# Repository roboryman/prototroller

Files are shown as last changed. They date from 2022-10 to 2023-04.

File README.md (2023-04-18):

<p align="center">
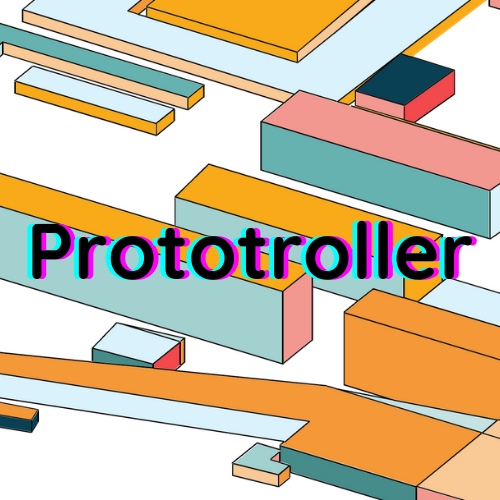
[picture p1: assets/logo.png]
  
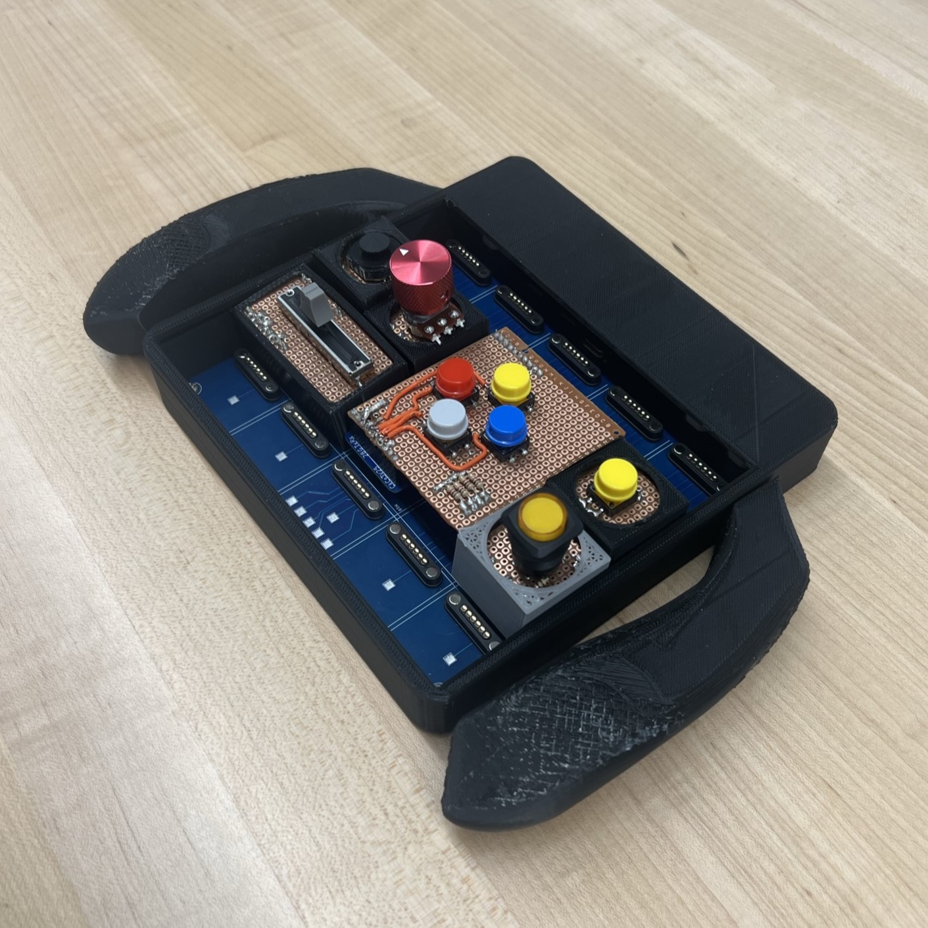
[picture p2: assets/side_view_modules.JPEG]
  
</p>

## About
The Prototroller is a ***modular*** controller that is full-stack, feature-rich, responsive, and robust. The controller could be used for any HID-compliant purpose, but we focus on developing hot-swappable modules that can form customizable gamepads.

A potential use case is general hardware level remapping for quality of life. Another is rapidly prototyping different controller layouts for games or simulations in development.

Our team consists of 5 members:
- Yu-yang Hsieh
- Britton McLeavy
- Caleb O'Malley
- Merrick Ryman
- Evan Zhang

This project is developed in conjunction with the UF CpE Capstone program (Fall 2022 - Spring 2023). This project is self-funded. As such, donations are appreciated in this educational pursuit (hardware is not cheap nowadays).

<p align="center">
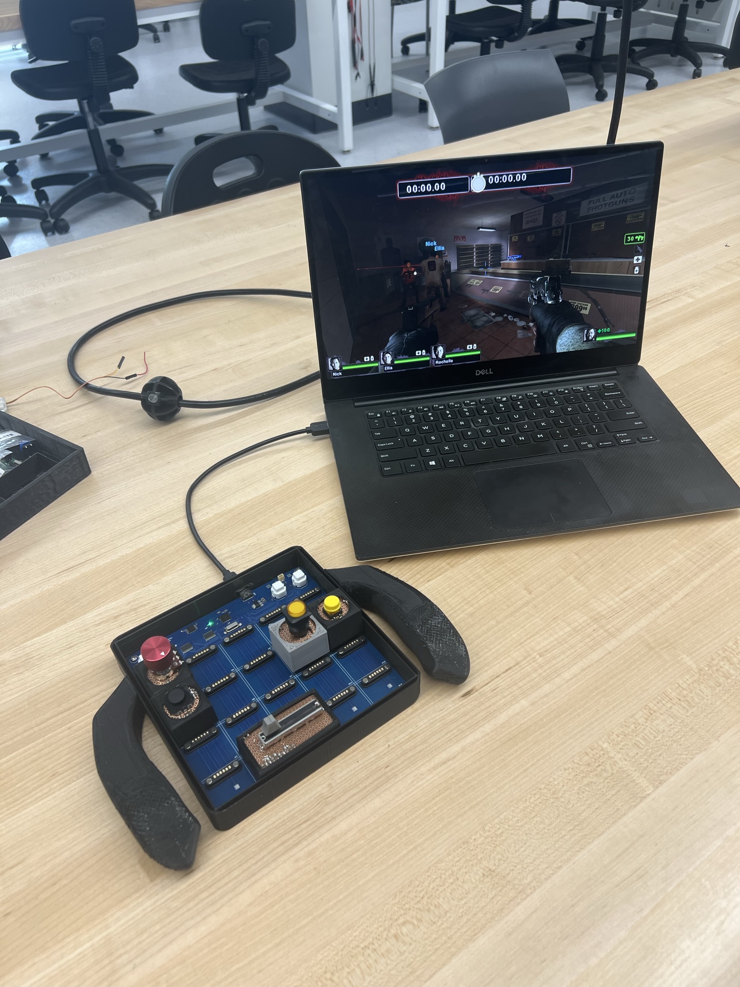
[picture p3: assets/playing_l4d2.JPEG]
  
</p>

## Architecture and Aesthetics
At the highest abstraction the Prototroller consists of the following:
- Master Board 
- Module Boards
- Component Interfaces
- Enclosures
- Firmware

### Master Board

<p>

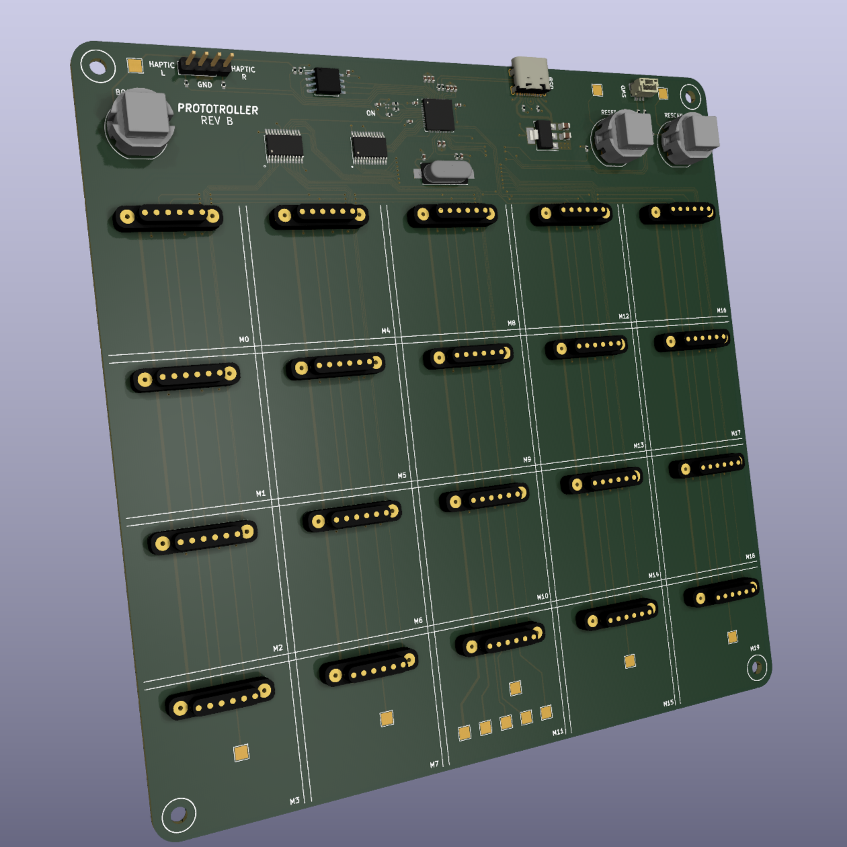
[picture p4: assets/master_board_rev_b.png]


The master board handles the data store of connected modules, transfers and receives data with modules over SPI, transfers and receives HID data over USB with the host, rescans modules, has buttons for various functions, etc. Most of the master board also serves as the the 4x5 grid of module slots the user can snap modules to using magnetic pogo-pin connectors.

<br clear="left"/>
</p>

The master board has buttons for rescanning, resetting, and flashing. There are header pins for interfacing with haptic feedback motors. A 3-pin JST-SH header (1.00mm) is available for serial wire debug. There is a USB-C receptacle (2.0) for power and data connection with the host.

The connection interface between the master board and module boards uses 6-pin magnetic pogo-pin connectors. These carry VCC, GND, and SPI signals, while maintaining a solid physical connection. The master board feeds modules with 3.3V.

### Module Boards

<p>

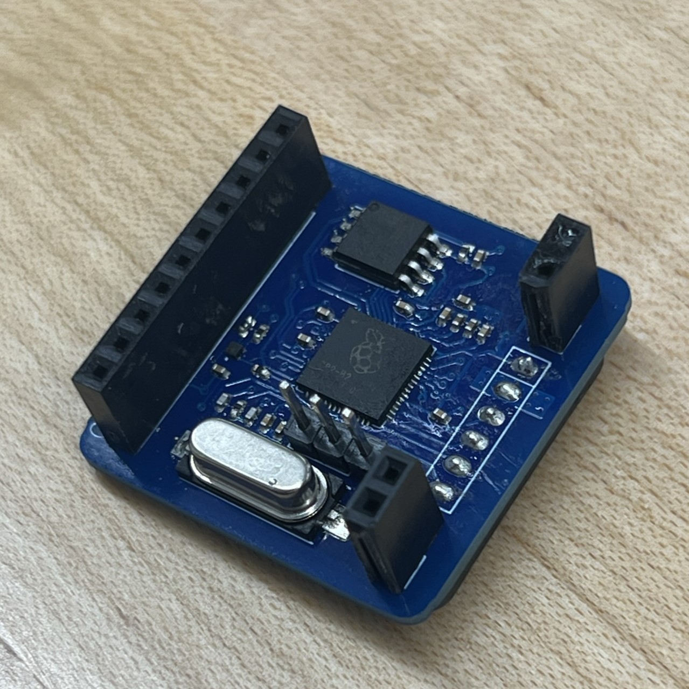
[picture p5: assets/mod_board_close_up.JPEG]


Module boards are generic and constrained at 30x30mm with no direct user interface (except for the connector and SWD headers). On the sides are headers providing 14 signals to a component interface board that would sit above. This way there are no unique module boards for each component, and we simply offload the task to the component interface board by hand.
<br clear="right"/>
</p>

### Component Interface Boards

<p>

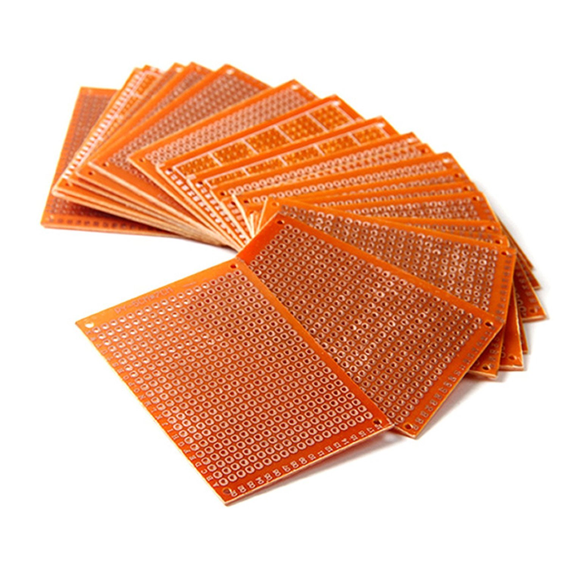
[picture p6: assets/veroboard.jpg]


The component interface boards are veroboards sitting above the module board headers. We may freely route signals from the module board to a component, the direct user interface.
<br clear="left"/>
</p>

### Enclosures

This would not be a very comfortable controller to use without enclosures.

The master board is enclosed by a chassis and grips. The master board is screwed to the chassis.

The module enclosures contain the module board and component interface boards, but do not cover the component.

<p align="center">
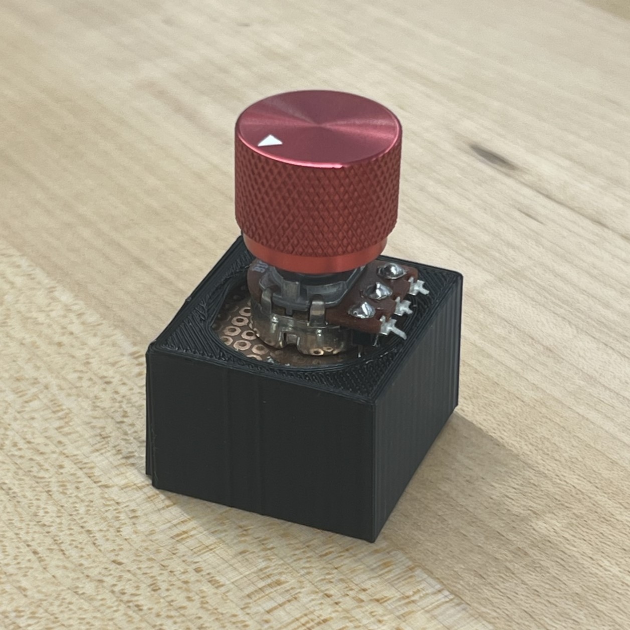
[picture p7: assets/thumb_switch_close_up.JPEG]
  
</p>

### Firmware

Each type of module has its own assosciated firmware that can be flashed via the SWD header pins with picoprobe firmware. The master board can be flashed via the normal way of "dragging" the binaries. See below for more details on flashing. The Prototroller has been extensively tested on Windows systems, but will likely work on Mac, Linux, and generally any OS that supports HID gamepads.

<p align="center">
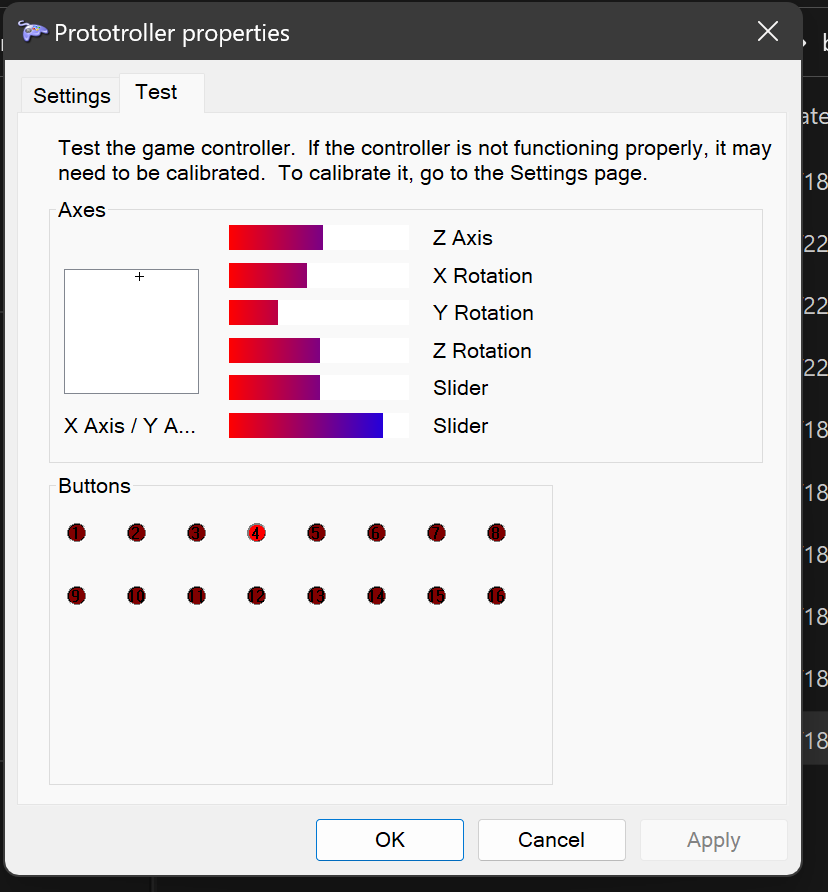
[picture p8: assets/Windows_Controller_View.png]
  
</p>

## Usage
There are a few ways you may use the Prototroller.
### _Our Hardware, Our Software_
Recommended. This combines our hardware listed above with the firmware to do the job.
The end result is a full-stack modular controller.

Our recommended PCB supplier is JLCPCB, and we are working on formalizing our recommendations for ordering.

### _Your Hardware, Our Software_
If you want to develop your own hardware to use with our software, that is excellent! In fact, we are curious to see your designs.

You may use our designs as a starting point. For example, you may want to make the modules slightly larger.

## Building and Flashing Master Boards
You may use the provided VSCode launch debug configuration and flash task. This requires a Picoprobe, OpenOCD, and Cortex Debug. Instructions are available in ```/ide```.
An easier way is to use the USB receptacle to mount and flash RP2040 binaries (.uf2), accessible by holding down BOOTSEL and performing a reset. **If you are using VSCode, you can simply edit settings.json for your SDK path, build the target, and proceed to step 5**. Otherwise, the process to generate the binary is as so:
1. Ensure you have the Pico SDK cloned somewhere, such as ```~/pico-sdk```.
2. Make and cd into a 'build' subdirectory, and export the Pico SDK path:
    ```
    $ cd prototroller
    $ mkdir build
    $ cd build
    $ export PICO_SDK_PATH=...
    ```
3. Generate the build targets:
    ```
    $ cmake -DPICO_BOARD=prototroller ..
    ```
4. Build all targets by running `make`. To build only host, master, or module targets, cd into the respective directory (generated by the cmake command above) and execute `make`. In this case, you can just `cd` into master and execute `make`.
5. This will generate the appropriate `.uf2` binaries, which can be flashed by dragging onto the mount.

## Building and Flashing Module Boards
The module boards do not have a USB receptacle. You must use SWD in conjunction with a debug probe. We recommend the official Raspberry Pi Debug Probe ($12), or a Pico flashed with the Picoprobe firmware.

Instructions are available in ```/ide```. This is how you might do it after setting up Picoprobe, OpenOCD, etc:
1. Follow the steps listed in "Building and Flashing Master Boards" to generate the binary for the module boards.
2. Connect SWDIO and SWCLK from debug probe to the SWD headers above the flash on the module board (labeled on rear silkscreen).
3. Connect a *common ground* between the Picoprobe and the module board.
4. Snap the module board to a powered master board (alternatively, supply 3V3 through the female header).
5. If you are using WSL, pass-through the Picoprobe in Powershell using ```usbipd```.
6. Use the '```Prototroller Flash```' task in VSCode, or execute the following command, where `joystick-module.elf` is the name of the ELF executable generated previously:
    ```
    sudo openocd -f interface/cmsis-dap.cfg -f target/rp2040.cfg -c "adapter speed 5000" -c "program build/module/joystick-module.elf verify reset exit"
    ```
If all went well, the module board should be flashed. You can safely remove the SWD wires and set the debug probe aside.

Documentation for the official Raspberry Pi Debug Probe:
https://www.raspberrypi.com/documentation/microcontrollers/debug-probe.html

Alternatively, here is an excellent tutorial to setting up and using Picoprobe if you have a Pico available: https://github.com/robotdad/piconotes

## Roadmap
- [x] Proof of Concept Build
- [x] Basic Master/Module Firmware
- [x] Basic Host HID Drivers
- [x] Basic Component Support
- [x] Prototype Build
- [x] Interconnect Design
- [x] Module Board Design(s)
- [x] Master Board Design
- [x] Chassis/Module Enclosure Designs
- [x] Advanced Firmware
- [x] Advanced HID Drivers
- [x] Advanced Component Support
- [x] Finalized Firmware
- [x] Prototroller Artifact
- [ ] Stretch: Wireless Support
- [ ] Stretch: Power Optimization
- [ ] Stretch: More types of modules

Ideas for future modules: Trigger, D-Pad, Accelerometer, Gyroscope, Rounded Buttons. Could also do some cool things non-gaming related, such as an IR blaster and Bluetooth TX/RX modules.
Adding new types of modules only requires the firmware and custom backpack.

## Acknowledgements
Thank you to our stakeholder Carsten Thue-Bludworth for his infinite wisdom. His assistance keeps the project grounded and evolving in the best way possible.

Thank you to Dr. Blanchard and the UF CpE Capstone program for direction and usage of lab space.

Thank you to the Raspberry Pi community for the hardware and software that made this project possible.

Thank you to Phil's Lab on YouTube for the excellent courses and tutorials on hardware design.

Thank you to user testing participants for valuable feedback. Their insights and suggestions have helped us refine our design and ensure that our final product meets the needs and expectations of its intended users.

Thank you to families, friends, and loved ones for their unwavering support and encouragement. Their belief in our abilities and commitment to our success has been a constant source of motivation and inspiration.

<p align="center">
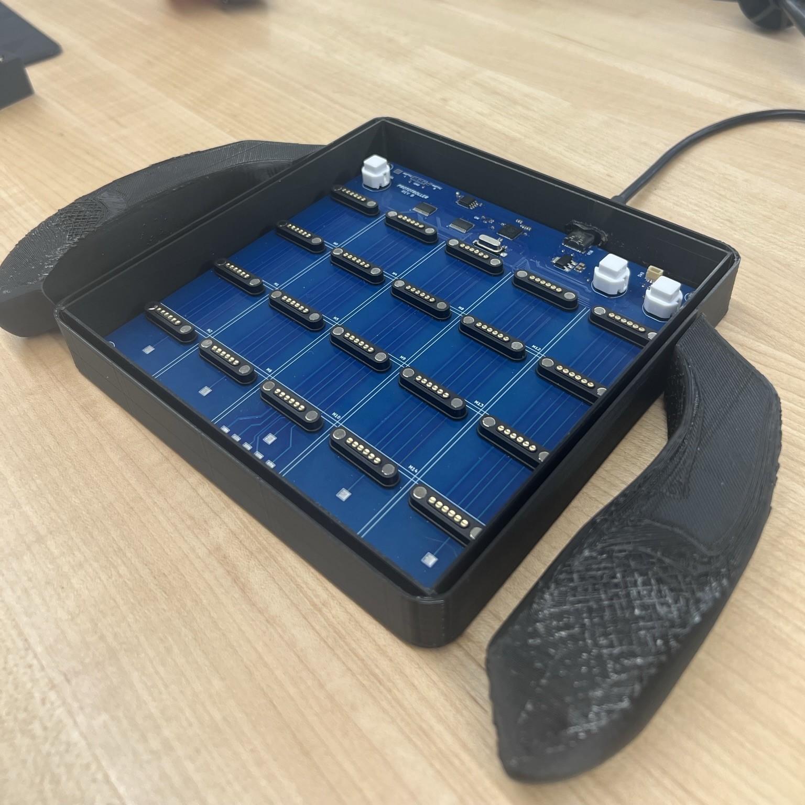
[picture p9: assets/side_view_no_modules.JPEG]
  
</p>

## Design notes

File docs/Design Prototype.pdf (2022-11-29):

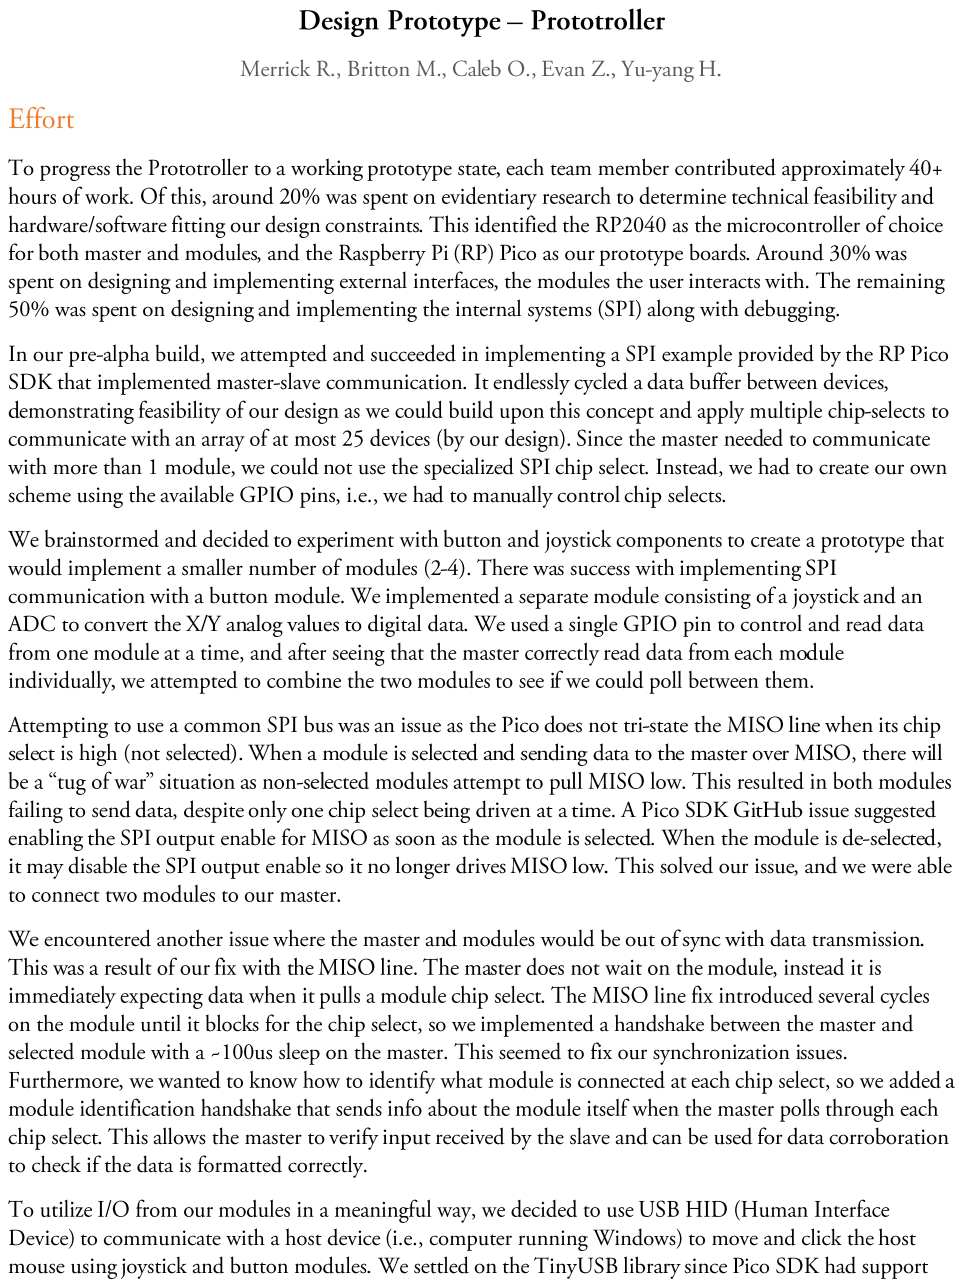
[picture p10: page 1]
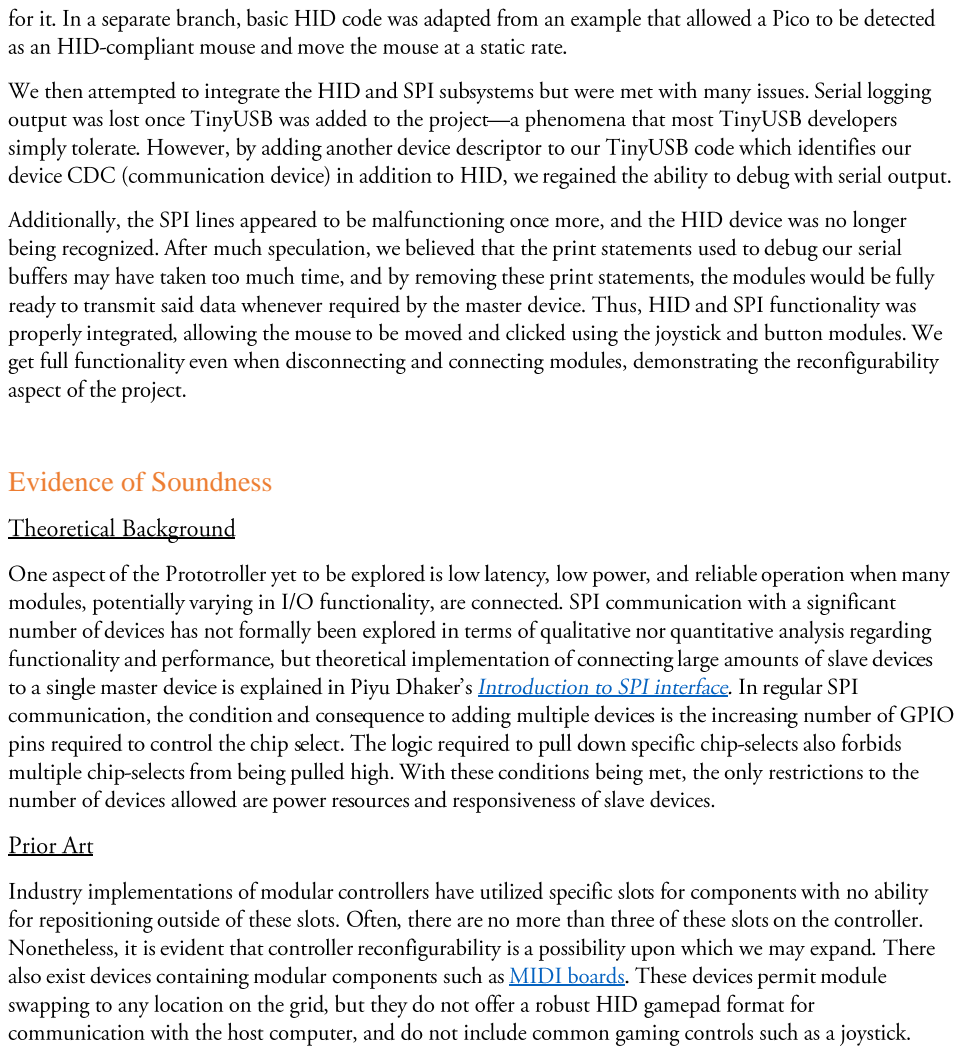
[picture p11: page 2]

## Evidence of Soundness

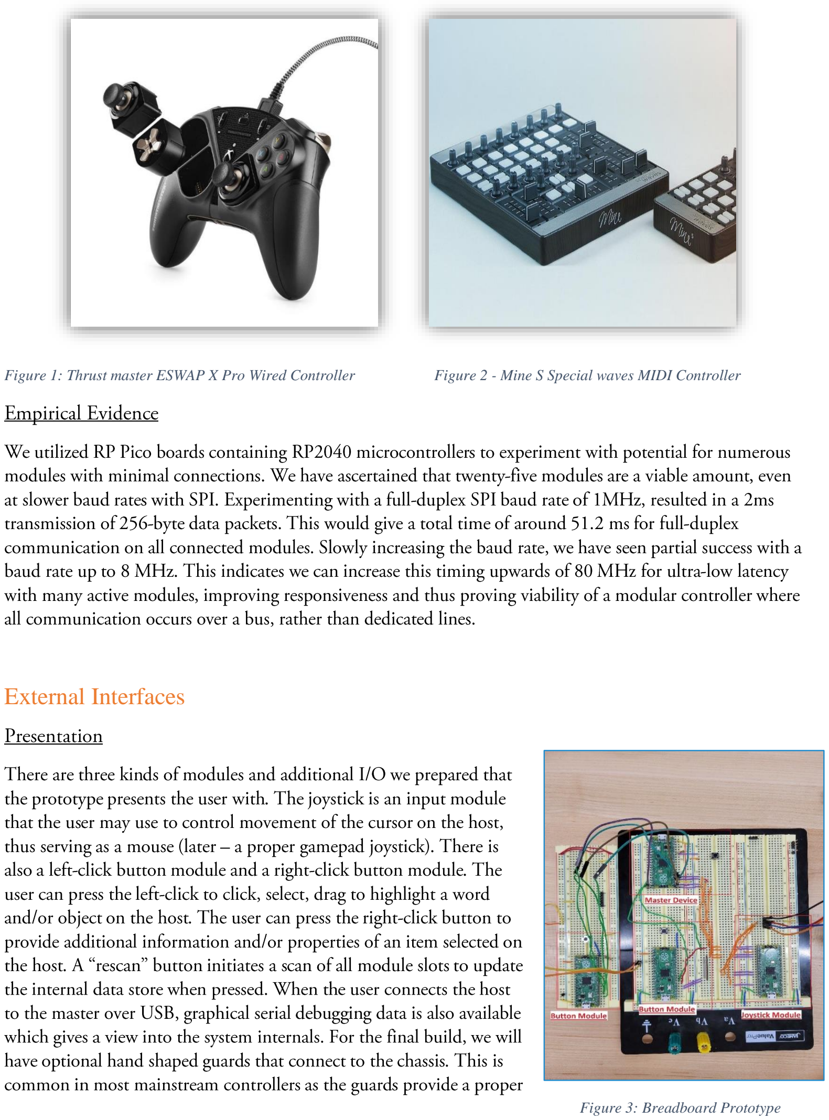
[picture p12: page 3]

Figure 1: Thrust master ESWAP X Pro Wired Controller | Figure 2 - Mine S Special waves MIDI Controller

## External Interfaces

Figure 3: Breadboard Prototype

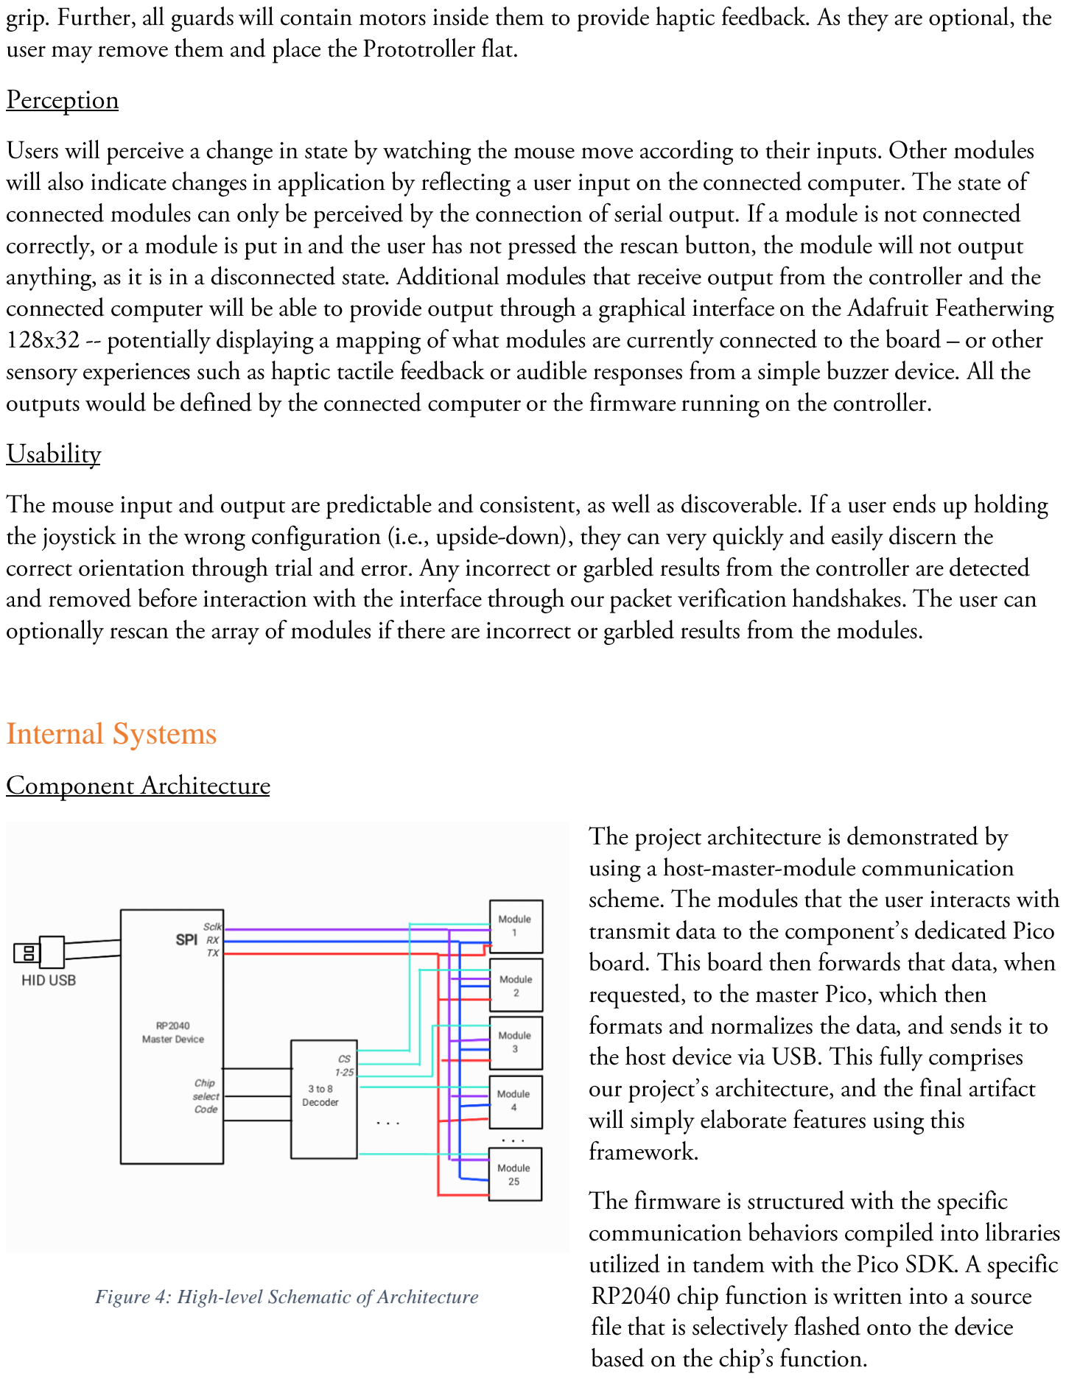
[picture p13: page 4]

## Internal Systems

Figure 4: High-level Schematic of Architecture

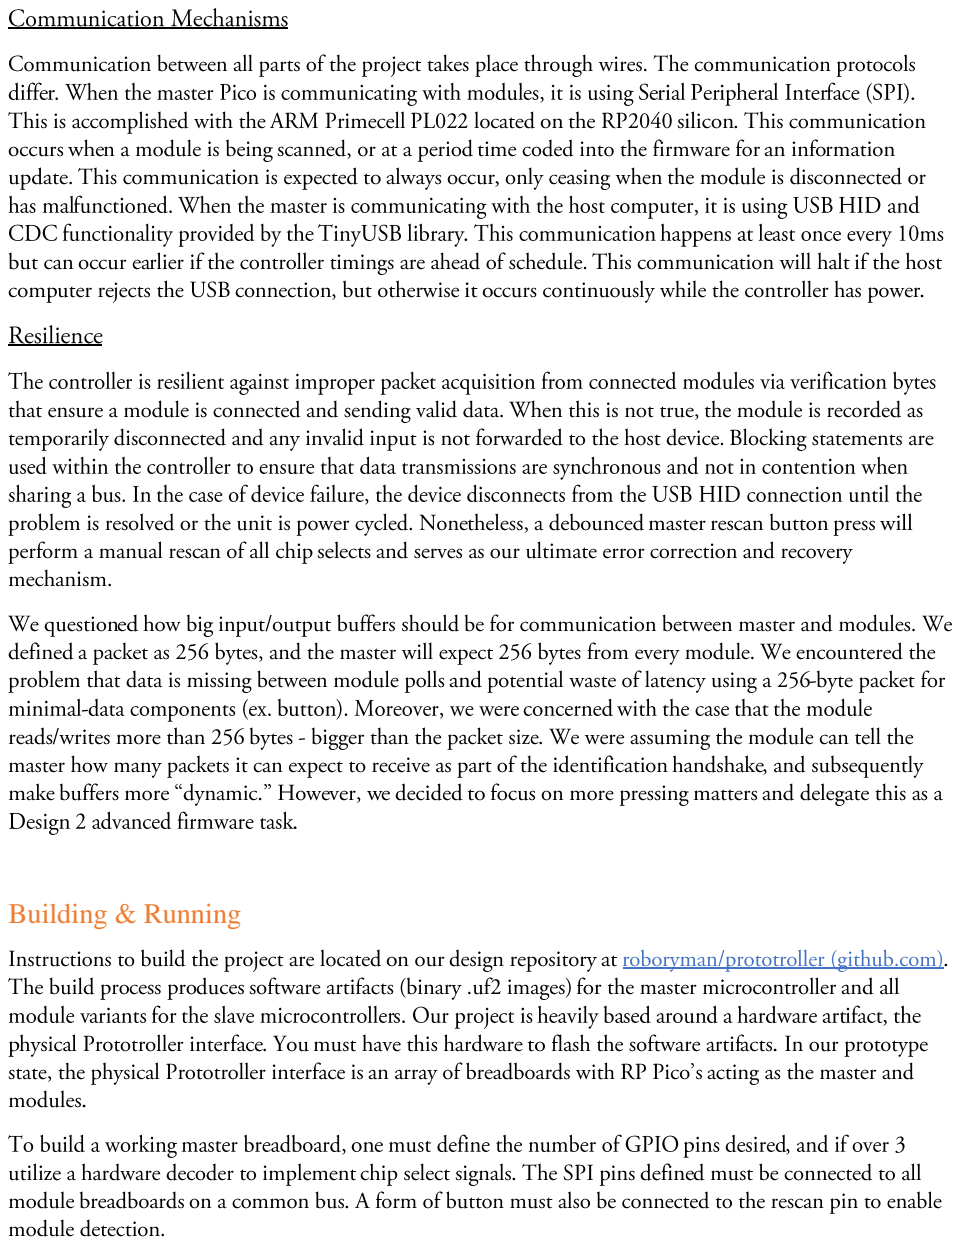
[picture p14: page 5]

## Building & Running

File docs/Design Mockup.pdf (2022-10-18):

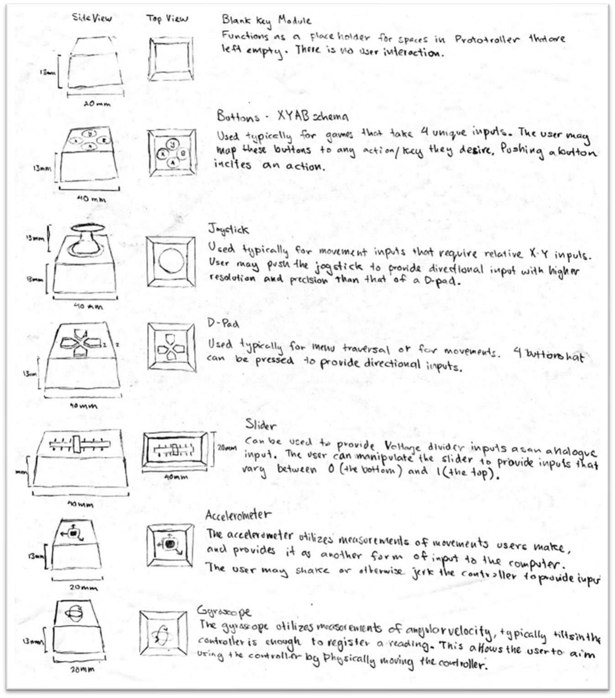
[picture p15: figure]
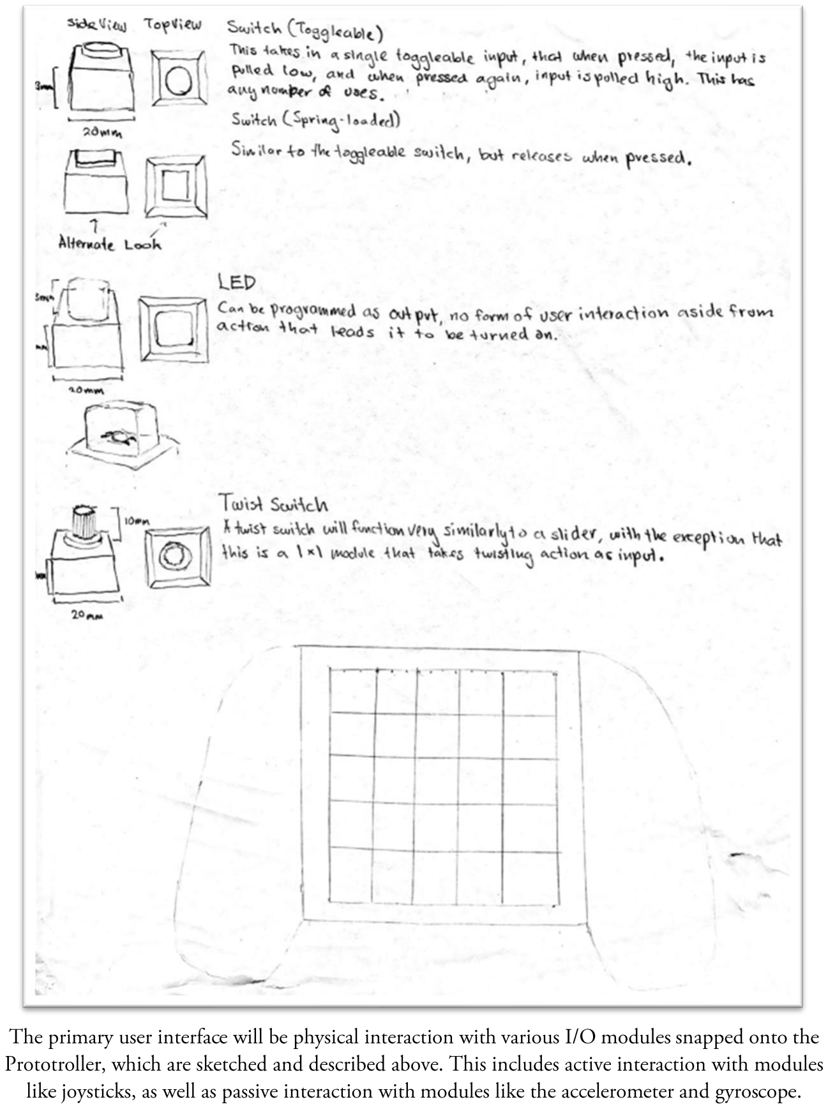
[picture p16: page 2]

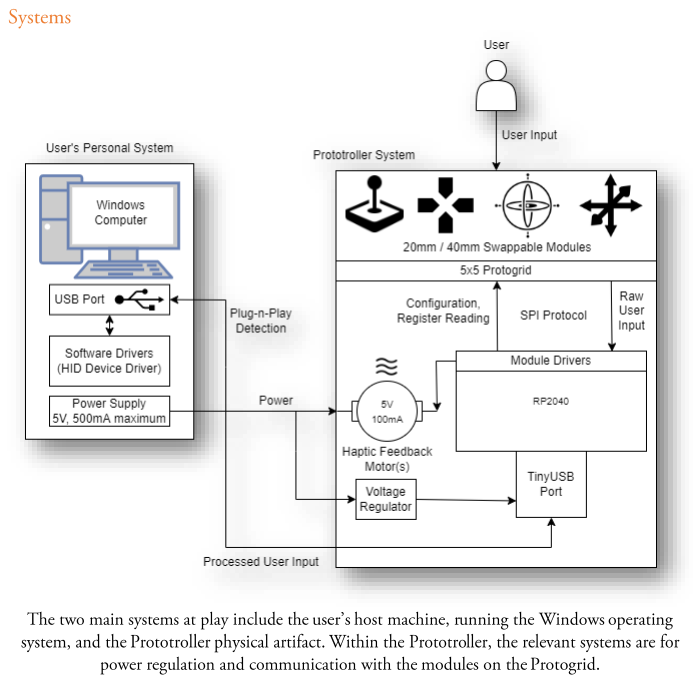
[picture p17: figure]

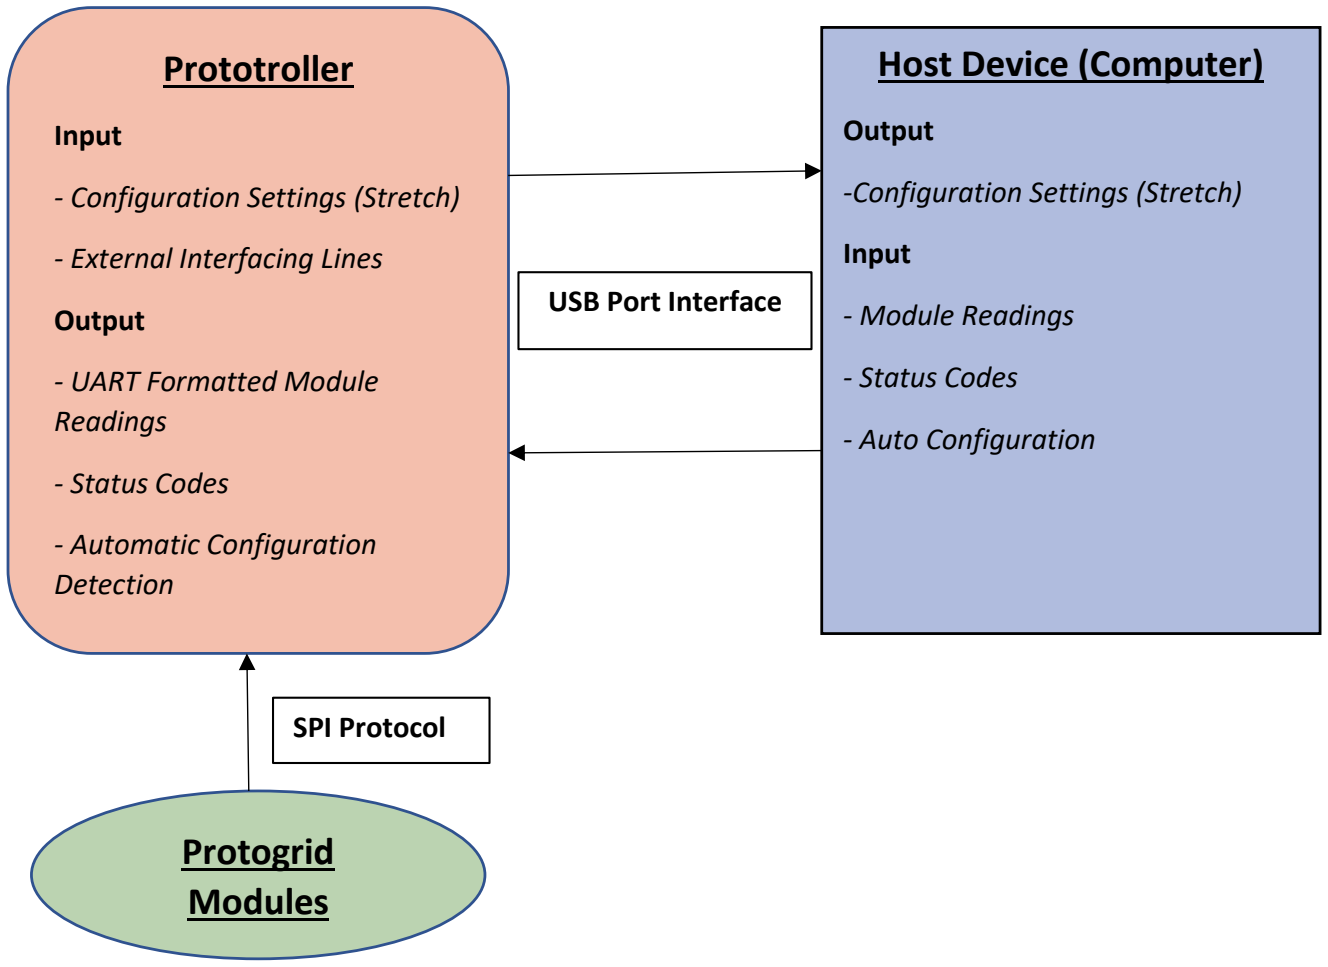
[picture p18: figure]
Host Device (Computer); Output; -Configuration Settings (Stretch); Input; - Module Readings; - Status Codes; - Auto Configuration; Prototroller; - Configuration Settings (Stretch); - External Interfacing Lines; - UART Formatted Module Readings; - Automatic Configuration Detection; Protogrid Modules; USB Port Interface; SPI Protocol
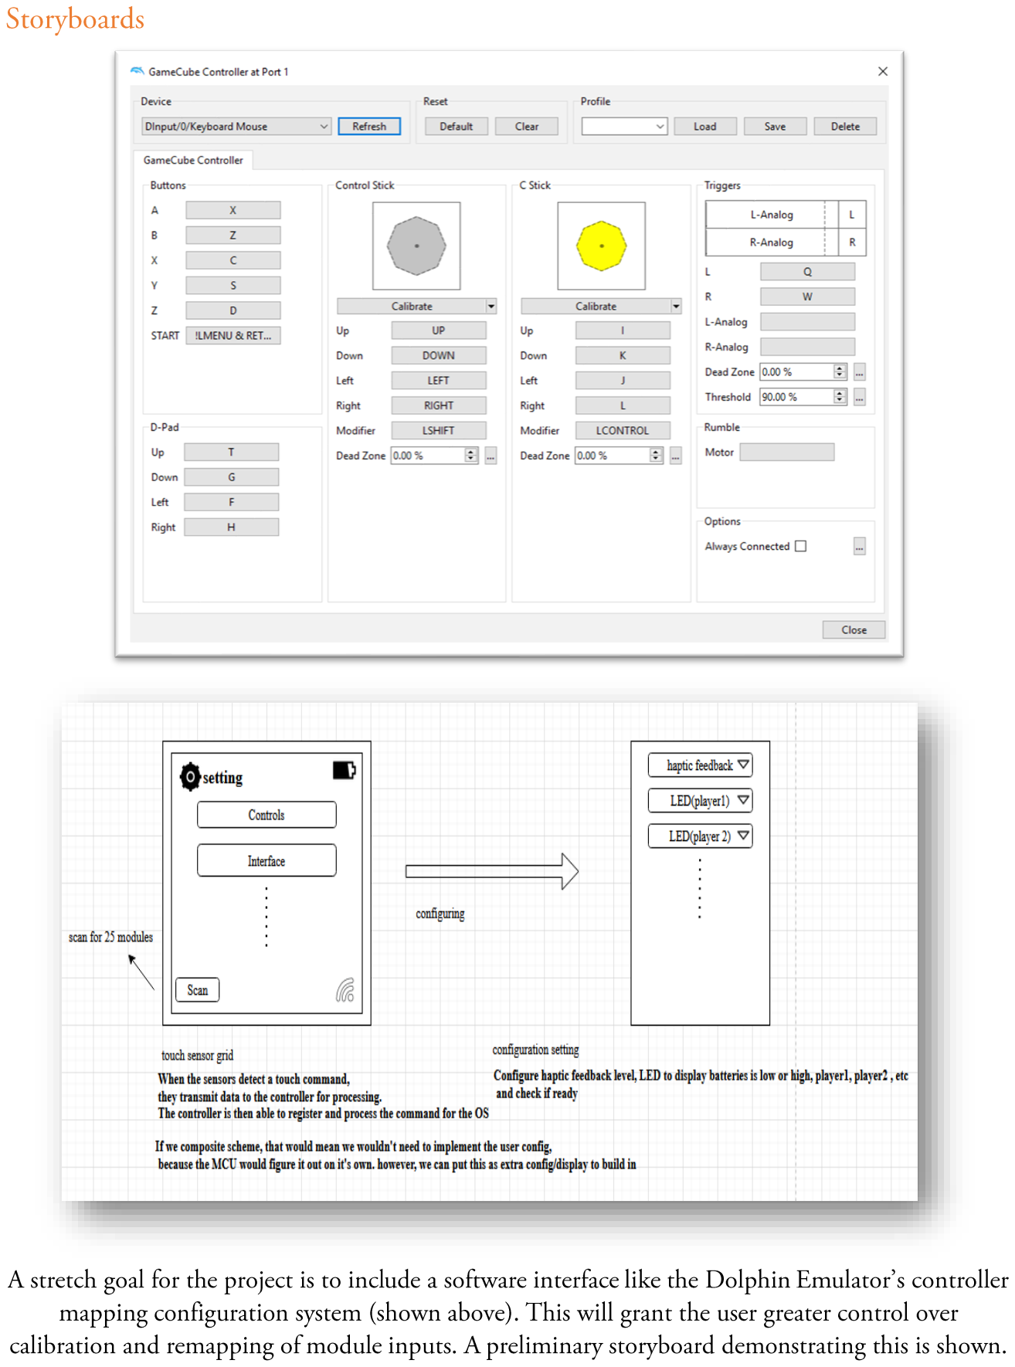
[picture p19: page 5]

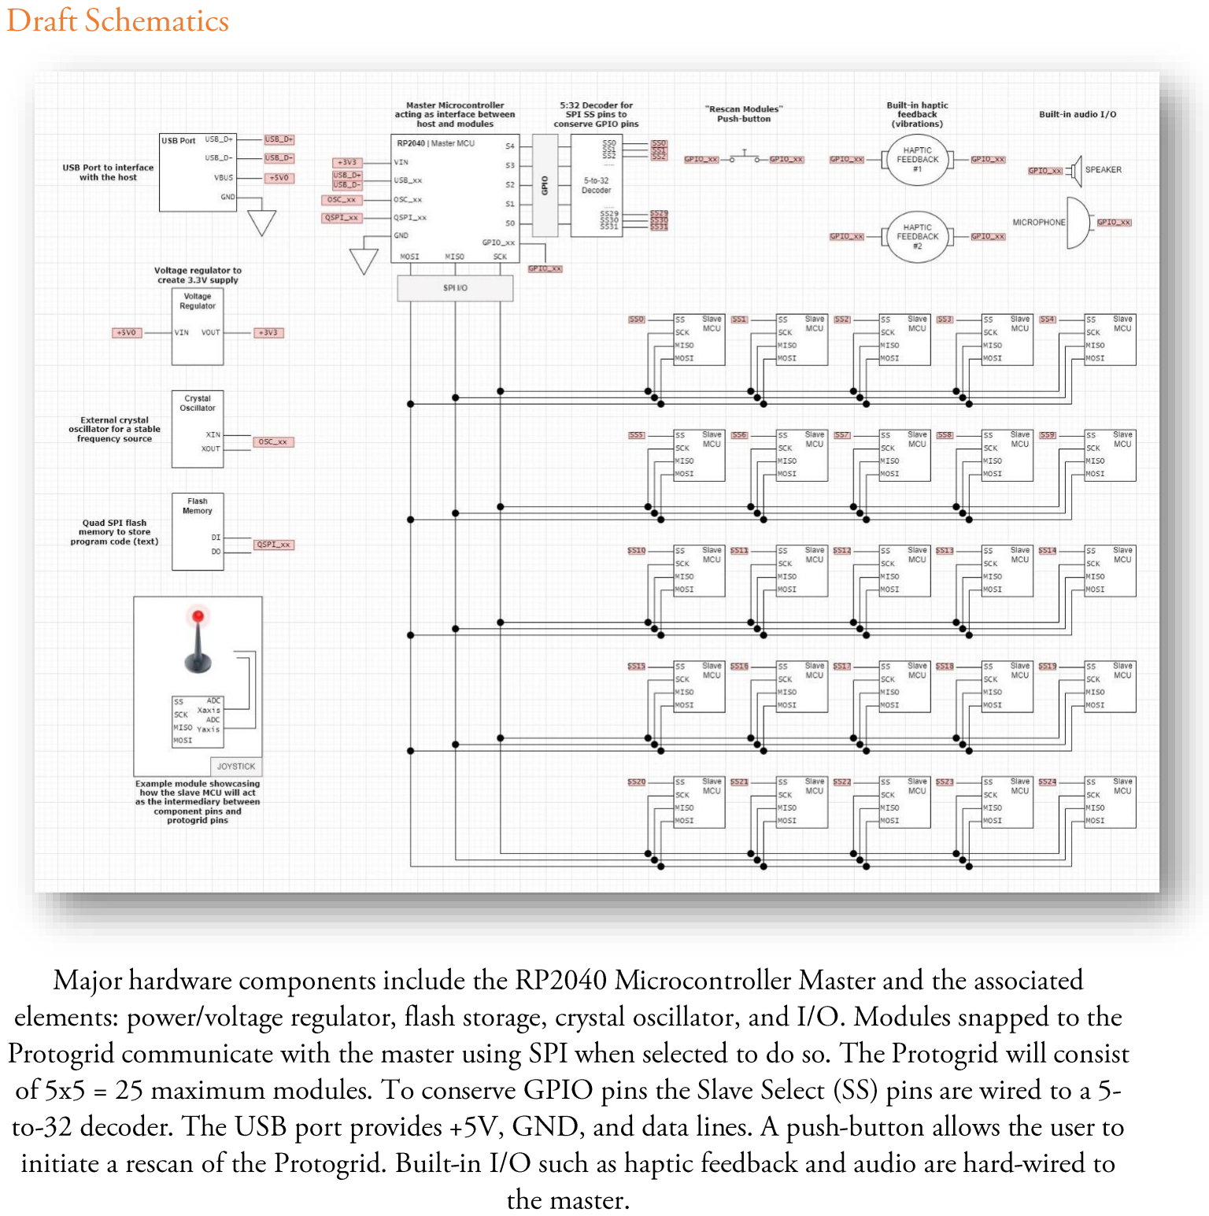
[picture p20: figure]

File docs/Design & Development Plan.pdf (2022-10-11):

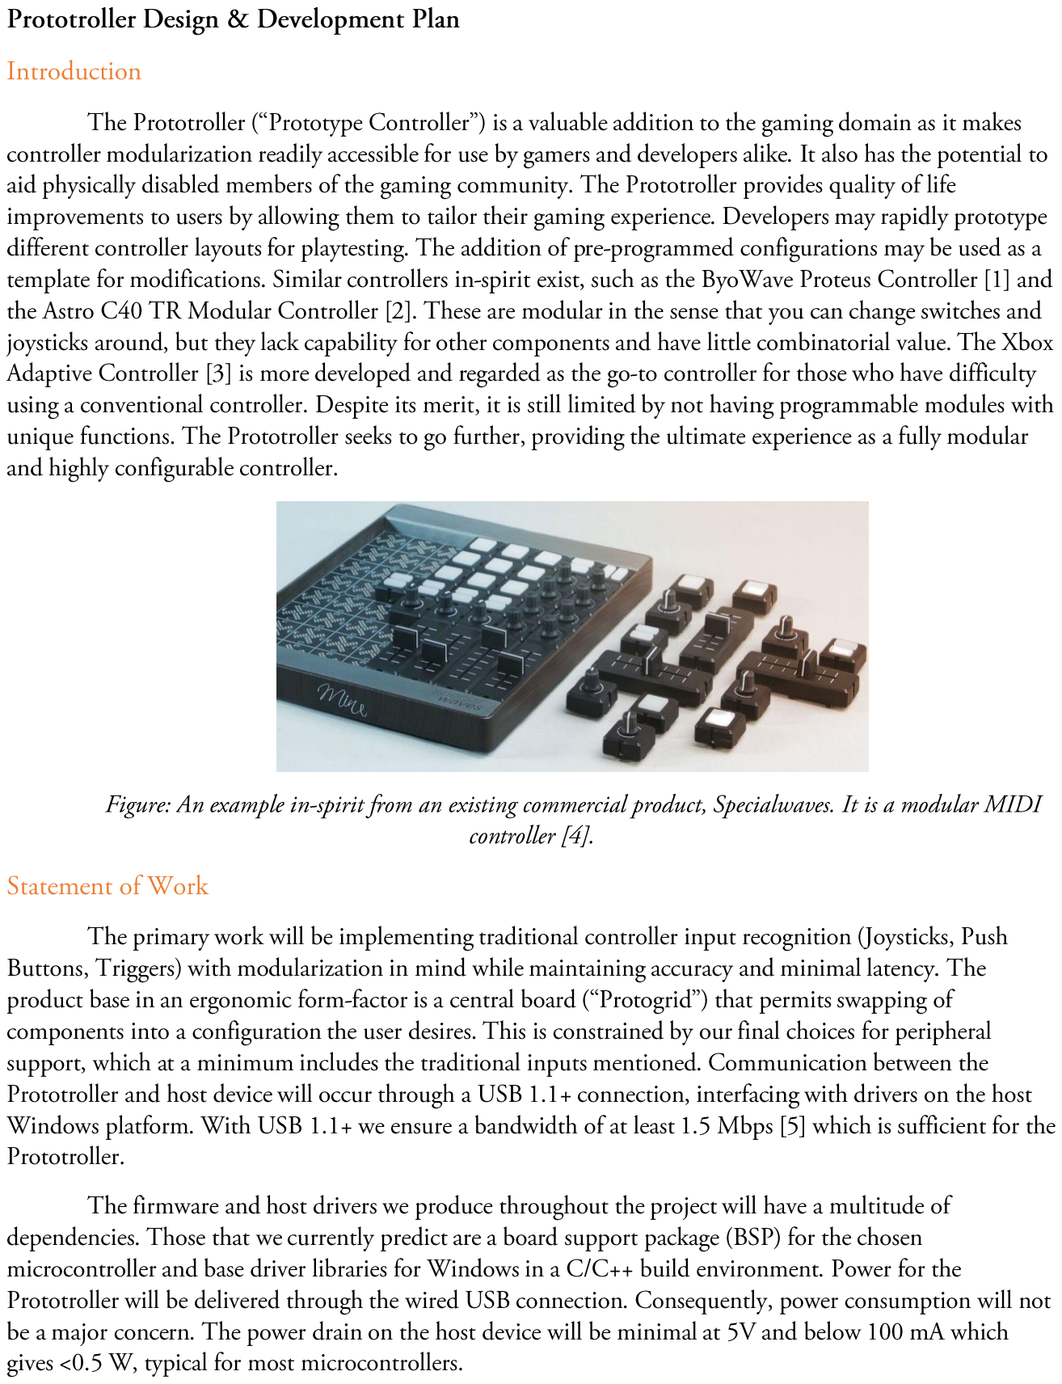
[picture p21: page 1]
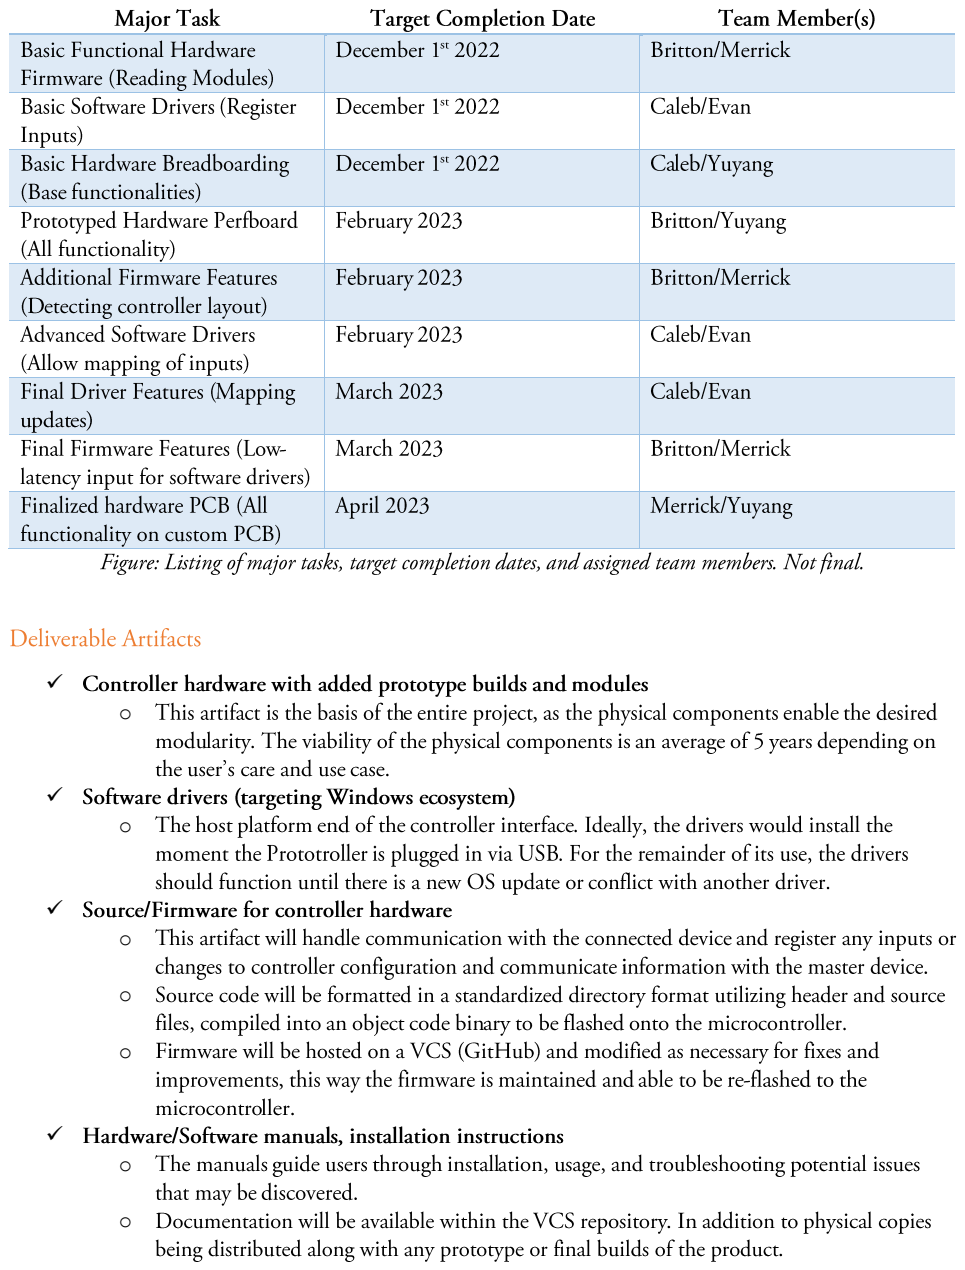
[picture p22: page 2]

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
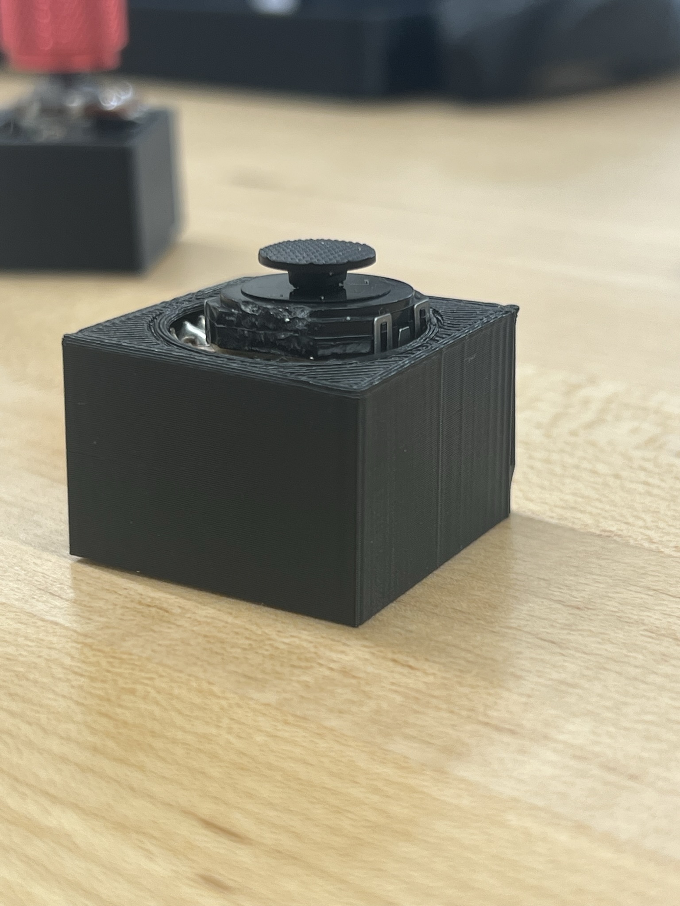
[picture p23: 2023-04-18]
assets/joystick_close_up.JPEG

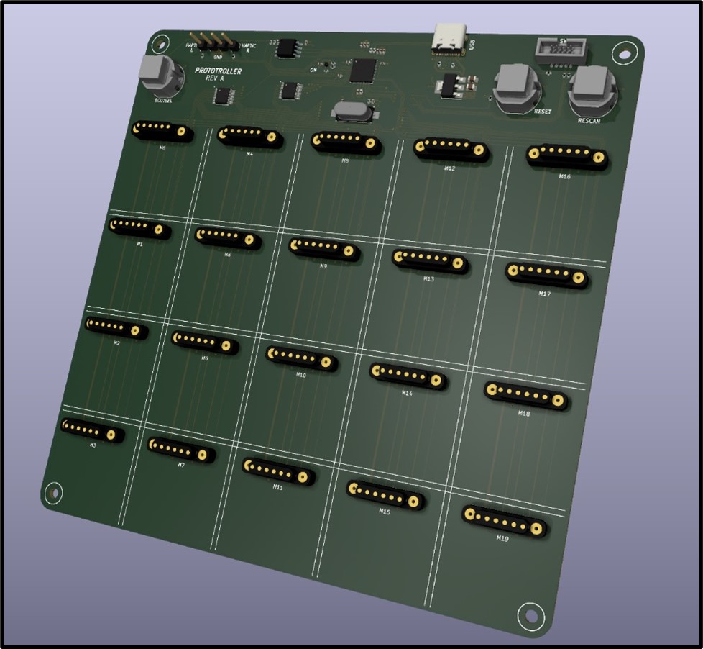
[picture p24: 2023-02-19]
assets/master_board_rev_a.jpg

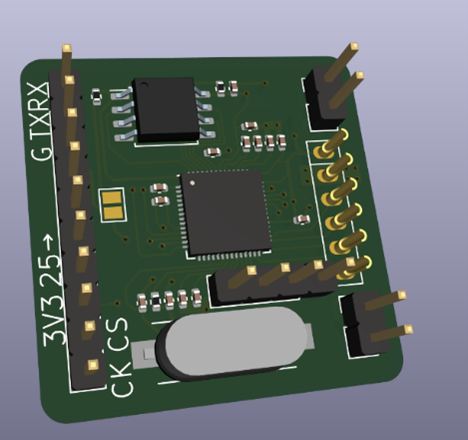
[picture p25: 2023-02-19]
assets/module_board_rev_a.png

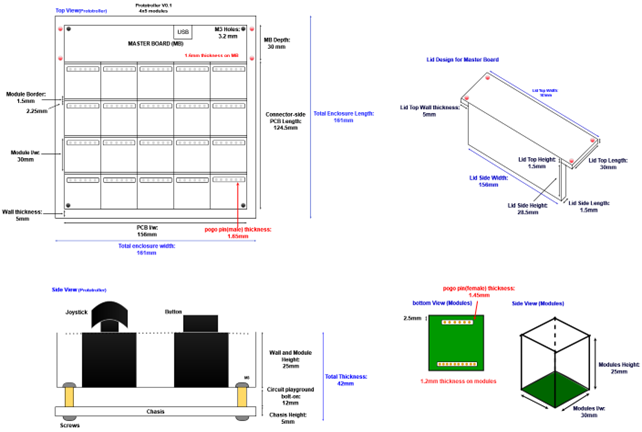
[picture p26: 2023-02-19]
assets/overall.png

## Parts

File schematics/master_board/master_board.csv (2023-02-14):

Source: | \\wsl.localhost\Ubuntu\home\merrick\prototroller\Schematics\master_board\master_board.kicad_sch
Date: | 2/13/2023 7:46:52 PM
Tool: | Eeschema (6.0.10)
Generator: | C:\Program Files\KiCad\6.0\bin\scripting\plugins/bom_csv_grouped_by_value_with_fp.py
Component Count: | 74
Ref | Qnty | Value | Cmp name | Footprint | Description | Vendor
C1, C2, | 2 | 10u | C | Capacitor_SMD:C_0805_2012Metric | Unpolarized capacitor
C3, C4, C5, C8, C9, C10, C11, C14, C15, C16, C17, | 11 | 100n | C | Capacitor_SMD:C_0402_1005Metric | Unpolarized capacitor
C6, C7, | 2 | 1u | C | Capacitor_SMD:C_0402_1005Metric | Unpolarized capacitor
C12, C13, | 2 | 27p | C | Capacitor_SMD:C_0402_1005Metric | Unpolarized capacitor
D1, | 1 | LED_RGB | LED_RGB | prototroller_footprints:LED_Cree-UHD111A | RGB LED, 6 pin package with exposed pad
H1, H2, H3, H4, | 4 | MountingHole | MountingHole | MountingHole:MountingHole_3.2mm_M3 | Mounting Hole without connection
J1, | 1 | 2x5x1.27mm | Conn_02x05_Odd_Even | Connector_PinHeader_1.27mm:PinHeader_2x05_P1.27mm_Vertical_SMD | Generic connector, double row, 02x05, odd/even pin numbering scheme (row 1 odd numbers, row 2 even numbers), script generated (kicad-library-utils/schlib/autogen/connector/)
J2, | 1 | USB_C_Receptacle_USB2.0 | USB_C_Receptacle_USB2.0 | Connector_USB:USB_C_Receptacle_GCT_USB4105-xx-A_16P_TopMnt_Horizontal | USB 2.0-only Type-C Receptacle connector
J3, J4, J5, J6, | 4 | Conn_01x01_Female | Conn_01x01_Female | Connector_PinHeader_2.54mm:PinHeader_1x01_P2.54mm_Vertical | Generic connector, single row, 01x01, script generated (kicad-library-utils/schlib/autogen/connector/)
M0, M1, M2, M3, M4, M5, M6, M7, M8, M9, M10, M11, M12, M13, M14, M15, M16, M17, M18, M19, | 20 | Conn_01x06_Male | Conn_01x06_Male | prototroller_footprints:Mag_Pogo_6P_P2.2mm_Female | Generic connector, single row, 01x06, script generated (kicad-library-utils/schlib/autogen/connector/)
R1, R2, R3, R14, R16, R17, | 6 | 1k | R | Resistor_SMD:R_0402_1005Metric | Resistor
R4, R5, R6, | 3 | 49R9 | R | Resistor_SMD:R_0402_1005Metric | Resistor
R7, R8, | 2 | 5k1 | R | Resistor_SMD:R_0402_1005Metric | Resistor
R9, R12, R13, R15, | 4 | 10k | R | Resistor_SMD:R_0402_1005Metric | Resistor
R10, R11, | 2 | 27R4 | R | Resistor_SMD:R_0402_1005Metric | Resistor
SW1, SW2, SW3, | 3 | SW_Push | SW_Push | prototroller_footprints:Switch_D6C40F1LFS | Push button switch, generic, two pins
U1, | 1 | NCP1117-3.3_SOT223 | NCP1117-3.3_SOT223 | Package_TO_SOT_SMD:SOT-223-3_TabPin2 | 1A Low drop-out regulator, Fixed Output 3.3V, SOT-223
U2, | 1 | RP2040 | RP2040 | Package_DFN_QFN:QFN-56-1EP_7x7mm_P0.4mm_EP3.2x3.2mm | A microcontroller by Raspberry Pi
U3, | 1 | W25Q16JVSSIQ | W25Q16JVSSIQ | Package_SO:SOIC-8_5.23x5.23mm_P1.27mm
U4, U5, | 2 | 74HCT154PW,118 | 74HCT154PW,118 | Package_SO:TSSOP-24_4.4x5mm_P0.4mm
Y1, | 1 | ABLS-12.000MHZ-B4-T | Crystal | prototroller_footprints:XTAL_ABLS-12.000MHZ-B4-T | Two pin crystal

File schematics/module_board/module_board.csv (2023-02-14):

Source: | \\wsl.localhost\Ubuntu\home\merrick\prototroller\Schematics\module_board\module_board.kicad_sch
Date: | 2/13/2023 7:50:45 PM
Tool: | Eeschema (6.0.10)
Generator: | C:\Program Files\KiCad\6.0\bin\scripting\plugins/bom_csv_grouped_by_value_with_fp.py
Component Count: | 26
Ref | Qnty | Value | Cmp name | Footprint | Description | Vendor
C1, C2, C5, C6, C7, C10, C11, C12, C13, C14, | 10 | 100n | C | Capacitor_SMD:C_0402_1005Metric | Unpolarized capacitor
C3, C4, | 2 | 1u | C | Capacitor_SMD:C_0402_1005Metric | Unpolarized capacitor
C8, C9, | 2 | 27p | C | Capacitor_SMD:C_0402_1005Metric | Unpolarized capacitor
J1, | 1 | Conn_01x04_Male | Conn_01x04_Male | Connector_PinHeader_2.54mm:PinHeader_1x04_P2.54mm_Vertical | Generic connector, single row, 01x04, script generated (kicad-library-utils/schlib/autogen/connector/)
J2, | 1 | Conn_01x10_Male | Conn_01x10_Male | Connector_PinHeader_2.54mm:PinHeader_1x10_P2.54mm_Vertical | Generic connector, single row, 01x10, script generated (kicad-library-utils/schlib/autogen/connector/)
J5, | 1 | Conn_01x06_Male | Conn_01x06_Male | prototroller_footprints:Mag_Pogo_6P_P2.2mm_Male | Generic connector, single row, 01x06, script generated (kicad-library-utils/schlib/autogen/connector/)
J9, J10, | 2 | Conn_01x02_Male | Conn_01x02_Male | Connector_PinHeader_2.54mm:PinHeader_1x02_P2.54mm_Vertical | Generic connector, single row, 01x02, script generated (kicad-library-utils/schlib/autogen/connector/)
JP1, | 1 | Jumper_2_Open | Jumper_2_Open | Jumper:SolderJumper-2_P1.3mm_Open_Pad1.0x1.5mm | Jumper, 2-pole, open
R1, R2, | 2 | 10k | R | Resistor_SMD:R_0402_1005Metric | Resistor
R3, | 1 | 1k | R | Resistor_SMD:R_0402_1005Metric | Resistor
U1, | 1 | RP2040 | RP2040 | Package_DFN_QFN:QFN-56-1EP_7x7mm_P0.4mm_EP3.2x3.2mm | A microcontroller by Raspberry Pi
U2, | 1 | W25Q16JVSSIQ | W25Q16JVSSIQ | Package_SO:SOIC-8_5.23x5.23mm_P1.27mm
Y1, | 1 | ABLS-12.000MHZ-B4-T | Crystal | prototroller_footprints:XTAL_ABLS-12.000MHZ-B4-T | Two pin crystal

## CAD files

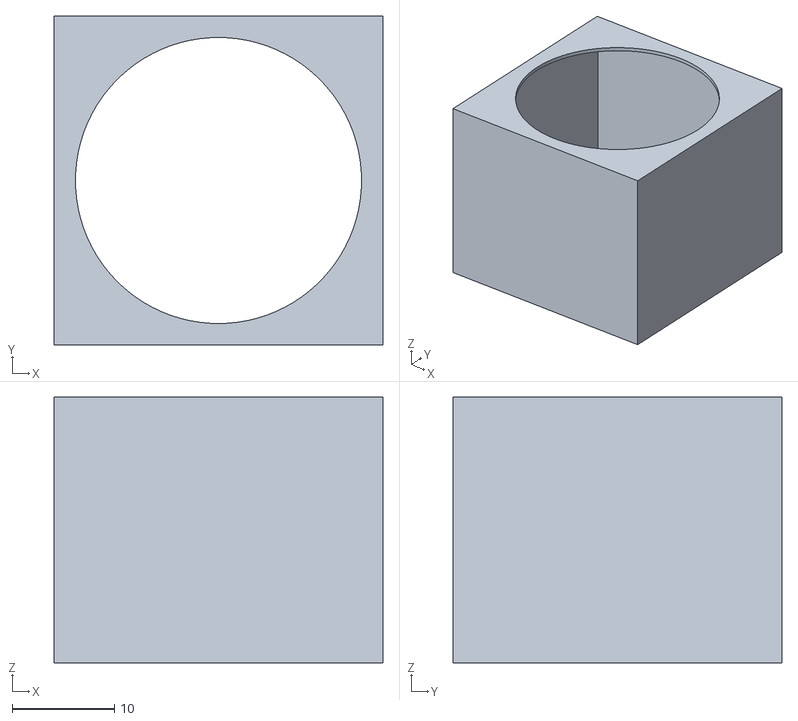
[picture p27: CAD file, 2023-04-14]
models/1x1_module_open_v1.stl
32.2 x 32.2 x 26.0

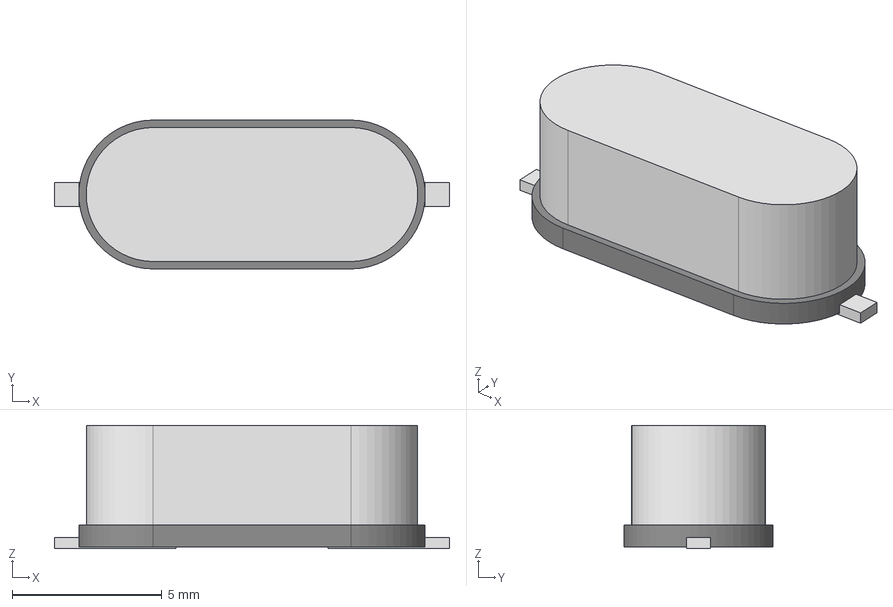
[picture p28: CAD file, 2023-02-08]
schematics/models/XTAL_ABLS_ABR.step
13.2 x 4.98 x 4.12 mm

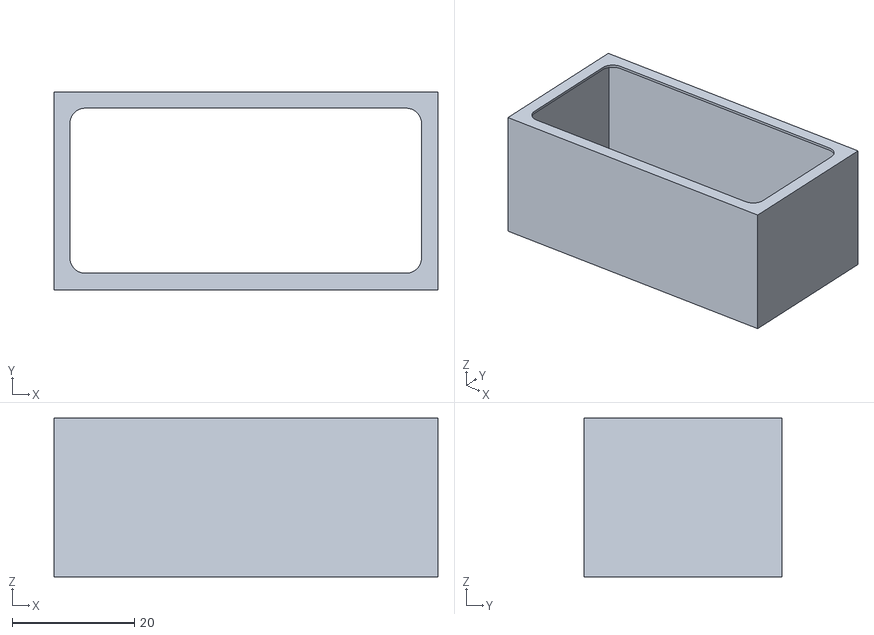
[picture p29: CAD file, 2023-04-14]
models/2x1_module_open_v1.stl
62.8 x 32.3 x 26.0

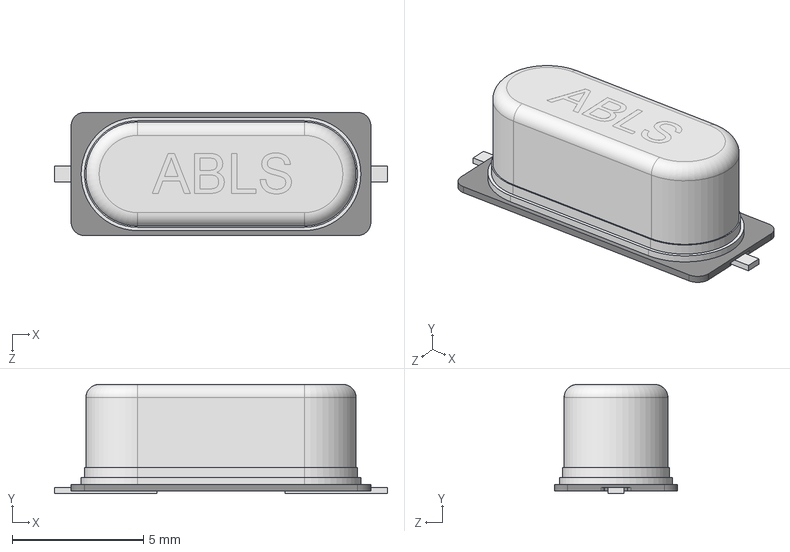
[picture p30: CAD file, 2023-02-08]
schematics/models/ABLS-12.000MHZ-B4-T.step
12.7 x 4.17 x 4.70 mm

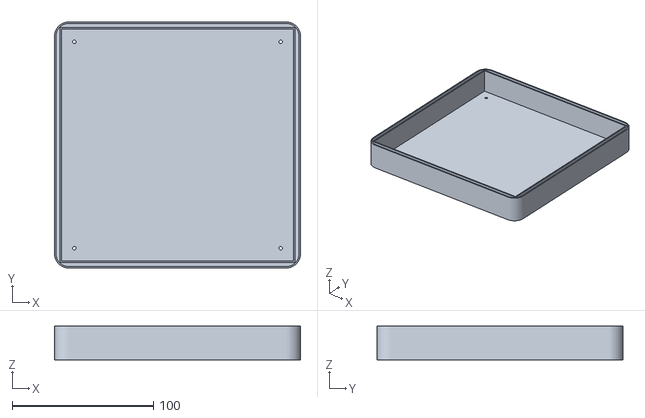
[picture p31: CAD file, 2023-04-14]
models/Chassis_Bottom_v2.stl
174.0 x 174.0 x 24.0

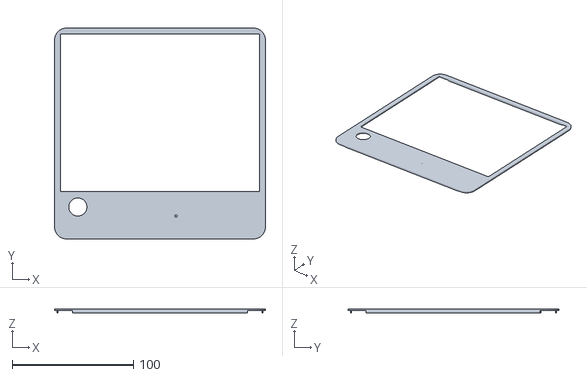
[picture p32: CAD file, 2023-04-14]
models/Chassis_Top_v2.stl
174.0 x 174.0 x 3.50

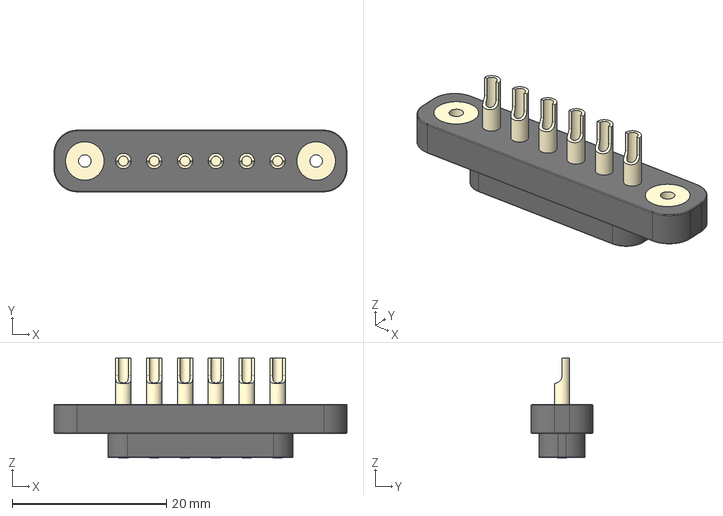
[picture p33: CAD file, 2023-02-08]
schematics/models/868-10-006-00-011101.step
38.0 x 8.00 x 12.9 mm

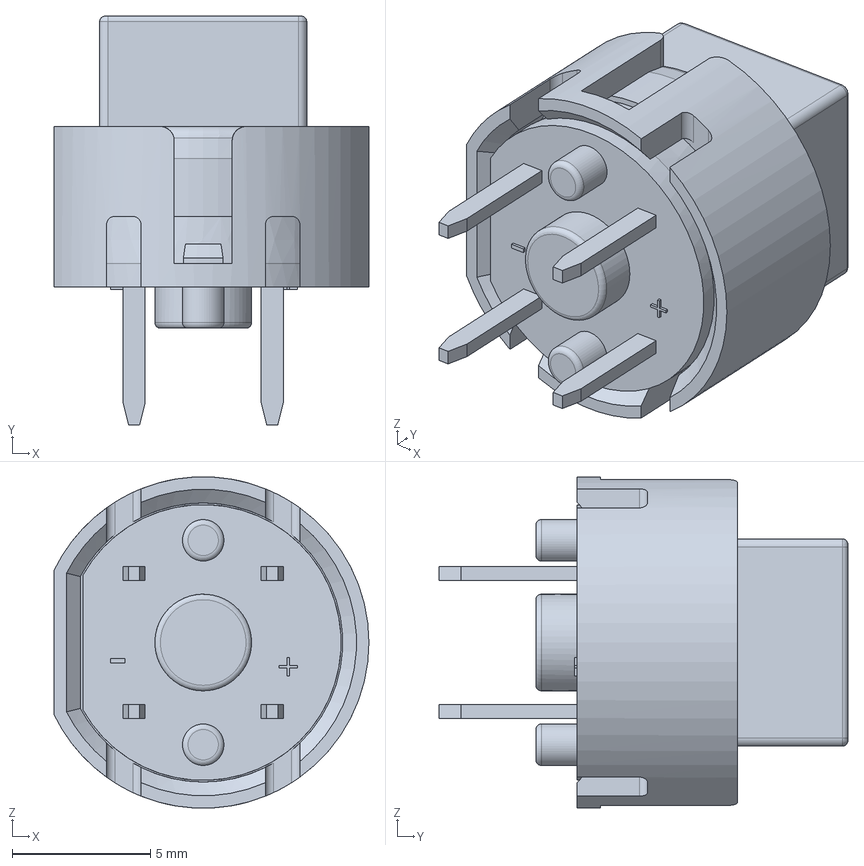
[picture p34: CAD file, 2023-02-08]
schematics/models/D6C40F1LFS.stp
11.4 x 14.8 x 12.0 mm

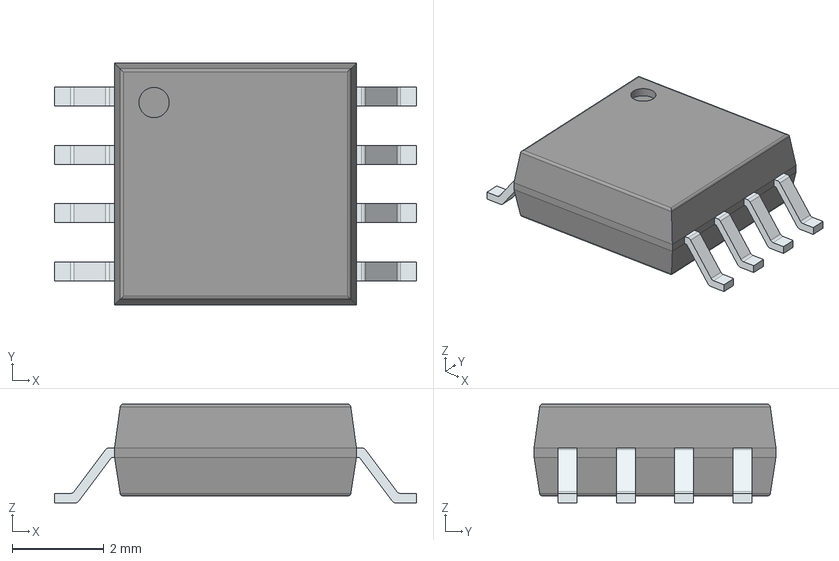
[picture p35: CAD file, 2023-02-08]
schematics/models/W25Q16JVSSIQ.stp
7.90 x 5.28 x 2.16 mm
PinsArrayLR

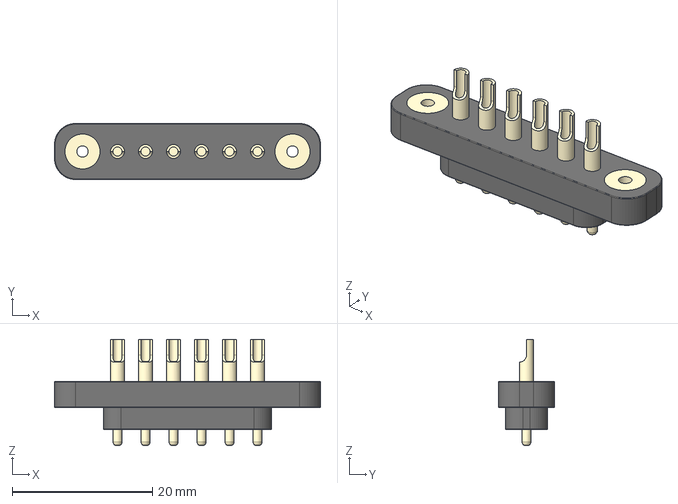
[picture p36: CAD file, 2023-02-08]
schematics/models/868-22-006-00-011101.step
38.0 x 8.00 x 15.2 mm

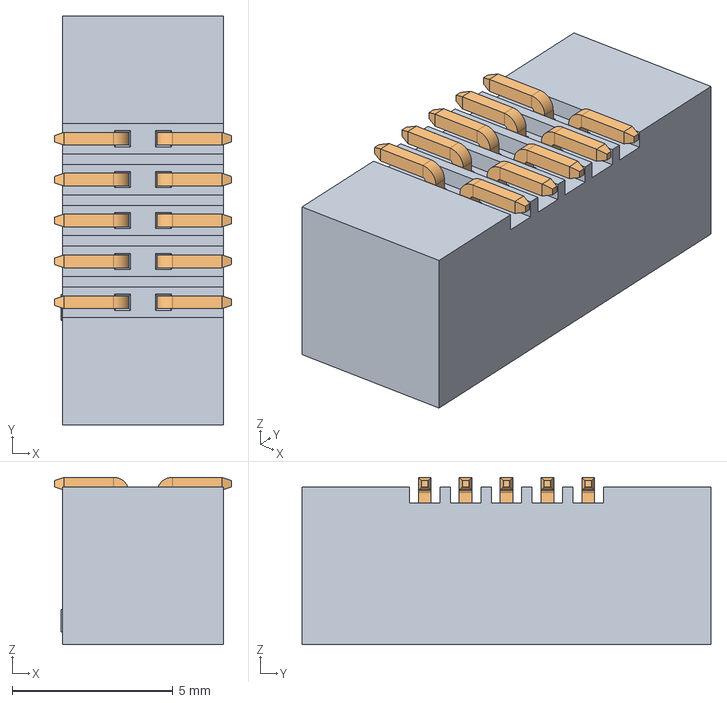
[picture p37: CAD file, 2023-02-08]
schematics/models/3220-10-0300-00 3D.stp
5.50 x 12.7 x 5.20 mm
802-2195SM-XXG x 10

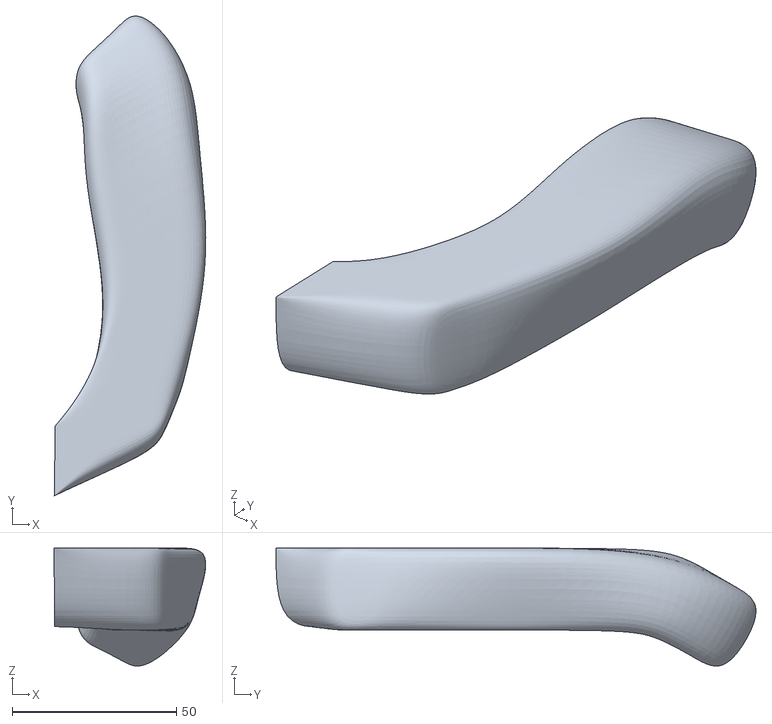
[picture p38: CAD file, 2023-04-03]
models/Chassis_Handle_L_v0.stl
46.2 x 146.3 x 35.9

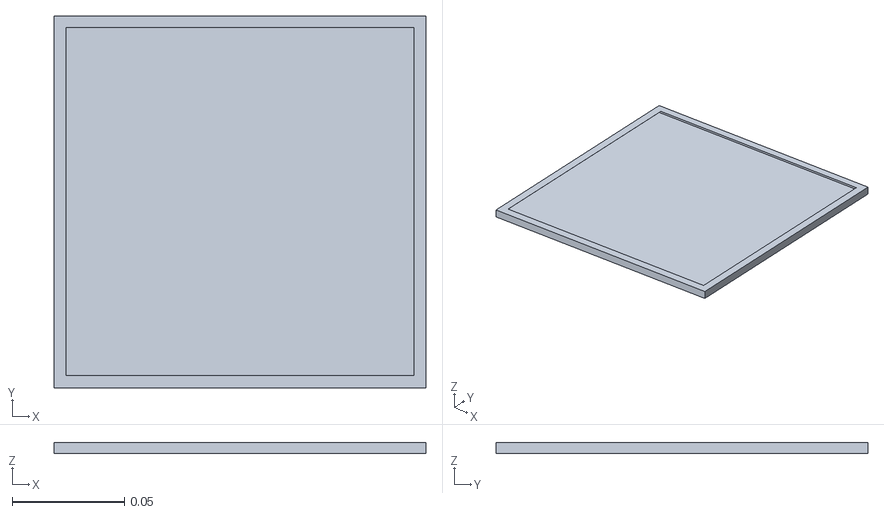
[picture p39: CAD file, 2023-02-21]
models/chassis.stl
0.166 x 0.166 x 0.005

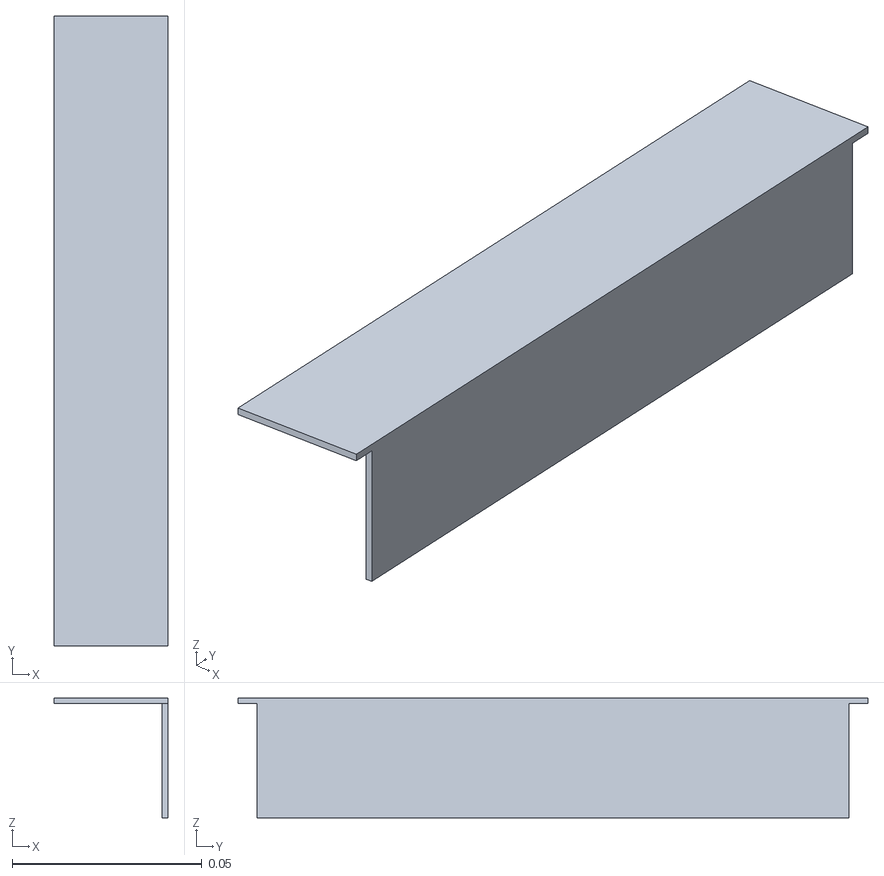
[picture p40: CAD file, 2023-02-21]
models/chassis_lid.stl
0.03 x 0.166 x 0.0316

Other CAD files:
models/Chassis_Handle_R_v0.stl
models/enclosure.stl
models/Chassis_Top_v1.stl
models/1x1_module_open_v0.stl
models/2x1_module_open_v0.stl
models/Chassis_Bottom_v0.stl
models/Chassis_Bottom_v1.stl
models/Chassis_Top_v0.stl
models/Master Enclosure v13.f3d

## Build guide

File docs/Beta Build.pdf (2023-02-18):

### Beta Build – Prototroller

Britton M., Caleb O., Evan Z., Merrick R., Yu-yang H.

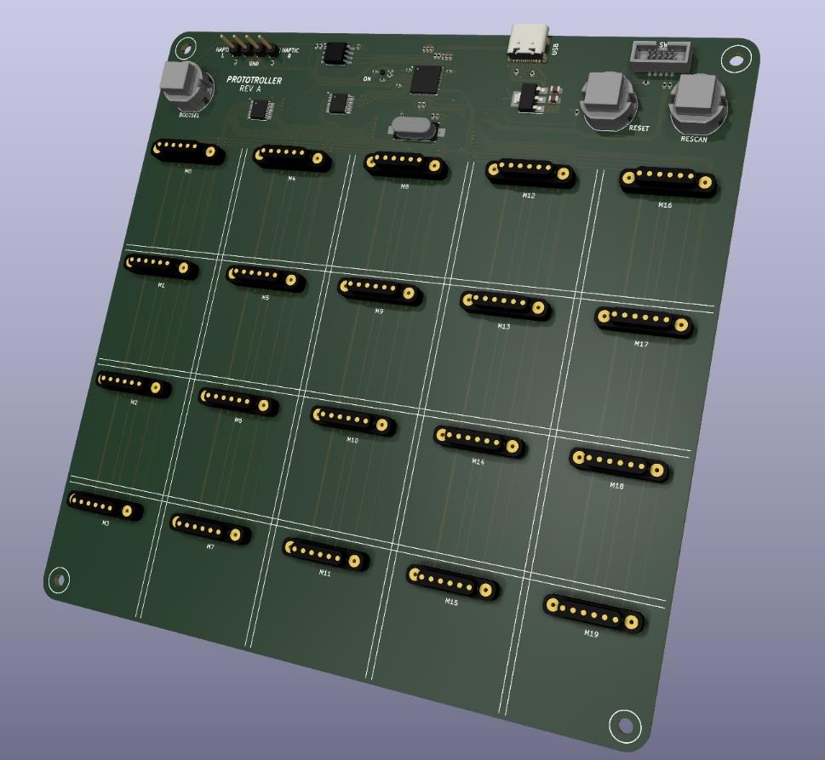
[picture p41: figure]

Figure 1: Completed PCB Prototroller Master Board.

### Usability

Interface

Users interact with modules, placeable anywhere on a 4x5 “Protogrid” through magnetic pogo-pin connections. Data is forwarded from modules to the master board, which drives gamepad HID reports to the host through USB (Universal Serial Bus) 2.0 connection. We have created 3D printable enclosure models for all aspects so the user may grip the Prototroller with ease. Serial logging is available and may be inspected with a program
like PuTTY. We have put much effort into schematic
design, PCB design, and overall aesthetic design. The
modules we currently support is joystick, push-button, tactile switch, slider, XYAB button array, accelerometer/gyroscope, with plans for more. On the master board side, we have several user interfaces: RGB LEDs for power and status indication; large buttons for programming, reset, and module rescanning; USB-C port; haptic feedback headers; and finally, SWD headers for debugging.

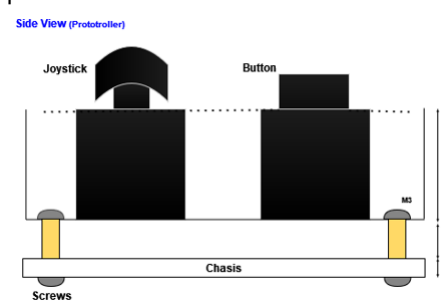
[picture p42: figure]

Figure 2: Module interfaces showcasing joystick and push-button.

Navigation

User mechanics are functional, and controls are in a good place to be tested in the Beta Testing phase. All controls, including master board interfaces and module components themselves, were designed to be predictable and easy to use. Features are discoverable through testing and especially through placement of swappable modules. Navigation comes naturally to both those who have never used a gamepad before and experienced gamers.

Perception

The Prototroller is highly intuitive. Simply plug in the desired module in the desired slot, and interact with it, indicating changes in application by reflecting a user input on the connected host. If a module is not connected correctly, or a module is inserted and no rescan occurred, the module will be in “disconnected” state (interaction proves futile). The state of connected modules can be observed by serial output, but if a module is unresponsive the user may initiate a rescan or reset. Some sensory experiences are haptic tactile feedback or audible responses from buzzers integrated into the chassis. All outputs would be defined by the connected computer or the firmware running on the controller.

Responsiveness

We use high frequency 12MHz crystals on both master and module boards. This clock speed enables sufficient controller responsiveness, from the time a user interacts with a module to the time an effect is seen on the host. However, we will continue to optimize the system for minimal latency by utilizing PLLs. Due to the unique notion of modularity, optimizing latency for all modules proves to be difficult. Our goal is to match modern controller responsiveness of around 4ms.

### Build Quality

Robustness

Modules will conjoin with the chassis using magnetic pogo-pin connectors, making the event of modules falling out unlikely. The pogo pins - in addition to a 3D printed support, will be used to firmly secure the module to the board whilst simultaneously making it just as difficult to remove under different circumstances without the use of hands.

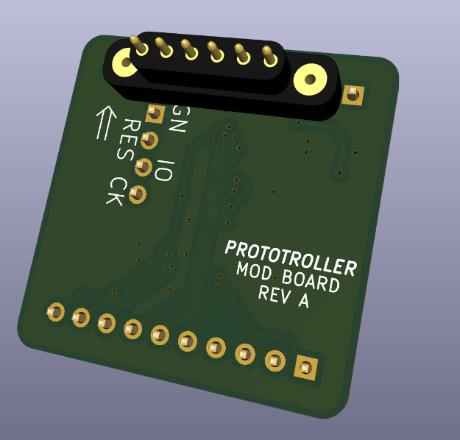
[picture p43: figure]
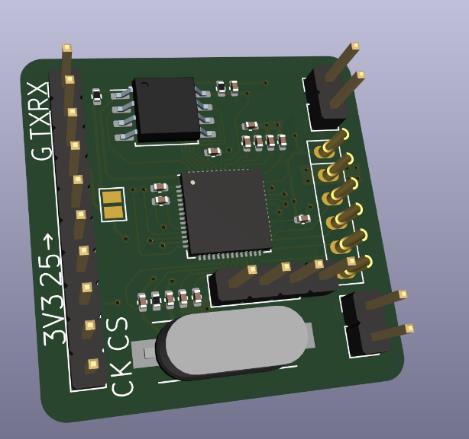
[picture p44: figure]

Figure 3: Module PCB Render – Note the magnetic POGO pins for connection to Master board.

The casings (on both chassis and modules) will be engineered to protect against drops from heights from 5 feet and below. The quality of inputs to the master, and hence, the host, is entirely dependent on the quality of connections in the PCB and peripherals used.

In terms of firmware and drivers, the target SPI speed is sufficient to routinely poll all modules with minimal issue. The transactions will send packets of data between the module and master and employ error-checking to determine that the data is formatted correctly. All firmware is designed to be fault-tolerant, that is, able to recover from expected or unexpected faults. Additionally, the user is given the option to reset the master board with a dedicated button. Our experience with the prototype build was that bugs are rare, but more work must be done once the hardware is in.

Our board designs use decoupling capacitors for local energy storage in case of power draw spikes, as well as generic RLC filters to create a barrier against undesirable frequencies in signals. This ensures that the Prototroller is sturdy enough to handle incidental discharge of electricity or potential outages.

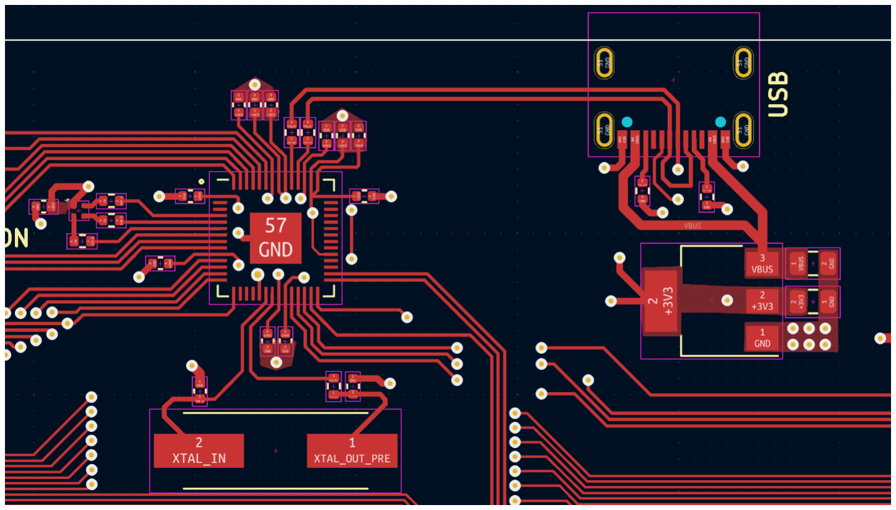
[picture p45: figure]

Figure 4: PCB Design for the Prototroller Master Board contains protection circuitry and decoupling capacitors both located at USB power rails and primary power pins of the RP2040 IC.

Consistency

The Prototroller is a real-time predictable system that should not have any issues with inconsistent inputs. Our SPI data transmissions and HID reports will contain predictable information with a set buffer size. The system will be connected through USB and shall not draw more than 500mA through the port. A rescan button will be visible and pushing it will trigger a module rescan on all slots. Doing so will have all modules synced up with the master board. A reset button will restart the currently flashed program for the respective module. All modules will have a respective output in respect to their input due to their simple functionality and should consistently yield the same results — barring hardware failures that cannot be controlled.

Aesthetic Rigor

The design allows for inputs to be handled simultaneously (i.e., with both hands) to give the same feeling of using a controller. The chassis will be assembled in an ergonomic manner to feel akin to using modern controllers. Modules mount securely to their own physically secure enclosures. For future builds we plan to incorporate grips to complete the gamepad aesthetic. Overall, there is sufficient integration of all assets to be functional, easy to use, and stable.

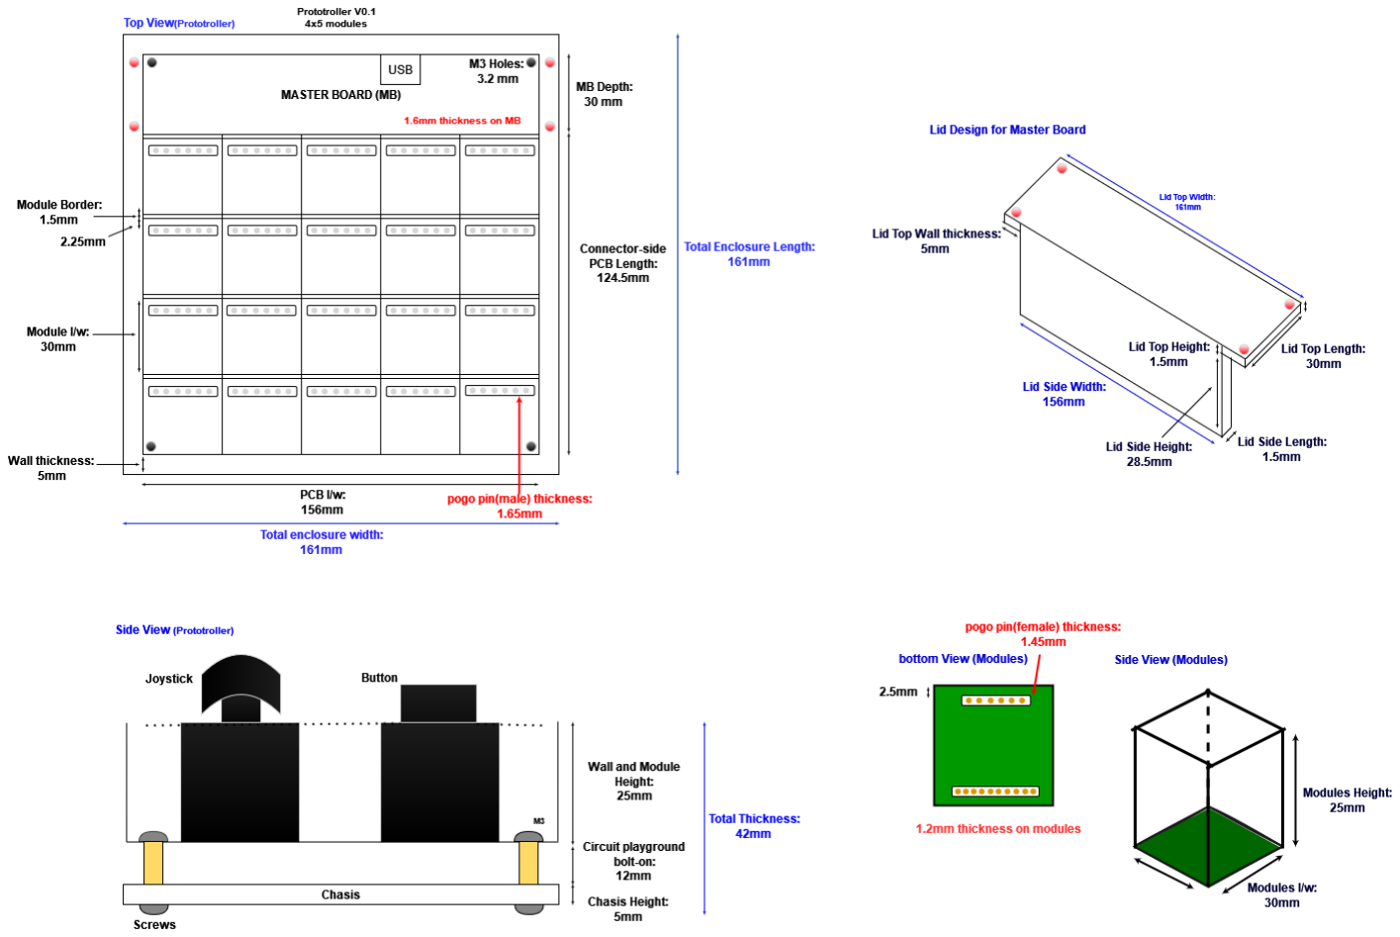
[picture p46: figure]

Figure 5: Mockup of the overall physical design aesthetics. The master board will be contained within an enclosure (“chassis”) intended to replicate the traditional form factor of a game controller, with the module segments all consistent in measurement to allow a dynamic layout. Grips, not pictured, can be attached to each side of the enclosure for ergonomic support and aesthetics.

### Vertical Features

External Interface

A major use case is the reconfigurability of modules on the Prototroller chassis. To disconnect, the user may grab a module and pull it away (severing the physical and electrical connections). To connect, the user may insert a module into a slot and press the “rescan” button to update the persistent state. The other major use case is the I/O interaction, from which the user interacts with the mounted component while the module is connected to the chassis. In addition, we order four 12mm (about 0.47 in) circuit playground bolt-on to connect with two screws on top of PCB board and bottom of chassis.

Persistent State

The Prototroller is a real-time device that operates with little persistent state. As we integrate more swappable modules into the project, the host device will keep track of which modules have been inserted in an internal data store. The data store is persistent until the user presses a rescan button, which triggers a routine to check if the physical module configuration has been changed. This routine could also trigger during faults, such as an unresponsive module, to update the data store accordingly. The data store of connected modules is routinely iterated to transmit and receive fresh data to/from the modules over SPI.

Internal Systems

When a module is initially connected, neither the host device nor master device will be aware of the change until the rescan button is pressed. This allows a user to fully set up their controller layout before the host attempts to use it. Additionally, it eliminates the need to continually run the detection routine during normal operation. Once the master detects new modules and retrieves their associated IDs, it will store these objects in an internal data store. The master may then iterate over the connected modules and read/write data at a constant rate. The master will sequentially poll each module using two 4-16 decoders to pull each chip-select low, read/write serial data, and pull the chip-select high. Only one chip-select will be pulled low at a time. Regardless of whether input is registered, data will be transferred between MISO and MOSI lines between the master and slave.

### Hardware Design

Schematic Creation

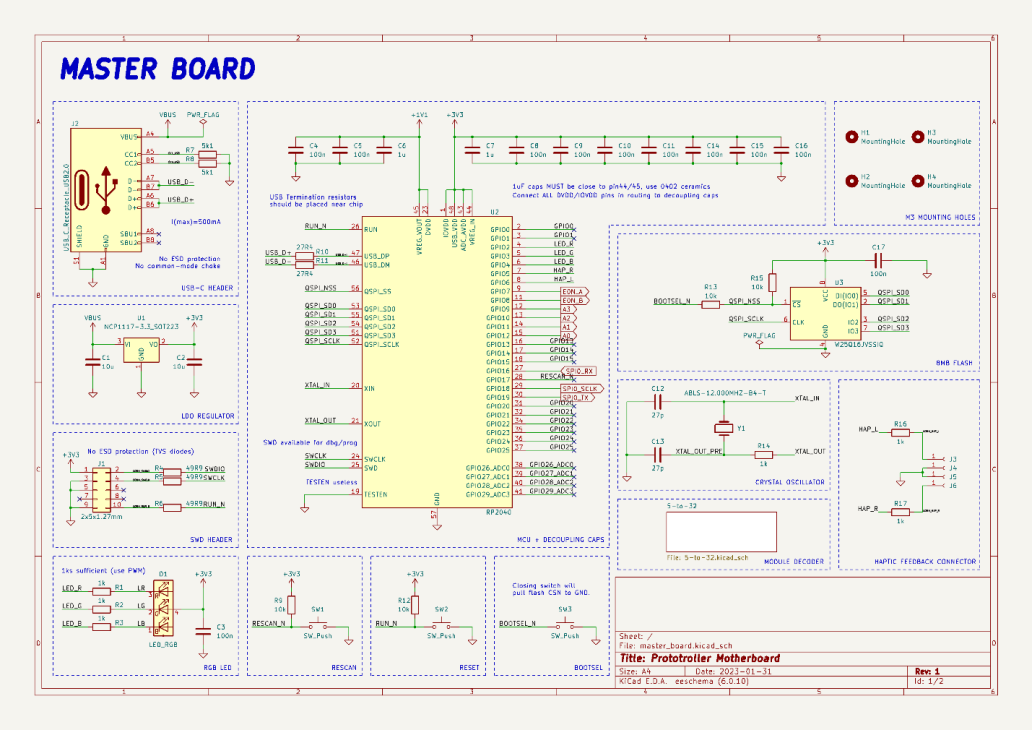
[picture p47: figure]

Figure 6: Master board completed schematic.

When creating the first drafts of our board schematics, we utilized the publicly available schematics of the RP2040 Pico and Tiny2040 microcontrollers. In tandem we also referenced the Hardware Design Manual of the RP2040 chip, cross-referencing design decisions and ensuring we adhered to the base requirements, as well as adapted any improvements utilized in boards produced most like ours. Our stakeholder, Carsten, provided lots of great feedback along this design process that helped us push the beta build to the finish line!

Primary components of both board schematics are the crystal oscillator, SWD header, flash chip, and the RP2040. After reviewing and confirming the proper configurations for these components, we appended additional components to each board schematic. For the master board, it was pertinent to include an LDO regulator, USB-C header, as well as decoders, haptics, and various button inputs.

The module board required a different subset of components, most being header pins for use with the Veroboard components that would be mounted on a backpack atop the primary board. As our module boards are generic across all components, we could not include any specific component pieces in the design, and thus opted for a concise number of available pins for interaction with components of our choosing. These boards also required interfacing pins from the base board so they could receive SPI communication and power and ground terminal points.

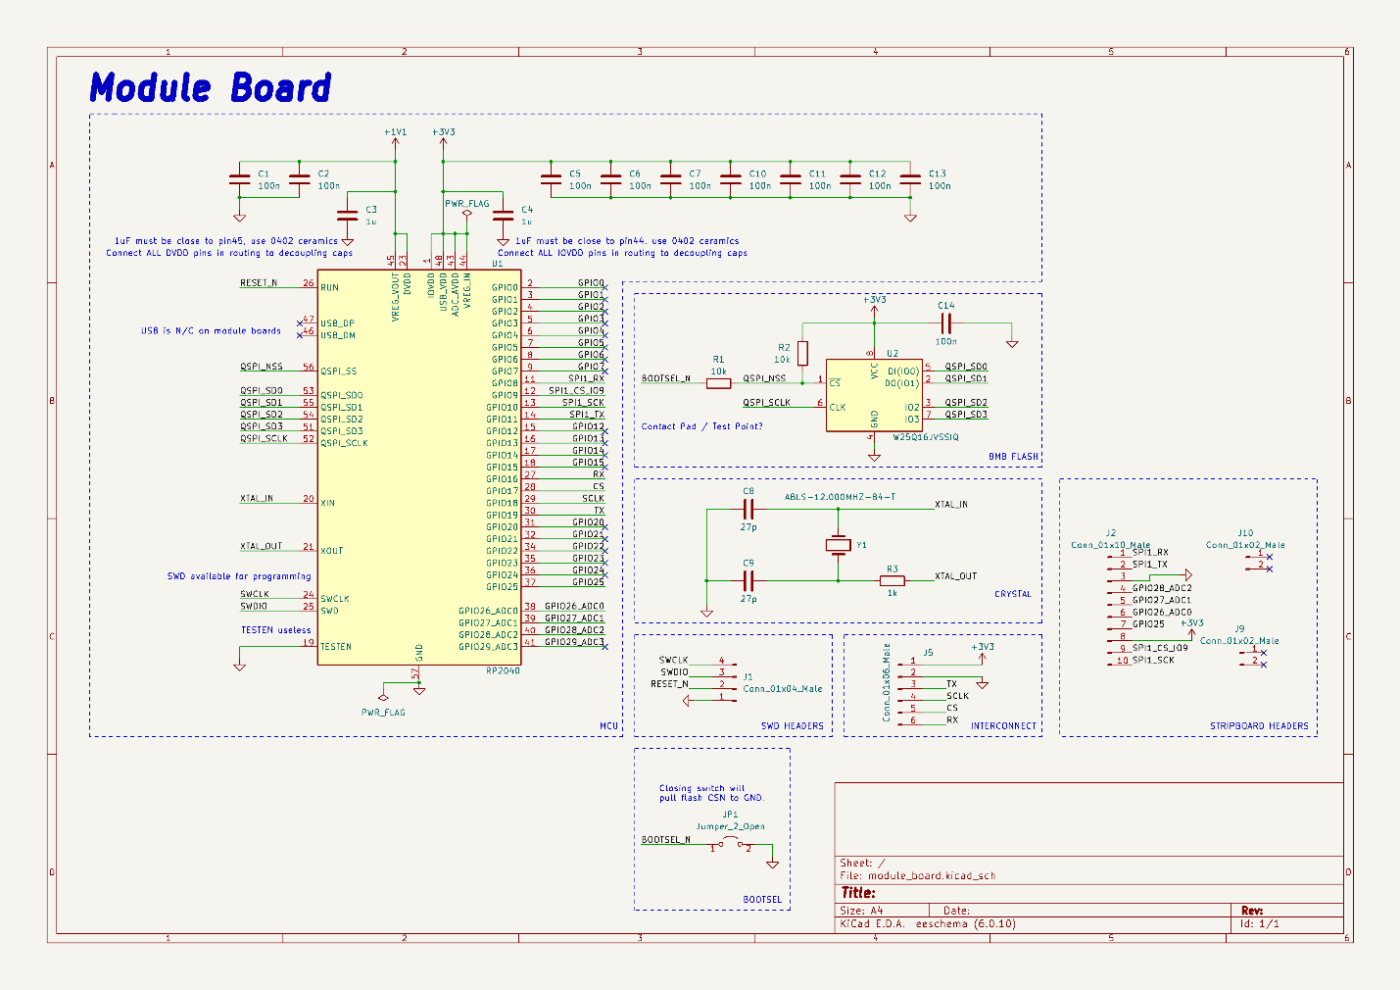
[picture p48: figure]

Figure 7: Completed Prototroller Module Board Schematic

Part Selection & Limitations

To assign the proper footprints to each component in our schematics for use in PCB design, we had to select specific parts and form factors that were affordable, readily available, and constrained to the tighter proportions of our module boards. We created a Bill of Materials (BOM) containing our chosen components for order and confirmed that the clearances of each footprint were within specification for our PCB production facility. We encountered an interesting issue at this stage where the form factors of SMD components are labelled 01005 and 0402, which are interchangeable unit label measurements between metric and imperial, which have vastly differing PCB footprints. After correcting our errors in this, we placed our components onto our PCB board within specification.

PCB Placement & Routing

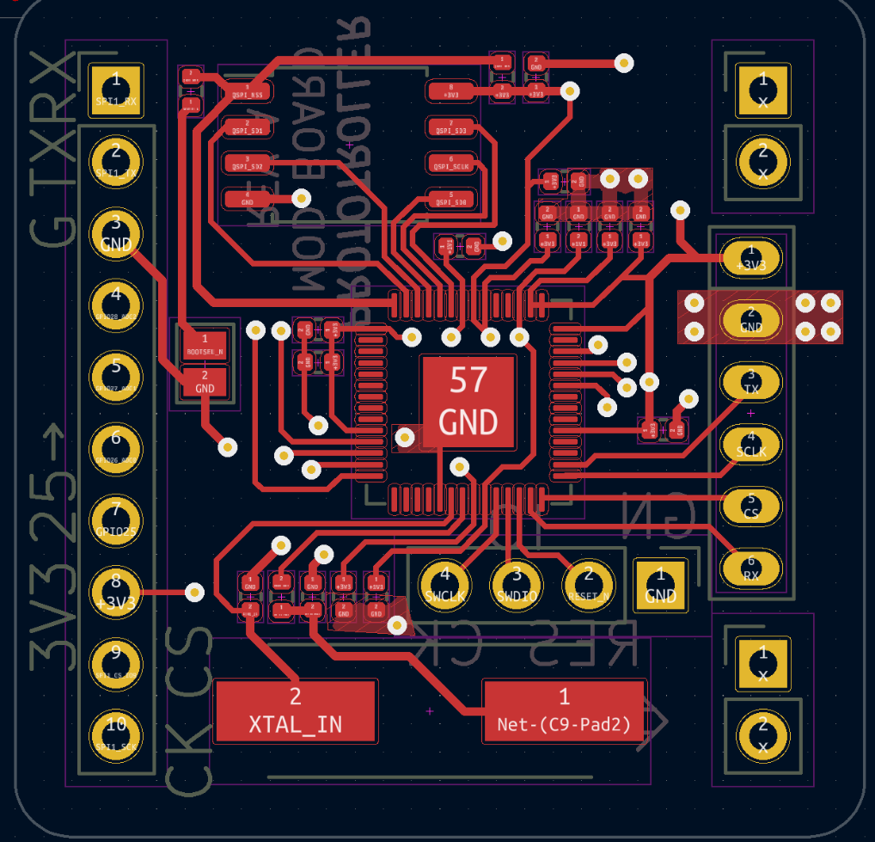
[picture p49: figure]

Figure 8: PCB Design, fitted with routing and component footprints, 30x30mm. Hard to do!

We used a 2 layer PCB design for both boards, keeping the bottom layer as primarily a ground plane, limiting the amount of traces trenched through the pour as much as possible. We ensured that placements of high-speed timing devices were as close to their destination as possible, as was the also the case for decoupling capacitors. We fit our connecting pins alongside the top and bottom edge of our board, with the SWD header intended to be unpopulated through holes, used once for programming the RP2040. The module side of the pogo-pin connector is to be soldered onto the underside of the board, and the disconnected through-holes are intended for structural support with the Veroboard.

Our master board has more trenches in the bottom layer due to multiple crossovers, but the inter-board pinouts were matched and designed to minimize these as much as possible. The board has more area for routing, thus, when possible, traces were given additional space between one another, and routed across the top layer in straight lines where possible. Placements from the module board were mostly duplicated, with mild changes due to the increased space available. Rule checks were run on each board with the manufacturing specification parameters provided by our PCB manufacturer. The resulting designs successfully passed with no warnings or errors and were quickly approved for manufacturing.

Final Design Considerations

There were multiple considerations involved in the ‘final’ beta build, one of which was the inclusion of mounting holes. These holes would have been included to mount the component to the module board. Upon further consideration, these mounting holes would have taken too much space that would have otherwise been taken by other essential components of the module board. These mounting holes would also have not made as much sense with our idea with a Veroboard, a grid of holes with parallel copper strips running from one edge to the other.

As a result, we decided to use 2.54mm pitch male header pins and place them around the board in such a way that one row is tied to one signal. These pins will also allow us to cut an exact square of Veroboard and precisely fit on top of our module board.

All routing, components, and vias were placed with intent and with the idea of aesthetic in mind.

A issue that may arise from this design in practice, is that the pogo pins may overlap with the bottoms of the soldered male header pins and the GND on the RESET and CLK, which is not a big deal since we will not be using it. Cutting these header pins from the bottom of the module board so that they are flushed will potentially resolve this issue.

The project GitHub repository (https://github.com/roboryman/prototroller) contains all sources and schematics. Instructions are there and will be updated over the project.

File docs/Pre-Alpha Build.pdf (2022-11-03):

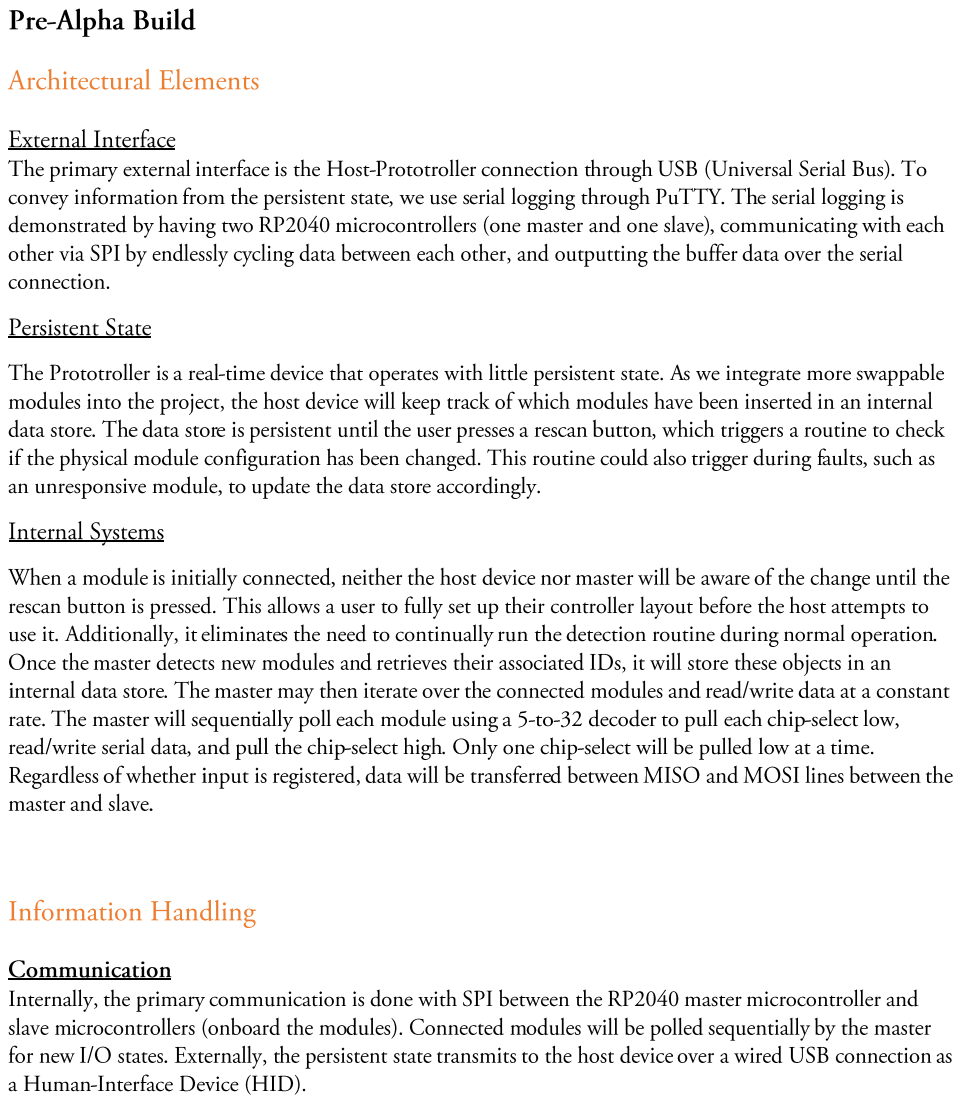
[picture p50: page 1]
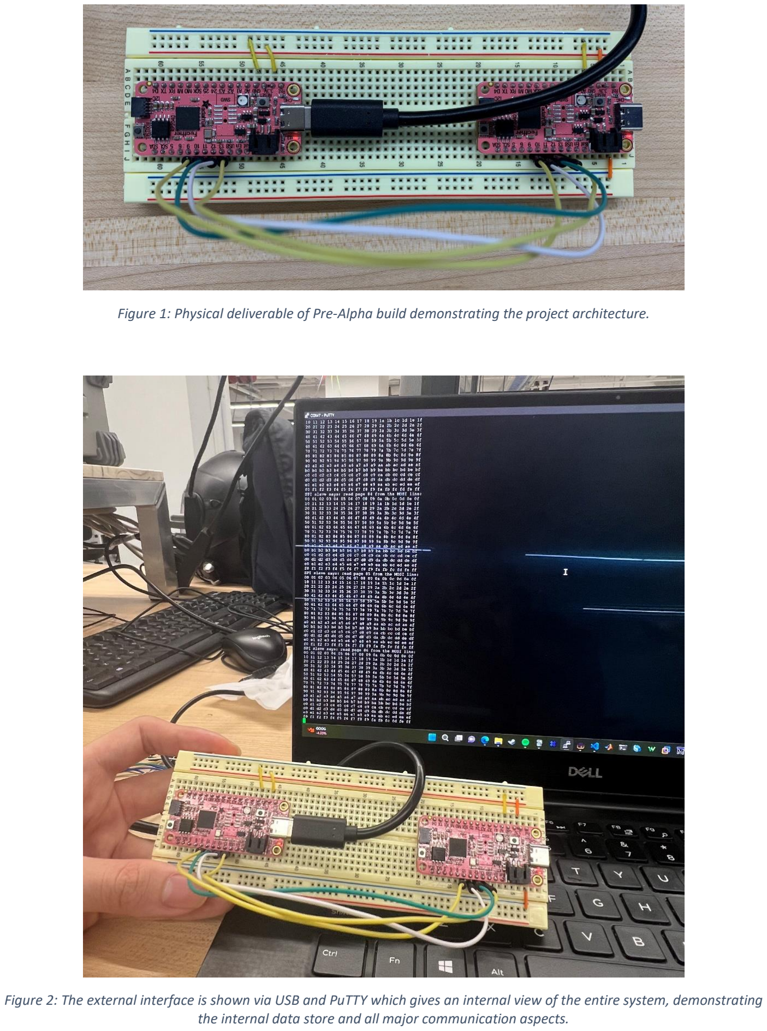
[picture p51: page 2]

Figure 1: Physical deliverable of Pre-Alpha build demonstrating the project architecture.

Figure 2: The external interface is shown via USB and PuTTY which gives an internal view of the entire system, demonstrating the internal data store and all major communication aspects.

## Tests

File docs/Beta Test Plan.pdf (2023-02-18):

## Alpha Test Results

We have not been able to perform some parts of the alpha testing because we do not have all the hardware yet (very soon!). However, where functionality can be efficiently tested on our prototype board, we have done so. The rest we have refined in test procedures as part of the Beta Test Plan.

Results: Verification of Average Power Draw by Software Measurement (Pico Prototype)

Test Procedures | Expected Results (0 Modules) | Results | Expected Results (n Modules) | Results
1. Choose USB port to plug Prototroller into on Windows host | N/A | N/A | N/A | N/A
2. Measure power consumption for this port using USBDeview | Consuming 0mA | Consuming 0mA | Consuming 0mA | Consuming 0mA
3. Plug Prototroller into host | N/A | N/A | Windows does not report “Power Limit Exceeded” | Windows did not report “Power Limit Exceeded”
4. Measure power consumption for port using USBDeview | Consuming <=50 mA | Consuming 100mA | Consuming ≤ 500mA (following n ∗ 20mA line) | 1-3 Modules: Consuming 100mA

Interpretation: it would seem measuring power draw via software is not completely accurate. For example, with no modules connected, it was reporting 100mA when, in fact, Pico’s do not draw that much.

Results: Verification of Module Rescanning (Pico Prototype)

Test Procedures | Expected Results | Results
1. Ensure Prototroller is plugged into host with no connected modules | N/A | N/A
2. Establish a serial connection to the master board with a console such as PuTTY | Output is displayed on serial console | Output is displayed on serial console
3. Press and release the rescan button | Module rescan initiated and all modules identified as disconnected on serial console | Rescanning for active modules message. Modules 0 through 24 are DISCONNECTED

4. Plug-in a module with an invalid ID to a random slot k | No change on serial console | No change
5. Press and release the rescan button | Module rescan initiated, no change on serial console (module k shown as disconnected). | No change
6. Plug-in a module with a valid ID to another random slot m | No change on serial console | No change
7. Press and release the rescan button | Module rescan initiated, only module m shown as connected with corresponding ID | Module shown as connected
8. Observe serial console | Data from module in slot m is output | Data from module is output
9. Disconnect the module in slot m | No output on serial console | Disconnect triggered log messages indicating the new state. “Module 0 appears to have disconnected or is invalid: DISCONNECTED”
10. Press and release the rescan button | Module rescan initiated; all modules shown as disconnected | Rescanning for active modules message. Modules 0 through 24 are DISCONNECTED
11. Disconnect the module in slot k | No change on serial console | No change on serial console
12. Repeat 6-9 until every slot has been evaluated | See 6-9 expected results | ...

Interpretation: Our design changed from using 25 modules to 20, so the firmware should be updated to reflect this. Testing for the win!

Results: Firmware Behavioral Testing (Debug Firmware)

Master Device
Test Procedures | Expected Result | Results
Device Boots and outputs serial (console) data | Visible COM Port when using debug firmware version | Utilizing USBDeview, master device appears as “Master”, and is listed under a COM Port.
Device completes initial scan | Console output of connected modules | Console outputs a list of all 25 disconnected modules (no modules connected). Note, console output does not appear until the rescan button is pressed, but the scan is initiated as soon as the master device is connected to power.
Device Rescan Button begins scan | Console output of rescanned modules | Rescanning for active modules message. Modules 0 through 24 are DISCONNECTED.

Device receives correct data packets | Console output displays proper data/state of module device | Console receives correct rescan output, displaying button module as connected. The data packets are correct, pressing button outputs a ‘1’, releasing it outputs a ‘0’.
Device maintains module connection | Console does not display disconnect messages | Console maintains a steady output and displays no disconnect messages if the module is connected and powered.

Module Device
Test Procedures | Expected Result | Results
Device Boots and outputs serial (console) data | Visible COM Port when using debug firmware version | COM port was not visible due to it being disabled in fear that print statements would affect our SPI baud rate. After enabling it, the COM port was visible, and we could read serial outputs.
Device reads ADC/GPIO data | Console output of raw data | Joystick module outputs raw data, button module outputs logical high and logical low.
Device calculates computation of data | Console output of computed data | Joystick module outputs raw data, button module outputs logical high and logical low. Master module takes Joystick data and calculates it into normalized data that ranges between (-5, 5).
Device sends data when requested | Console output of successful transmission | Console continually outputs data as master board cycles it via CS.
Device blocks when data not requested | Console does not display additional messages | Console does not output data when not requested, as evidenced by Master device’s output being uniform and outputting consistent data in the order of currently connected modules.
Data read is within accurate bounds | Console outputs acceptable data value (tolerance differs based on module type) | The data in master is accurate and module side is more precise and within accurate bounds.

Interpretation: Behavioral testing was a success. We had commented out serial logging module-side to not interfere with SPI (i.e., module readily available to transmit and receive data). This brings up a good point – determining if we want module-side logging at all. Perhaps a debug mode since the logging would only be visible via SWD (no USB-C connector on the module boards) and never during normal use.

## Expected Behavior

The core expected behavior has not changed since the Alpha Test Plan. We have already encapsulated the bulk of it, save for a few minor details. These details are related to the fact that we are now utilizing our own custom hardware rather than the RP2040 Pico’s utilized in the prototype and alpha builds.

Overall Coarse Expected Behavior

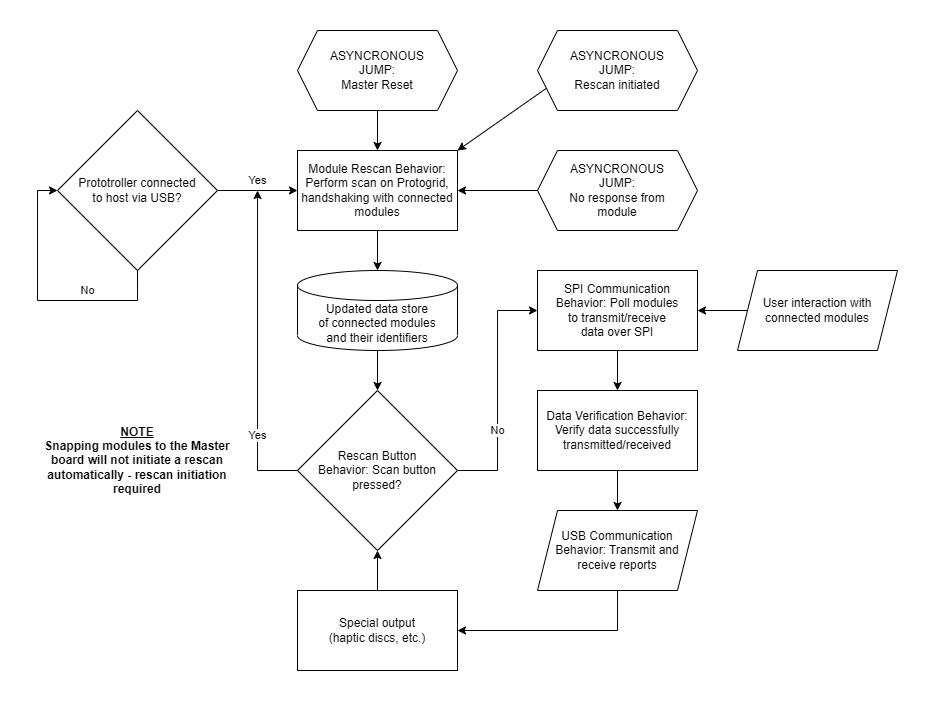
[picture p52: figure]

Master Board Flashing Expected Behaviors

Action | Result
Do Nothing (*Powered*) | N/E - Master RP2040 stays in current mode
Press the “BOOTSEL” button (*Powered*) | N/E - Master RP2040 stays in current mode
Press the “RESET” button (*Powered*) | Master RP2040 begins executing program code from the beginning of flash
Press and hold the “BOOTSEL” button, press and release the “RESET” button, drag UF2 binary firmware to mount (*Powered*) | Master RP2040 mounts to the host in bootloader mode. Master RP2040 de-mounts after firmware is flashed and begins executing program code from the beginning.
Press and hold the “BOOTSEL” button, disconnect USB (if applicable), connect USB, drag UF2 binary firmware to mount | Master RP2040 mounts to the host in bootloader mode. Master RP2040 de-mounts after firmware is flashed and begins executing program code from the beginning.
Alternative: flash master firmware with SWD debug apparatus | Master RP2040 begins executing program code from the beginning

Module Board Flashing Expected Behaviors

Action | Result
Do Nothing (*Powered*) | N/E – Module RP2040 stays in current mode
Short “BOOTSEL” pad (*Powered*) | N/E - Module RP2040 stays in current mode
Pull “RESET” pin low (*Powered*) | Module RP2040 begins executing program code from the beginning of flash
Short “BOOTSEL” pad, pull “RESET” pin low, pull “RESET” pin high | Module RP2040 does not mount, because it does not have a USB connection with the host…
Flash unique module firmware with SWD debug apparatus | Module RP2040 begins executing program code from the beginning

Master Module SPI Communication Expected Behaviors

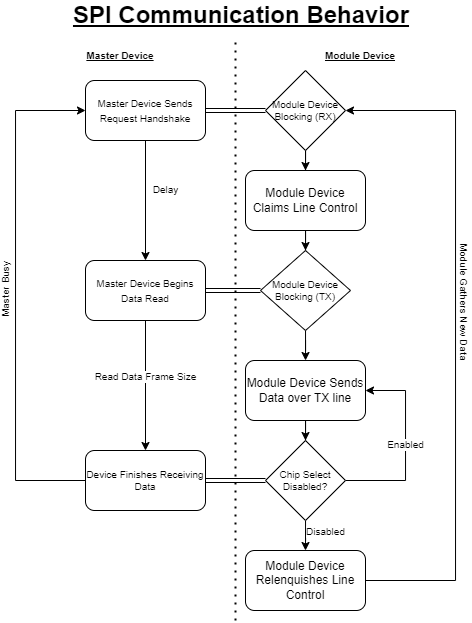
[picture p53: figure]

Host Master USB Communication / HID Report Expected Behaviors

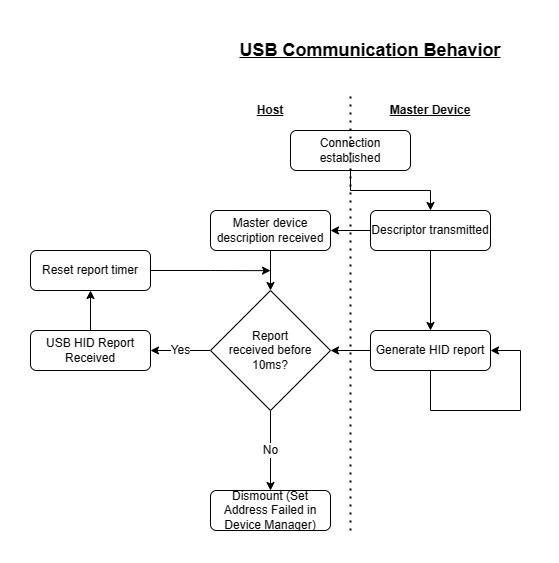
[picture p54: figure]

Module Rescanning / Data Verification Expected Behaviors

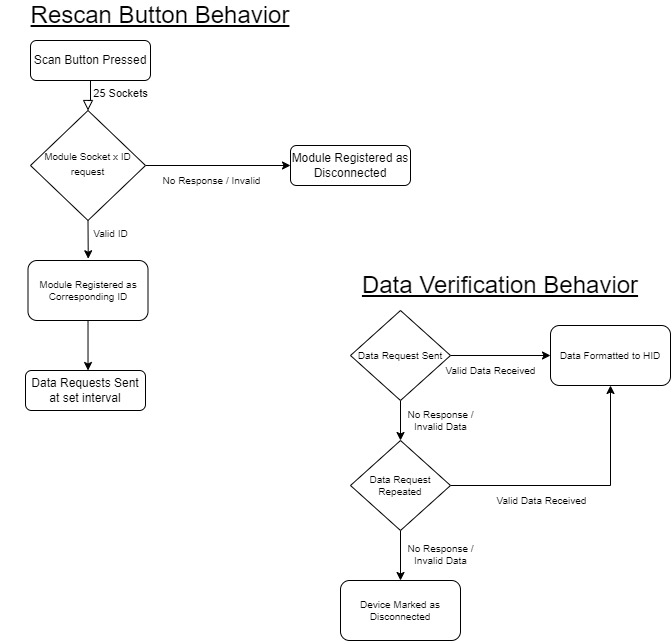
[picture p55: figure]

Additionally, most logical blocks of source-code are documented with functional purpose, parameters, edge-cases, etc.

## Beta Test Procedures

Many test procedures are borrowed from the Alpha Test Plan, since again we physically have not been able to test on our custom hardware. We would like to repeat these on the custom hardware.

Firmware Behavioral Testing (Debug Firmware)

NOTE: An initial test suite for functionality testing master firmware has been created, please see repository for more details.

Master Device
Test | Expected Result
Device Boots and outputs serial (console) data | Visible COM Port when using debug firmware version
Device completes initial scan | Console output of connected modules, HID packet descriptor matches connected modules, LED Complete indicator code displayed
Device Rescan Button begins scan | Console output of rescanned modules, LED Scanning indicator code displayed
Device receives correct data packets | Console output displays proper data/state of module device, HID Report packets contain data matching serial port
Device maintains module connection | Console does not display disconnect messages
Module Device
Test | Expected Result
Device Boots and outputs serial (console) data | Visible COM Port when using debug firmware version
Device reads ADC/GPIO data | Console output of raw data
Device calculates computation of data | Console output of computed data
Device sends data when requested | Console output of successful transmission
Device blocks when data not requested | Console does not display additional messages
Data read is within accurate bounds | Console outputs acceptable data value (tolerance differs based on module type)

Verification of Average Power Draw by USB Multimeter Tool

Test Procedures | Expected Results (0 Modules) | Expected Results (n Modules)
1. Plug in the Prototroller to the host through a USB Multimeter Tool | N/A | N/A
2. Measure power consumption with the tool | Consuming ≤ 100 mA | Consuming n* ~50mA, not exceeding 500mA

Verification of Module Rescanning

Test Procedures | Expected Results
1. Ensure Prototroller is plugged into host with no connected modules | N/A
2. Establish a serial connection to the master board with a console such as PuTTY | Output is displayed on serial console
3. Press and release the rescan button | Module rescan initiated and all modules identified as disconnected on serial console
4. Plug-in a module with an invalid ID to a random slot k | No change on serial console
5. Press and release the rescan button | Module rescan initiated, no change on serial console (module k shown as disconnected).
6. Plug-in a module with a valid ID to another random slot m | No change on serial console
7. Press and release the rescan button | Module rescan initiated, only module m shown as connected with corresponding ID
8. Observe serial console | Data from module in slot m is output
9. Disconnect the module in slot m | No output on serial console
10. Press and release the rescan button | Module rescan initiated; all modules shown as disconnected
11. Disconnect the module in slot k | No change on serial console
12. Repeat 6-9 until every slot has been evaluated | See 6-9 expected results

Verification of SPI Communication

Test Procedures | Expected Results
Probe Rx and Tx bus lines for master board with oscilloscope triggers | Handshake is sent, and data is correctly received
Probe CS bus lines for master board with oscilloscope triggers | All modules currently connected are visibly shown on the oscilloscope

Verification of HID Drivers

Test Procedures | Expected Results
Use Device Monitoring Studio to view HID reports | All data packets via reports are correct, and are consistent with module board inputs

Verification of Latency Constraints

Measuring the latency of controllers in general is difficult, but not impossible with the right hardware. In our case, the methodology is to aim a high-speed camera at our host display and a LED connected to a button module mapped to a left-click schema. Then we can compare – in editing software - the delta time between the LED lighting and a UI element on the display changing in response to the left-click. Preferably, use a monitor with 144+Hz refresh rate for a more accurate measurement.

Test Procedures | Expected Results
1. Plug in Prototroller to host with one module connected: button, with left-click schema. Connect Switch => LED => Resistor => +3V3 | N/A
2. Press and release the rescan button | N/A
3. Set up mouse on element to be left-clicked (action must modify UI in some way) | N/A
4. Start recording with 240fps, giving smallest possible increment of 4.16ms | N/A
5. Press and release the button | LED ON for as long as the button is pressed.
6. Stop recording | N/A
7. In post-processing software, find the frame the LED lights up and the frame the UI responds. | N/A
8. Convert the difference in frames to a response time: #frames * (1/240) | Response time should be ≤ 20 ms for acceptable result, or ≤ 6ms for nominal result

Verification of Hardware Signals + Circuitry

Test Procedures | Expected Results
Continuity Test between all 7 connection points of master-module connectors | Continuity between each line, no continuity across lines
No shorting across decoupling capacitors | No continuity across capacitor pads
Line value fluctuations across decoupling capacitors | No noise/wobble exceeding 3% of the average constant value of the line (ex: 3Volt ±0.1V), idle or under load
Flash storage interfacing properly executing with RP2040 | Program memory is maintained upon loss of power
Oscillator clock speed is within proper limits | Frequency of crystal oscillator signal is within 3% of 12 MHz
Chip Select signals properly activate through decoders | Each numbered chip select trace is held at logical high unless signaled in firmware. Firmware value (1,2,3, etc.) corresponds to proper CS line

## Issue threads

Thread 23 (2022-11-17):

Finish README

roboryman, 2022-11-17:
Go into detail about how to build, run, and modify (board requirements, CMake, etc.)
Discuss the project: motivations, architecture, user story, etc (take from Design & Development Plan, Design Mockup, Pre-Alpha Build).

roboryman, 2022-11-30:
Sufficient for the prototype, but definitely need to go into more detail once we have the finalized software and hardware artifacts for the full release.

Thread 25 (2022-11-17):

Component Abstraction Layer

roboryman, 2022-11-17:
Create a component abstraction layer between the component and slave that allows you to easily specify modules based on available RP2040 peripherals and the component I/O. Modules will use functionality this layer provides in their own wrappers. I.E., separate out the lower-level details of the RP2040.

Ideas:
- [ ] GPIO (Button might implement this in wrapper)
- [ ] ADC (Joystick might implement this in wrapper)
- [ ] I2C (OLED, Accelerometer might implement this in wrapper)
- [ ] SPI
- [ ] UART
- [ ] PWM
- [ ] PIO (WS2812 LEDs might implement this in wrapper)

Example: For GPIO, we might make an init function that initializes a pin for input with internal pull-up, and a read function that returns the pin status (HIGH or LOW). The button wrapper can utilize these functions on the specified pin to read in the pressed status for transmission to master.

roboryman, 2022-11-17:
We decided to abandon this approach as a team. The Pico SDK is high-level enough that we can reasonably expect users to extend the Prototroller with it in order to create custom modules.

Closed 2022-11-17.

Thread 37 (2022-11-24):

Buttons - XYAB Schema Component

roboryman, 2022-11-24:
Used typically for games that take 4 unique inputs. The user may map these buttons to any action/key they desire. Pushing a button incites an action.
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

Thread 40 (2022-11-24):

Accelerometer Component

roboryman, 2022-11-24:
The user may shake, jerk, or otherwise move the controller to provide X, Y, and Z axes acceleration inputs.
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

evanzh15, 2023-01-26:
Added a LSM6DS3 accelerometer/gyroscope into the master_board.kicad_sch, configured for SPI

Closed 2023-01-26.

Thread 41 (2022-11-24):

Gyroscope Component

roboryman, 2022-11-24:
The gyroscope utilizes measurements of angular velocity, typically tilting the controller is enough to register a reading.
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

evanzh15, 2023-01-26:
Added a LSM6DS3 accelerometer/gyroscope into the master_board.kicad_sch, configured for SPI

Closed 2023-01-26.

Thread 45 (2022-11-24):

Speed-up SPI Baud Rate

roboryman, 2022-11-24:
Figure out how we can speed-up the SPI baud rate w/o breaking things. I think a good target baud rate for ensuring fast response time is 10 Mbps (right now, we are managing 1 Mbps). This 10x speedup would net us a total poll of 5ms when all 25 modules are connected (assuming there are 256 data bytes + a few handshake bytes = 260 total bytes). It seems if we raise it past 1 Mbps on both master and module ends, things start breaking. We really need to delve into the RP2040 datasheet and see what is going on. And, in the process, try not to break TinyUSB...

roboryman, 2023-03-01:
We were able to raise the baud rate to 12 Mbps on master board and mod boards with no obvious issues, giving a 12x speedup (about 0.5ms to poll if all modules are connected... fantastic!)

Closed 2023-03-01.

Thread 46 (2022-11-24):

Design Voltage Regulator Block

roboryman, 2022-11-24:
Our integrated board design will require a voltage regulator to convert the 5V VBUS to a stable and clean 3.3V to feed the RP2040s (master and modules).

roboryman, 2023-01-18:
We can use a buck converter to get a 3.3V to feed all digital components. However, USB power rails are pretty noisy so we should dampen high frequencies on the 5V supply with a Pi filter network (2 caps + inductor). Can choose L=10nH (0.15 Ohm DC resistance) and C=1uF, giving a cut-off frequency of 1.6MHz. Then we can pass to the buck converter. See the course notes for more details

roboryman, 2023-01-18:
We could also use an LDO regulator to feed analog components like op-amps, but this is probably un-necessary. Let's determine if we have any analog circuitry, first.

roboryman, 2023-01-26:
Ultimately, we will use an LDO regulator to maintain power efficiency. We need all the juice we can get from the 500mA connection. Thanks to Britton for incorporating this on the master board schematic.

Closed 2023-01-26.

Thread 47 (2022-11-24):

Design Module Flash Memory Block

roboryman, 2022-11-24:
Our module board design(s) will require quad SPI flash memories to store program code (text), as the RP2040 does not do this internally.

roboryman, 2023-01-26:
The W25Q64JVXGIQ (8MB) is sufficient for both the module and master, and a block schematic has been created.

Closed 2023-01-26.

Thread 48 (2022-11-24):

Design Module Crystal Oscillator Block

roboryman, 2022-11-24:
Our module board design(s) **_may_** require an external crystal oscillator for a stable frequency source to the RP2040. While the RP2040 has an internal oscillator, they recommend feeding the clock from an external oscillator. So, step 1 is determining if we can use the internal crystal with the high frequencies we will likely need for SPI (>= 10 Mbps), step 2 is picking a crystal oscillator that fits those constraints, and step 3 is designing around the selected part.

roboryman, 2023-01-26:
We will use an external crystal. The Hardware Design doc uses  ABLS-12.000MHZ-B4-T in their minimal design example (12 MHz). Likely too slow, so we should look for a similar one with a higher frequency.

Closed 2023-01-26.

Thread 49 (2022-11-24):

Design Module Flashing/Debug Port Block

roboryman, 2022-11-24:
Our module board design(s) need to allow a way to flash and/or debug our RP2040. USB is pretty much out of the question since these boards need to be tiny (currently, we are targeting 20mm x 20mm for 1x1 modules). We can look into achieving this with SWD, perhaps by placing pads on the PCB and finding a way to automate flashing large amounts of modules (so we do not have to do each by hand).

Closed 2023-01-23.

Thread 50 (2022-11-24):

Design Master Crystal Oscillator Block

roboryman, 2022-11-24:
Our integrated board design may require an external crystal oscillator for a stable frequency source to the master RP2040. While the RP2040 has an internal oscillator, they recommend feeding the clock from an external oscillator. So, step 1 is determining if we can use the internal crystal with the high frequencies we will likely need for SPI (>= 10 Mbps), step 2 is picking a crystal oscillator that fits those constraints, and step 3 is designing around the selected part.

evanzh15, 2023-01-27:
Find appropriate Crystal Oscillator component with footprint.

Closed 2023-02-03.

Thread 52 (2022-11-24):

Design Master USB Port Block

roboryman, 2022-11-24:
Our integrated board design needs to allow a way to flash and/or debug our master RP2040. Additionally, we need a USB port for TinyUSB communication between mater and host. Finally, power needs to be delivered to the entire Prototroller. All of these things can be accomplished using a single USB port exposing the data, VCC, and GND lines to the integrated board.

Closed 2023-01-23.

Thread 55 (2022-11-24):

Design Master Rescan Block

roboryman, 2022-11-24:
The user will need to press a rescan button to indicate they have connected new modules, from which the master attempts an identification handshake on all possible chip selects. Design the module for this (simple GPIO and pull-up resistor, but we may have to creatively place this on the Prototroller itself).

evanzh15, 2023-01-25:
Created a section in master_board.kicad_sch that pulls up signal RESET, and connects it to a tactile switch. #

Closed 2023-01-25.

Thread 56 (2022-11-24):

Design Electrical Interconnects

roboryman, 2022-11-24:
When a module is snapped to the Prototroller, there should be a solid electrical connection for the following 6 pins between the chassis and the module: VSYS, GND, SPI TX, SPI RX, SPI SCK, SPI CSN. The VSYS, GND, SPI TX, SPI RX, and SPI SCK pins are shared among all modules. The SPI CSN pin will be wired to a specific chip select from the 5-to-32 decoder.

We might do this a few ways:

- Contact pads. This is what that MIDI product seems to do, bonus if we can somehow make it magnetic and also solve the physical connection problem. There should be plenty of space for 6 contact pads.
- Female headers on chassis, male pins on module. Pins could be bent in module transit, but we wouldn't have a bunch of pins sticking out of the Prototroller at all times. You would also need to orient correctly.
- Pins on chassis, female headers on module. This has the advantage of pins not sticking out of the modules, which could be bent in transit. The disadvantage is that we would have 25*6 =150 pins sticking out of the chassis at all times. You would also need to orient correctly.

roboryman, 2023-01-26:
See https://github.com/roboryman/prototroller/issues/57

roboryman, 2023-02-07:
We decided to go with (6-pin) magnetic pogo-pin connectors (female on master board side, male on module side).

Closed 2023-02-07.

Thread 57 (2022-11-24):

Design Physical Interconnects

roboryman, 2022-11-24:
We need a way to physically "snap" or connect the modules to the Prototroller chassis. [Here](https://www.rapiddirect.com/blog/snap-fit-design/) is a page describing the different types of snap fits. We have access to 3D printers, so we can definitely create a model for at least the module portion. For the actual protogrid chassis, we might have to get a bit creative. It would be best if we designed a single model for the entire chassis and superglue/screw directly to it (or have clips to hold the two together).

roboryman, 2023-01-26:
Britton brought up a great point. A great way to solve the physical + electrical interconnect problem is to use a combination of magnets and pads on either ends. Some things to think about:

1. Should the magnets touch, or be very close?
2. How forceful should the user be to disconnect the module?
3. Design? (Xbar magnets with pads between, hexagonal pad arrangement with magnet inside, magnets in corners, etc.)
4. With the above points, how can we ensure the modules do not "fall out" during normal use, while maintaining a stable electrical connection?

roboryman, 2023-02-07:
We decided to go with magnetic pogo-pin connectors (female on master board side, male on module side).

Closed 2023-02-07.

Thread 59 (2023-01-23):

Master PCB Design

roboryman, 2023-01-23:
Design of the chassis PCB, i.e., the PCB that will go into the chassis the user holds. This consists of setting up design rules and footprints, layout, and routing.

Closed 2023-02-14.

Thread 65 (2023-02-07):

Chassis Design

roboryman, 2023-02-07:
Design the enclosure around the master board. We can 3D print and test multiple designs, if needed. We decided on a 4x5 module schema, with modules at 30x30mm (height unconstrained).
Constraints
- Size: >= master board size. With 4x5 module connector space, 30mm+ row for primary circuitry, and 2.5mm spacing between modules, this gives a minimum of square 160x160mm. Height is unconstrained, but may want to make identical to module height (so modules lie flush with chassis)
- Holes: hole for USB-C receptacle (mid-center?), large hole for rescan button, pinholes for boot-select and reset buttons, pinholes for RGB LEDs (above USB-C receptacle?)

Things like chassis edge width, color, etc. are unconstrained and we may design to our liking.

roboryman, 2023-02-09:
Rough mock up:
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

Closed 2023-04-18.

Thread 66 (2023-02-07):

Module Enclosure Design

roboryman, 2023-02-07:
Design the enclosure around the module board. We can 3D print and test multiple designs, especially if the designs are different for the corresponding components.
Constraints
- Size: 30x30mm since that is our module board size. If we decide to go _around_ the board (and not _over_), edge width must be <= module spacing divided by two. Currently, we target 2.5mm spacing between modules, giving a maximum edge width of 1.25mm (and hence, a maximum outer size of 32.5x32.5mm). The stripboard containing the specific component would be housed above the module board inside the enclosure. Hence, the enclosure should be at least as tall to cover the board + wires + stripboard + component base

Things like color are unconstrained and we may design to our liking.

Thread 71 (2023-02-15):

D-Pad Module Firmware Support

bcmcleavy, 2023-02-15:
Support for a D-pad module board (4 buttons or specific component) as well as data/packet processing by master board

roboryman, 2023-03-22:
Added support for 4 button components, including dpads and XYAB pads.
However, we should look into sending the dpad as a "hat" within the HID descriptor instead of just a plain button.

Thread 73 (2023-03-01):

Rev-B Master and Module Board Design

evanzh15, 2023-03-01:
Make modifications to the Rev-A Master and Module PCBs and Schematics to adjust issues and design flaws in the original boards.

Modify the following (but not limited to):

Master Board RevB:
- [x] Fix 4x16 decoder footprint
- [x] Keep flash pull-up at 10k, change 10k pull-up for BOOTSEL to 1k
- [x] Change the haptic 1x1 male header footprints to a single 1x4 male header footprint
- [x] Change the SWD connector to a ~1x4 male header footprint instead of a receptacle (SWDIO, SWCLK, RESET_N, GND)~ JST-SH BM03B-SRSS-TB receptacle for use with the official debugger
- [x] Add test points at bottom of board for SPI lines, VCC, GND (for measuring power distribution)
- [x] Add test points to GPIOs where possible
- [x] Add test points for chip selects coming from decoder
- [x] Module indicators on front silkscreen
- [x] _Maybe_: Modify pogo connector to not have VCC, GND next to each other (req. module board change)
- [ ] ...

Module Board RevB:
- [x] Add status LED and supporting circuitry
- [x] Get rid of BOOTSEL pad and associated 10k
- [x] Keep flash pull-up at 10k
- [x] Get rid of GND pin near SWD pins
- [x] Assign nets to the 2 1x2 female headers (rows are unconstrained)
- [x] Move SWD pins up, if at all possible
- [x] Add general test points, if at all possible
- [ ] ...

evanzh15, 2023-03-01:
[https://github.com/roboryman/prototroller/tree/rev-b](url)

roboryman, 2023-03-01:
Added a bit. For both boards we should keep the 10k on the QSPI_NSS flash nets since our boards work great with them currently. We need to decide on what nets we are going to assign to the 4 extra pins on the mod boards.

Closed 2023-03-07.

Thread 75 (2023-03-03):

Physical module support

roboryman, 2023-03-03:
Currently the pogo-pin connector pair is the only physical support between master board and module. Worse, it is only on one side. Therefore, any user interaction with the module usually makes it disconnect. Additionally, Britton pointed out that unsnapping the module is not done "straight up" as it should be, rather from an angle. So, we will have to come up with a way to fix these problems.

A simple fix would be to have our module enclosure walls "come down" and meet the master board.

Another fix could be to use foam on the bottom of the module board opposite to the pogo-pin connector.

Finally, we could investigate using magnets. For example, a south pole magnet on the bottom of the module slot and a north pole magnet on the bottom of the module board (opposite to pogo-pin connector).

Here is an illustration of the issue:
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

roboryman, 2023-03-03:
The concern about the wall solution is space. There are only 1.5mm between module slots, so that gives 0.75mm maximum wall thickness on each side of the module. This is doable with my printer, but we will see in practice...

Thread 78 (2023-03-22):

Accelerometer and gyroscope modules

roboryman, 2023-03-22:
It would be nice to have support for accelerometers and gyroscopes. The master logic is already there to forward the data as axes in our gamepad reports, but there is 1-2 hours of legwork to create the module firmware. We designed our module boards to bring up SPI1 on the header pins, so we would have to find accel/gyro boards that can communicate over SPI.

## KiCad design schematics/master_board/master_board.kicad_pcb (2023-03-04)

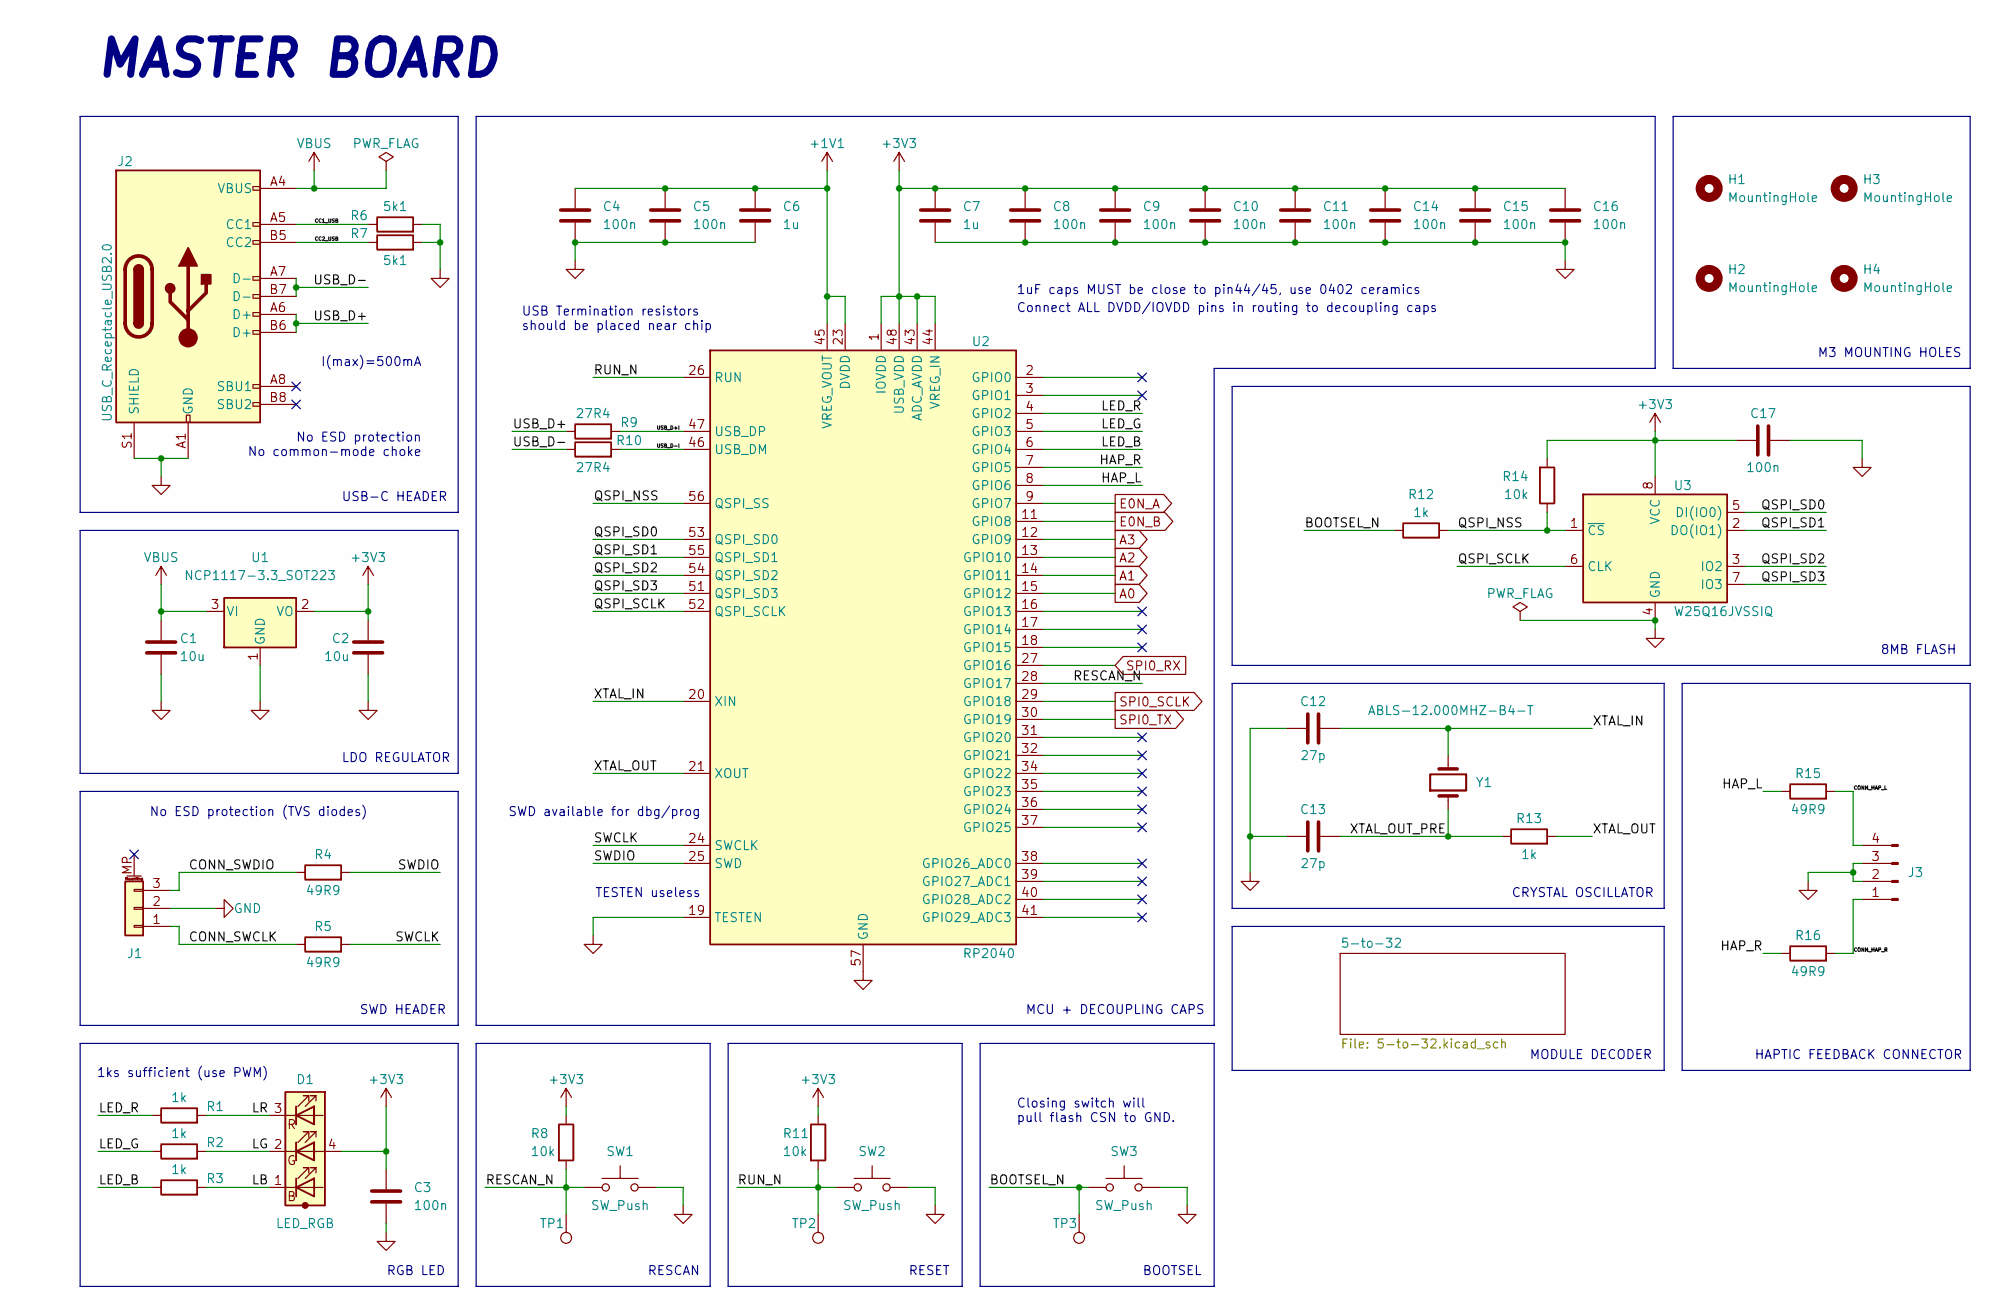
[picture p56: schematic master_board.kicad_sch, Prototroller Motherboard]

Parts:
C1, C2: 10u; C_0805_2012Metric; Manufacturer Part Number CL21A106KOQNNNG
C3, C4, C5, C8, C9, C10, C11, C14, C15, C16, C17: 100n; C_0402_1005Metric; Manufacturer Part Number C0402X7R100-104KNE-CT
C6, C7: 1u; C_0402_1005Metric; Manufacturer Part Number C0402X5R6R3-105KNP-CT
C12, C13: 27p; C_0402_1005Metric; Manufacturer Part Number C0402C0G250-270JNE-CT
D1: LED_RGB; LED_Cree-UHD111A; Manufacturer Part Number UHD111A-FKA-C3K23E1L3VG5ZB3Z3
H1, H2, H3, H4: MountingHole; MountingHole_3.2mm_M3
J1: Conn_01x03_MountingPin; JST_SH_BM03B-SRSS-TB_1x03-1MP_P1.00mm_Vertical
J2: USB_C_Receptacle_USB2.0; USB_C_Receptacle_GCT_USB4105-xx-A_16P_TopMnt_Horizontal; Manufacturer Part Number USB4105-GF-A
J3: Conn_01x04_Male; PinHeader_1x04_P2.54mm_Vertical
R1, R2, R3, R13: 1k; R_0402_1005Metric; Manufacturer Part Number RC0402FR-7W1KL
R4, R5: 49R9; R_0402_1005Metric; Manufacturer Part Number RC0402FR-7W49R9L
R6, R7: 5k1; R_0402_1005Metric; Manufacturer Part Number ERJ-2RKF5101X
R8, R11, R14: 10k; R_0402_1005Metric; Manufacturer Part Number RC0402JR-7W10KL
R9, R10: 27R4; R_0402_1005Metric; Manufacturer Part Number CRGP0402F27R
R12: 1k; R_0402_1005Metric; Manufacturer Part Number RC0402JR-7W10KL
R15, R16: 49R9; R_0402_1005Metric; Manufacturer Part Number RC0402FR-7W1KL
SW1, SW2, SW3: SW_Push; Switch_D6C40F1LFS; Manufacturer Part Number D6C40 F1 LFS
TP1, TP2, TP3: TestPoint; TestPoint_Pad_2.5x2.5mm
U1: NCP1117-3.3_SOT223; SOT-223-3_TabPin2; Manufacturer Part Number NCP1117LPST33T3G
U2: RP2040; QFN-56-1EP_7x7mm_P0.4mm_EP3.2x3.2mm; Manufacturer Part Number SC0914(13)
U3: W25Q16JVSSIQ; SOIC-8_5.23x5.23mm_P1.27mm; Manufacturer Part Number W25Q16JVSSIQ
Y1: ABLS-12.000MHZ-B4-T; XTAL_ABLS-12.000MHZ-B4-T; Manufacturer Part Number ABLS-12.000MHZ-B4-T

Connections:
+1V1: C4.1, C5.1, C6.1, U2.23 (DVDD), U2.45 (VREG_VOUT), U2.50 (DVDD)
+3V3: C2.2, C3.1, C7.1, C8.1, C9.1, C10.1, C11.1, C14.1, C15.1, C16.1, C17.1, D1.4 (A), R8.1, R11.1, R14.2, U1.2 (VO), U2.1 (IOVDD), U2.10 (IOVDD), U2.22 (IOVDD), U2.33 (IOVDD), U2.42 (IOVDD), U2.43 (ADC_AVDD), U2.44 (VREG_IN), U2.48 (USB_VDD), U2.49 (IOVDD), U3.8 (VCC); also elsewhere on the board
/BOOTSEL_N: R12.1, SW3.1, TP3.1
/CC1_USB: J2.A5 (CC1), R6.1
/CC2_USB: J2.B5 (CC2), R7.1
/CONN_HAP_L: J3.4, R15.2
/CONN_HAP_R: J3.1, R16.2
/CONN_SWCLK: J1.1, R5.1
/CONN_SWDIO: J1.3, R4.1
/HAP_L: R15.1, U2.8 (GPIO6)
/HAP_R: R16.1, U2.7 (GPIO5)
/LB: D1.1 (B), R3.2
/LED_B: R3.1, U2.6 (GPIO4)
/LED_G: R2.1, U2.5 (GPIO3)
/LED_R: R1.1, U2.4 (GPIO2)
/LG: D1.2 (G), R2.2
/LR: D1.3 (R), R1.2
/QSPI_NSS: R12.2, R14.1, U2.56 (QSPI_SS), U3.1 (~CS)
/QSPI_SCLK: U2.52 (QSPI_SCLK), U3.6 (CLK)
/QSPI_SD0: U2.53 (QSPI_SD0), U3.5 (DI(IO0))
/QSPI_SD1: U2.55 (QSPI_SD1), U3.2 (DO(IO1))
/QSPI_SD2: U2.54 (QSPI_SD2), U3.3 (IO2)
/QSPI_SD3: U2.51 (QSPI_SD3), U3.7 (IO3)
/RESCAN_N: R8.2, SW1.1, TP1.1, U2.28 (GPIO17)
/RUN_N: R11.2, SW2.1, TP2.1, U2.26 (RUN)
/SWCLK: R5.2, U2.24 (SWCLK)
/SWDIO: R4.2, U2.25 (SWD)
/USB_D+: J2.A6 (D+), J2.B6 (D+), R9.1
/USB_D+I: R9.2, U2.47 (USB_DP)
/USB_D-: J2.A7 (D-), J2.B7 (D-), R10.1
/USB_D-I: R10.2, U2.46 (USB_DM)
/XTAL_IN: C12.2, U2.20 (XIN), Y1.2
/XTAL_OUT: R13.2, U2.21 (XOUT)
/XTAL_OUT_PRE: C13.2, R13.1, Y1.1
A0: U2.15 (GPIO12); also elsewhere on the board
A1: U2.14 (GPIO11); also elsewhere on the board
A2: U2.13 (GPIO10); also elsewhere on the board
A3: U2.12 (GPIO9); also elsewhere on the board
E0N_A: U2.9 (GPIO7); also elsewhere on the board
E0N_B: U2.11 (GPIO8); also elsewhere on the board
GND: C1.2, C2.1, C3.2, C4.2, C5.2, C6.2, C7.2, C8.2, C9.2, C10.2, C11.2, C12.1, C13.1, C14.2, C15.2, C16.2, C17.2, J1.2, J2.A1 (GND), J2.A12 (GND), J2.B1 (GND), J2.B12 (GND), J2.S1 (SHIELD), J3.2, J3.3, R6.2, R7.2, SW1.2, SW2.2, SW3.2, U1.1 (GND), U2.19 (TESTEN), U2.57 (GND), U3.4 (GND); also elsewhere on the board
SPI0_RX: U2.27 (GPIO16); also elsewhere on the board
SPI0_SCLK: U2.29 (GPIO18); also elsewhere on the board
SPI0_TX: U2.30 (GPIO19); also elsewhere on the board
VBUS: C1.1, J2.A4 (VBUS), J2.A9 (VBUS), J2.B4 (VBUS), J2.B9 (VBUS), U1.3 (VI)

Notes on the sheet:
RESET
MODULE DECODER
SWD HEADER
1ks sufficient (use PWM)
USB-C HEADER
M3 MOUNTING HOLES
CRYSTAL OSCILLATOR
RGB LED
1uF caps MUST be close to pin44/45, use 0402 ceramics
USB Termination resistors should be placed near chip
TESTEN useless
HAPTIC FEEDBACK CONNECTOR
RESCAN
LDO REGULATOR
Connect ALL DVDD/IOVDD pins in routing to decoupling caps
No ESD protection No common-mode choke
SWD available for dbg/prog
BOOTSEL
8MB FLASH
Closing switch will pull flash CSN to GND.
I(max)=500mA
No ESD protection (TVS diodes)
MCU + DECOUPLING CAPS
MASTER BOARD

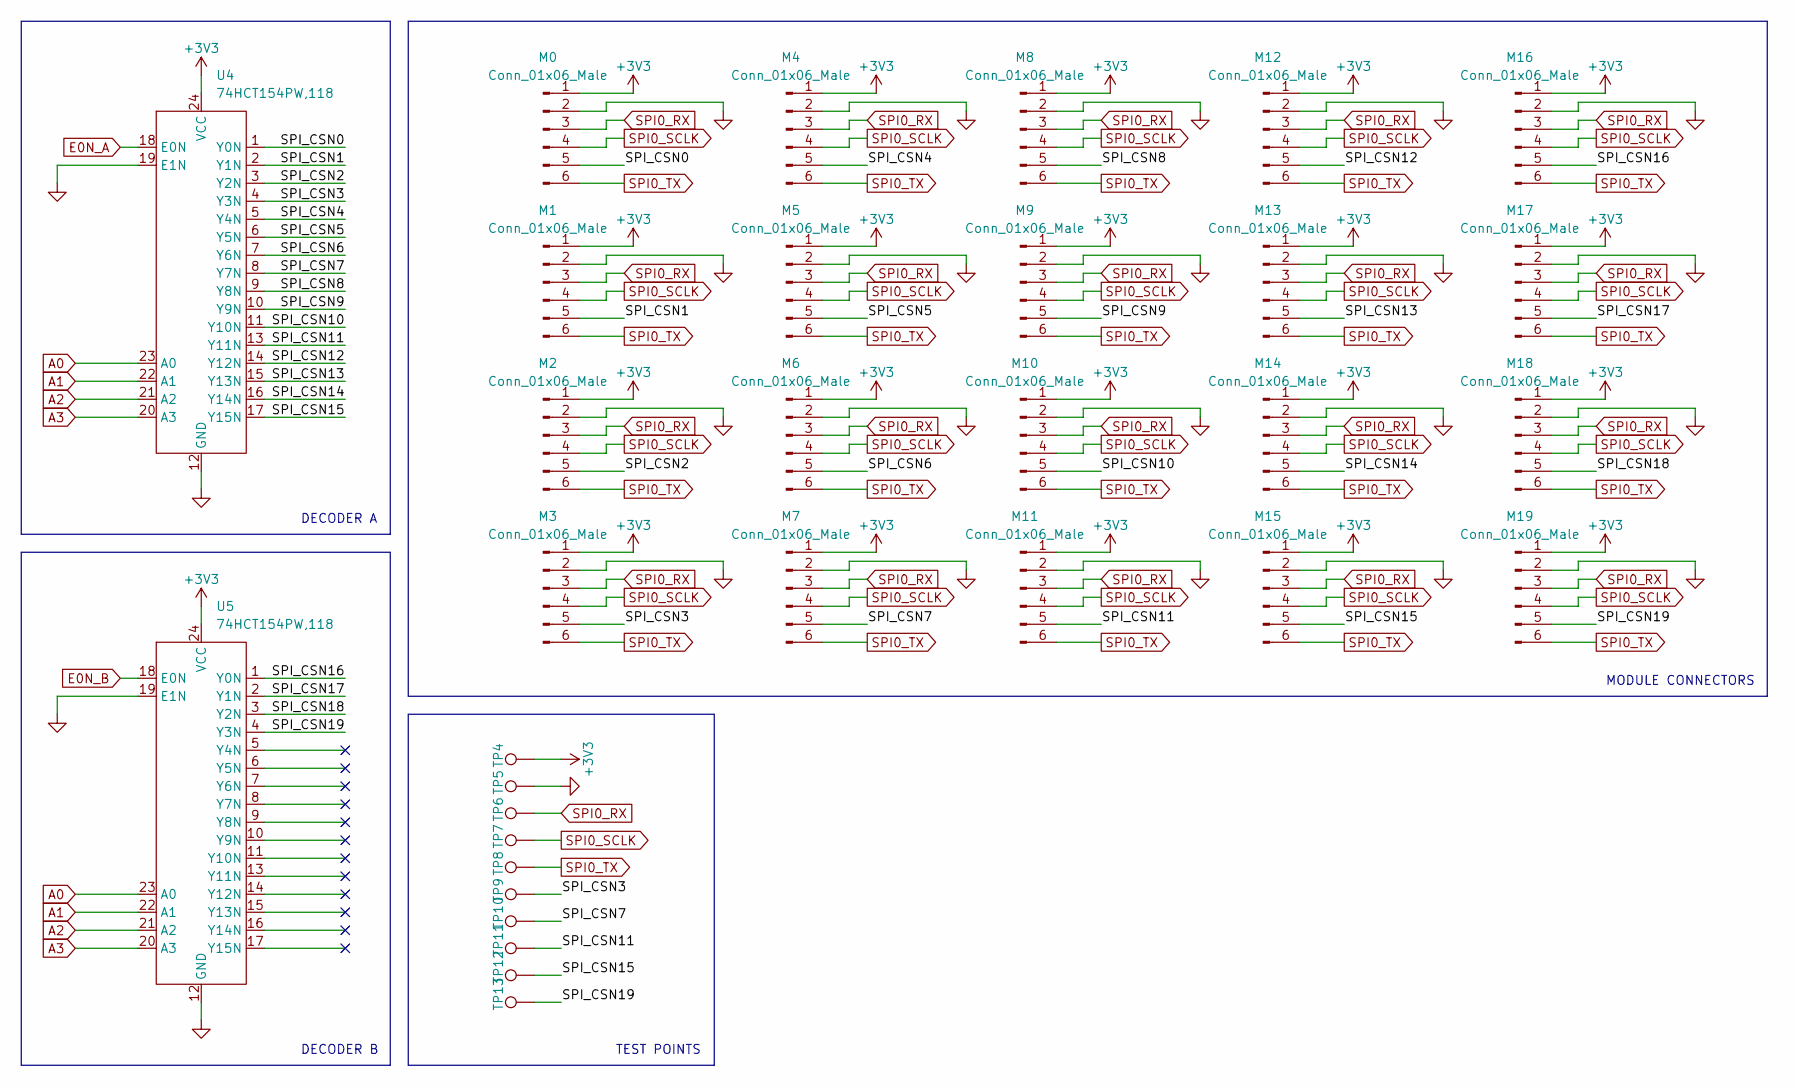
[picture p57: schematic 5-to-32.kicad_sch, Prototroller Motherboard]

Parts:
M0, M1, M2, M3, M4, M5, M6, M7, M8, M9, M10, M11, M12, M13, M14, M15, M16, M17, M18, M19: Conn_01x06_Male; Mag_Pogo_6P_P2.2mm_Female
TP4, TP5, TP6, TP7, TP8, TP9, TP10, TP11, TP12, TP13: TestPoint; TestPoint_Pad_2.5x2.5mm
U4, U5: 74HCT154PW,118; TSSOP-24_4.4x7.8mm_P0.65mm; Manufacturer Part Number 74HCT154PW,118

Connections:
+3V3: M0.1, M1.1, M2.1, M3.1, M4.1, M5.1, M6.1, M7.1, M8.1, M9.1, M10.1, M11.1, M12.1, M13.1, M14.1, M15.1, M16.1, M17.1, M18.1, M19.1, TP4.1, U4.24 (VCC), U5.24 (VCC); also elsewhere on the board
/5-to-32/SPI_CSN0: M0.5, U4.1 (Y0N)
/5-to-32/SPI_CSN1: M1.5, U4.2 (Y1N)
/5-to-32/SPI_CSN2: M2.5, U4.3 (Y2N)
/5-to-32/SPI_CSN3: M3.5, TP9.1, U4.4 (Y3N)
/5-to-32/SPI_CSN4: M4.5, U4.5 (Y4N)
/5-to-32/SPI_CSN5: M5.5, U4.6 (Y5N)
/5-to-32/SPI_CSN6: M6.5, U4.7 (Y6N)
/5-to-32/SPI_CSN7: M7.5, TP10.1, U4.8 (Y7N)
/5-to-32/SPI_CSN8: M8.5, U4.9 (Y8N)
/5-to-32/SPI_CSN9: M9.5, U4.10 (Y9N)
/5-to-32/SPI_CSN10: M10.5, U4.11 (Y10N)
/5-to-32/SPI_CSN11: M11.5, TP11.1, U4.13 (Y11N)
/5-to-32/SPI_CSN12: M12.5, U4.14 (Y12N)
/5-to-32/SPI_CSN13: M13.5, U4.15 (Y13N)
/5-to-32/SPI_CSN14: M14.5, U4.16 (Y14N)
/5-to-32/SPI_CSN15: M15.5, TP12.1, U4.17 (Y15N)
/5-to-32/SPI_CSN16: M16.5, U5.1 (Y0N)
/5-to-32/SPI_CSN17: M17.5, U5.2 (Y1N)
/5-to-32/SPI_CSN18: M18.5, U5.3 (Y2N)
/5-to-32/SPI_CSN19: M19.5, TP13.1, U5.4 (Y3N)
A0: U4.23 (A0), U5.23 (A0); also elsewhere on the board
A1: U4.22 (A1), U5.22 (A1); also elsewhere on the board
A2: U4.21 (A2), U5.21 (A2); also elsewhere on the board
A3: U4.20 (A3), U5.20 (A3); also elsewhere on the board
E0N_A: U4.18 (E0N); also elsewhere on the board
E0N_B: U5.18 (E0N); also elsewhere on the board
GND: M0.2, M1.2, M2.2, M3.2, M4.2, M5.2, M6.2, M7.2, M8.2, M9.2, M10.2, M11.2, M12.2, M13.2, M14.2, M15.2, M16.2, M17.2, M18.2, M19.2, TP5.1, U4.12 (GND), U4.19 (E1N), U5.12 (GND), U5.19 (E1N); also elsewhere on the board
SPI0_RX: M0.3, M1.3, M2.3, M3.3, M4.3, M5.3, M6.3, M7.3, M8.3, M9.3, M10.3, M11.3, M12.3, M13.3, M14.3, M15.3, M16.3, M17.3, M18.3, M19.3, TP6.1; also elsewhere on the board
SPI0_SCLK: M0.4, M1.4, M2.4, M3.4, M4.4, M5.4, M6.4, M7.4, M8.4, M9.4, M10.4, M11.4, M12.4, M13.4, M14.4, M15.4, M16.4, M17.4, M18.4, M19.4, TP7.1; also elsewhere on the board
SPI0_TX: M0.6, M1.6, M2.6, M3.6, M4.6, M5.6, M6.6, M7.6, M8.6, M9.6, M10.6, M11.6, M12.6, M13.6, M14.6, M15.6, M16.6, M17.6, M18.6, M19.6, TP8.1; also elsewhere on the board

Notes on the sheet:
MODULE CONNECTORS
DECODER B
DECODER A
TEST POINTS

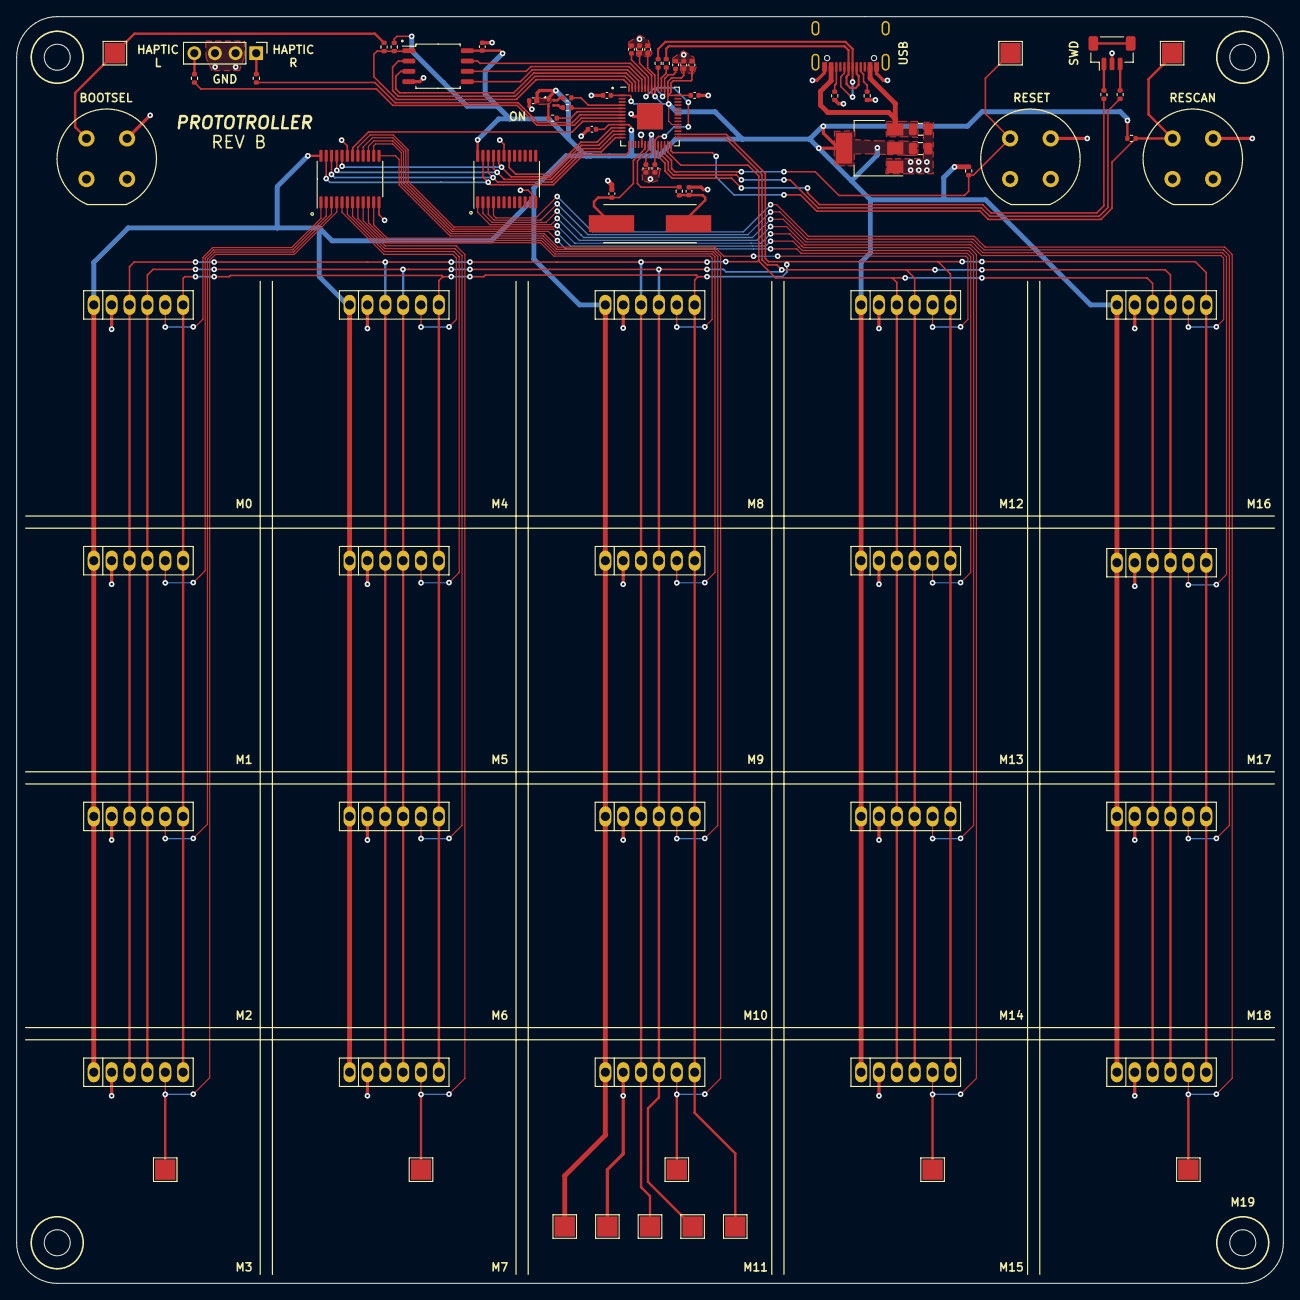
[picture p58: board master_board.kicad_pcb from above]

Board: 2 copper layers, 156.0 x 156.0 mm, 83 parts (0 on the bottom side), 65 nets.

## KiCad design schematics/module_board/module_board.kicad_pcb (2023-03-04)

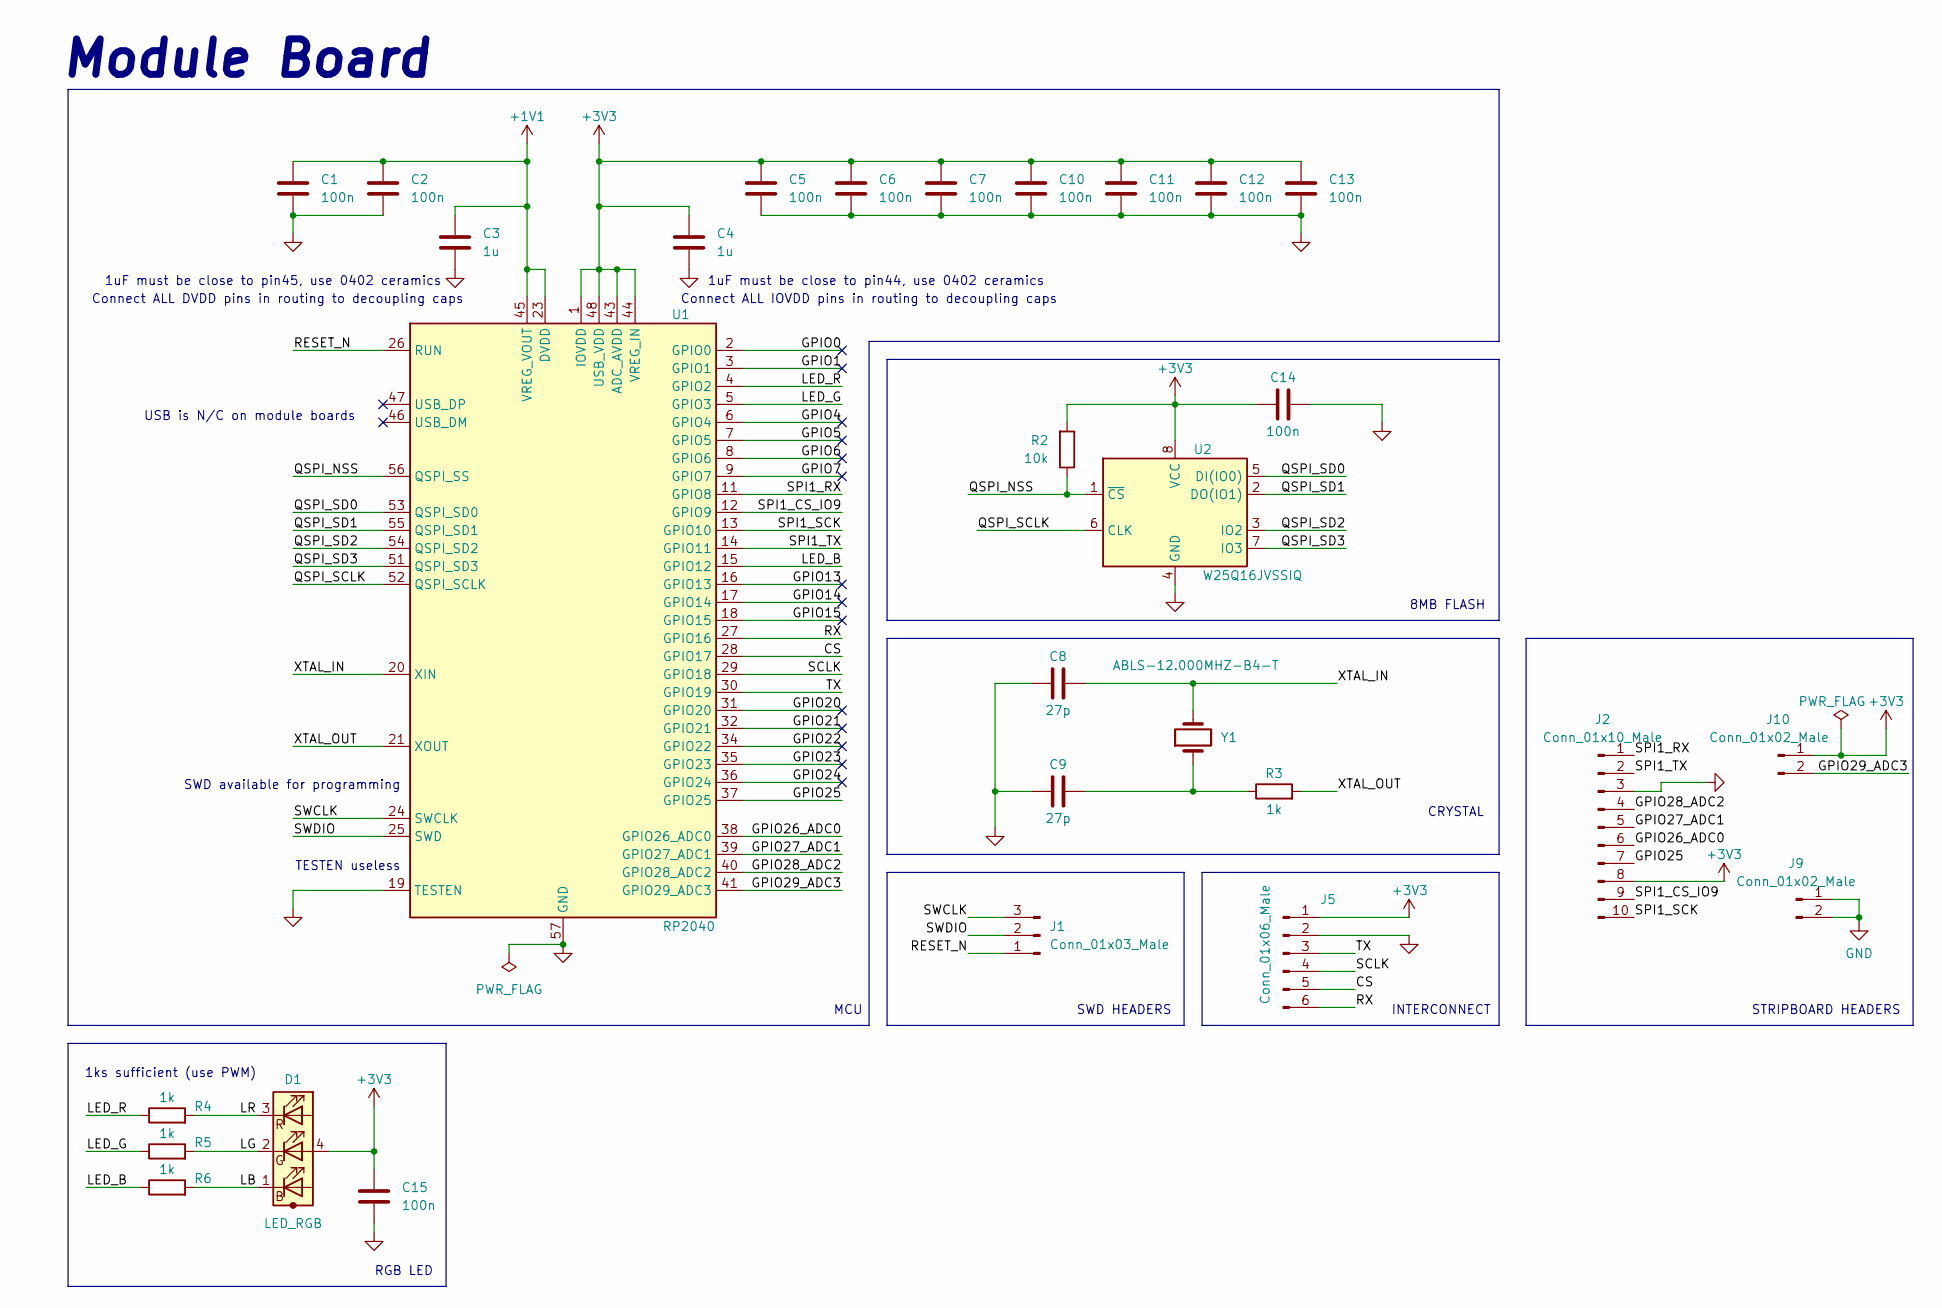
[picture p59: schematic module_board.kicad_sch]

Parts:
C1, C2, C5, C6, C7, C10, C11, C12, C13, C14: 100n; C_0402_1005Metric
C3, C4: 1u; C_0402_1005Metric
C8, C9: 27p; C_0402_1005Metric
C15: 100n; C_0402_1005Metric; Manufacturer Part Number C0402X7R100-104KNE-CT
D1: LED_RGB; LED_Cree-UHD111A; Manufacturer Part Number UHD111A-FKA-C3K23E1L3VG5ZB3Z3
J1: Conn_01x03_Male; PinHeader_1x03_P2.54mm_Vertical
J2: Conn_01x10_Male; PinHeader_1x10_P2.54mm_Vertical
J5: Conn_01x06_Male; Mag_Pogo_6P_P2.2mm_Male
J9, J10: Conn_01x02_Male; PinHeader_1x02_P2.54mm_Vertical
R2: 10k; R_0402_1005Metric
R3: 1k; R_0402_1005Metric
R4, R5, R6: 1k; R_0402_1005Metric; Manufacturer Part Number RC0402FR-7W1KL
U1: RP2040; QFN-56-1EP_7x7mm_P0.4mm_EP3.2x3.2mm
U2: W25Q16JVSSIQ; SOIC-8_5.23x5.23mm_P1.27mm
Y1: ABLS-12.000MHZ-B4-T; XTAL_ABLS-12.000MHZ-B4-T

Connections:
+1V1: C1.1, C2.1, C3.2, U1.23 (DVDD), U1.45 (VREG_VOUT), U1.50 (DVDD)
+3V3: C4.1, C5.1, C6.1, C7.1, C10.1, C11.1, C12.1, C13.1, C14.1, C15.1, D1.4 (A), J2.8, J5.1, J10.1, R2.2, U1.1 (IOVDD), U1.10 (IOVDD), U1.22 (IOVDD), U1.33 (IOVDD), U1.42 (IOVDD), U1.43 (ADC_AVDD), U1.44 (VREG_IN), U1.48 (USB_VDD), U1.49 (IOVDD), U2.8 (VCC)
/CS: J5.5, U1.28 (GPIO17)
/GPIO0: U1.2 (GPIO0)
/GPIO1: U1.3 (GPIO1)
/GPIO4: U1.6 (GPIO4)
/GPIO5: U1.7 (GPIO5)
/GPIO6: U1.8 (GPIO6)
/GPIO7: U1.9 (GPIO7)
/GPIO13: U1.16 (GPIO13)
/GPIO14: U1.17 (GPIO14)
/GPIO15: U1.18 (GPIO15)
/GPIO20: U1.31 (GPIO20)
/GPIO21: U1.32 (GPIO21)
/GPIO22: U1.34 (GPIO22)
/GPIO23: U1.35 (GPIO23)
/GPIO24: U1.36 (GPIO24)
/GPIO25: J2.7, U1.37 (GPIO25)
/GPIO26_ADC0: J2.6, U1.38 (GPIO26_ADC0)
/GPIO27_ADC1: J2.5, U1.39 (GPIO27_ADC1)
/GPIO28_ADC2: J2.4, U1.40 (GPIO28_ADC2)
/GPIO29_ADC3: J10.2, U1.41 (GPIO29_ADC3)
/LB: D1.1 (B), R6.2
/LED_B: R6.1, U1.15 (GPIO12)
/LED_G: R5.1, U1.5 (GPIO3)
/LED_R: R4.1, U1.4 (GPIO2)
/LG: D1.2 (G), R5.2
/LR: D1.3 (R), R4.2
/QSPI_NSS: R2.1, U1.56 (QSPI_SS), U2.1 (~CS)
/QSPI_SCLK: U1.52 (QSPI_SCLK), U2.6 (CLK)
/QSPI_SD0: U1.53 (QSPI_SD0), U2.5 (DI(IO0))
/QSPI_SD1: U1.55 (QSPI_SD1), U2.2 (DO(IO1))
/QSPI_SD2: U1.54 (QSPI_SD2), U2.3 (IO2)
/QSPI_SD3: U1.51 (QSPI_SD3), U2.7 (IO3)
/RESET_N: J1.1, U1.26 (RUN)
/RX: J5.6, U1.27 (GPIO16)
/SCLK: J5.4, U1.29 (GPIO18)
/SPI1_CS_IO9: J2.9, U1.12 (GPIO9)
/SPI1_RX: J2.1, U1.11 (GPIO8)
/SPI1_SCK: J2.10, U1.13 (GPIO10)
/SPI1_TX: J2.2, U1.14 (GPIO11)
/SWCLK: J1.3, U1.24 (SWCLK)
/SWDIO: J1.2, U1.25 (SWD)
/TX: J5.3, U1.30 (GPIO19)
/XTAL_IN: C8.2, U1.20 (XIN), Y1.2
/XTAL_OUT: R3.2, U1.21 (XOUT)
GND: C1.2, C2.2, C3.1, C4.2, C5.2, C6.2, C7.2, C8.1, C9.1, C10.2, C11.2, C12.2, C13.2, C14.2, C15.2, J2.3, J5.2, J9.1, J9.2, U1.19 (TESTEN), U1.57 (GND), U2.4 (GND)
unnamed: C9.2, R3.1, Y1.1

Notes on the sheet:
SWD HEADERS
STRIPBOARD HEADERS
CRYSTAL
TESTEN useless
1uF must be close to pin44, use 0402 ceramics
MCU
RGB LED
8MB FLASH
USB is N/C on module boards
Module Board
1uF must be close to pin45, use 0402 ceramics
Connect ALL DVDD pins in routing to decoupling caps
1ks sufficient (use PWM)
INTERCONNECT
Connect ALL IOVDD pins in routing to decoupling caps
SWD available for programming

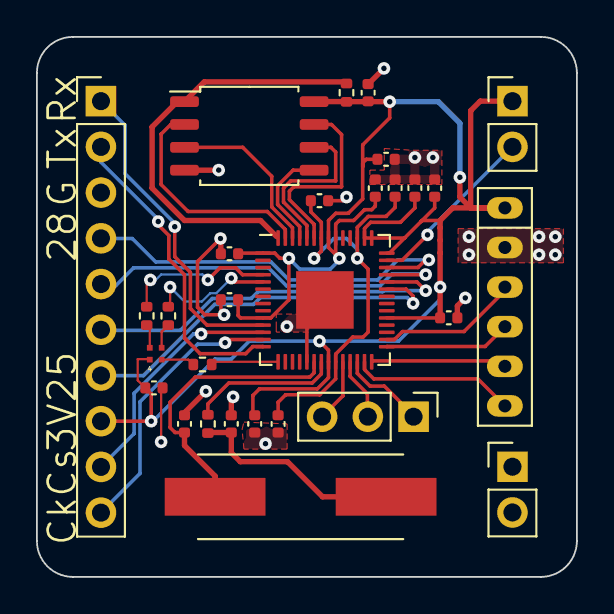
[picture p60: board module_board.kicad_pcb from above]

Board: 2 copper layers, 30.0 x 30.0 mm, 29 parts (0 on the bottom side), 34 nets.

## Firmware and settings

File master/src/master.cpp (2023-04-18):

#include "pico/stdlib.h"
#include "pico/stdio.h"
//#include <stdio.h>
#include <stdlib.h>
#include <cstring>
#include "hardware/adc.h"
#include "../libraries/SPIMaster.h"
#include "usb_descriptors.h"
#include "tusb.h"
#include "bsp/board.h"
#include "../../prototroller.h"
#include "../../commons.h"

// Uncomment to run in debug mode
//#define DEBUG 0

// Uncomment to print out verbose status information to the serial endpoint
//#define VERBOSE_SERIAL 0

//--------------------------------------------------------------------+
// Types and Enums
//--------------------------------------------------------------------+

// Enum for times
enum
{
    BLINK_NOT_MOUNTED = 250,
    BLINK_MOUNTED = 1000,
    BLINK_SUSPENDED = 2500,
    PRINT_REPORT_DELAY = 2000,
};

// Prototroller HID Gamepad Report
typedef struct
{
    uint16_t    digitals;   // Digital inputs (momentary button, maintained button, D-pad, XYAB, etc.)
    int16_t     analogs[8]; // Analog inputs (joystick, slider, twist switch, etc.)
} gamepad_report_t;

// Prototroller CDC Commands
// Commands sent over CDC (Serial) from the host
// Must support the maximum number of output modules overall
typedef struct
{
    uint32_t    digitals;
    int16_t     analogs[20];
} cdc_commands_t;


//--------------------------------------------------------------------+
// Globals
//--------------------------------------------------------------------+

// Gamepad reports
gamepad_report_t gamepad_report[5];

// CDC Command Data Store
cdc_commands_t commands;

// SPI Master
SPIMaster master(
    spi_default,
    MASTER_SPI_TX_PIN,
    MASTER_SPI_RX_PIN,
    MASTER_SPI_SCK_PIN,
    MASTER_SPI_CSN_PIN,
    true
);

// SPI Transaction Buffers
uint8_t out_buf[BUF_LEN],in_buf[BUF_LEN];

// Keep track of error counts
uint8_t error_counts[MAX_MODULES] = {0};

// Module Identification Data Store
moduleID_t module_IDs[MAX_MODULES] = {DISCONNECTED};

// Module Assigned Report Data Store 
assigned_t assigned[MAX_MODULES];

// Analog Averaging data
gamepad_report_t averages;

// Keep track of free (unassigned) axes
// Should extend this to support 5 reports.
bool free_axes[8] = {true};

// Rescan ISR flag
volatile bool rescan = false;

// Rescan debounce timer
volatile unsigned long time = to_ms_since_boot(get_absolute_time());

// Rescan debounce delay (in ms)
const int delay = 50;

// Interval in ms for LED blinking task
static uint32_t blink_interval_ms = BLINK_NOT_MOUNTED;

// Interval in ms for report message task
static uint32_t report_message_interval_ms = PRINT_REPORT_DELAY;

// Track counts as we poll each slot
uint8_t analog_count = 0;
uint8_t digital_count = 0;

//--------------------------------------------------------------------+
// Prototypes
//--------------------------------------------------------------------+

void print_buf(uint8_t buf[], size_t len);
void print_report(uint8_t report_id, gamepad_report_t *report);
void rescan_modules();
void init_gpio();
uint8_t assign_analog_data(gamepad_report_t *column_report, uint8_t analog_count, int16_t *data, uint8_t len);
void send_hid_report(uint8_t report_id);
void tud_mount_cb(void);
void tud_umount_cb(void);
void tud_suspend_cb(bool remote_wakeup_en);
void tud_resume_cb(void);
void tud_hid_report_complete_cb(uint8_t instance, uint8_t const *report, uint16_t len);
uint16_t tud_hid_get_report_cb(uint8_t instance, uint8_t report_id, hid_report_type_t report_type, uint8_t *buffer, uint16_t reqlen);
void tud_hid_set_report_cb(uint8_t instance, uint8_t report_id, hid_report_type_t report_type, uint8_t const* buffer, uint16_t bufsize);
void tud_cdc_line_state_cb(uint8_t itf, bool dtr, bool rts);
void tud_cdc_rx_cb(uint8_t itf);
void rescan_cb(uint gpio, uint32_t events);
void hid_task(void);
void cdc_task(void);
void led_blinking_task(void);
void print_report_task(void);
void modules_task(void);

//--------------------------------------------------------------------+
// Helpers
//--------------------------------------------------------------------+

// Outputs contents of a buffer to standard output.
void print_buf(uint8_t buf[], size_t len)
{
    int i;
    for (i = 0; i < len; ++i) {
        if (i % 16 == 15)
            printf("%02x\n", buf[i]);
        else
            printf("%02x ", buf[i]);
    }

    // append trailing newline if there isn't one
    if (i % 16) {
        putchar('\n');
    }
}

// Outputs contents of a gamepad report to standard output.
void print_report(uint8_t report_id, gamepad_report_t *report)
{
    printf("===========================\n");
    printf("GAMEPAD REPORT FOR VIRTUAL CONTROLLER %01d\n", report_id);
    printf("===========================\n");

    printf("DIGITALS       : 0x%04x (%u)\n", report->digitals, report->digitals);

    printf("ANALOGS[0..7]  ");
    for(unsigned int i = 0; i < (sizeof(report->analogs) / sizeof(report->analogs[0])); i++)
    {
        printf(": 0x%04x (%d)", (unsigned int)(uint16_t)report->analogs[i], report->analogs[i]);
    }

    printf("\n\n");
}

// Rescans for connected modules and update identification.
void rescan_modules()
{
    // Reset all axes to free
    memset(free_axes, 1, 8*sizeof(bool));

    // Start assigning axes and buttons on report 0
    //uint8_t report_num = 0;

    button_idx_t button_idx = 0;
    axis_idx_t axis0 = X;
    axis_idx_t axis1 = Y;

    printf("[!] Rescanning for active modules...\n");
    for(uint8_t module = 0; module < MAX_MODULES; module++)
    {
        // Select the current (potentially connected) module
        master.SlaveSelect(module);

        // Attempt to identify module currently selected
        moduleID_t identification = (moduleID_t) master.MasterIdentify();

        // Deselect the module
        master.SlaveSelect(NO_SLAVE_SELECTED_CSN);

        // Update the module identification in the internal data store
        module_IDs[module] = identification;

        char status = (identification == DISCONNECTED) ? 'x' : '!';

        printf("[%c] Module %u is identified as ", status, module);
        printf(module_names[identification]);
        printf(".\n");

        if(identification != DISCONNECTED)
        {
            // Assign position in the HID report
            // TODO: Expand to use all 5 reports, not just the first one
            assigned[module].report_num = 0;

            switch(identification)
            {
                case BUTTON_MAINTAINED:
                case BUTTON_MOMENTARY:
                    // Buttons are assigned FCFS, 0 through 15
                    assigned[module].button0 = button_idx;
                    button_idx += 1;
                    break;

                case XYAB:
                case DPAD:
                    assigned[module].button0 = button_idx;
                    assigned[module].button1 = button_idx+1;
                    assigned[module].button2 = button_idx+2;
                    assigned[module].button3 = button_idx+3;
                    button_idx += 4;
                    break;

                case JOYSTICK:
                    if(free_axes[X] && free_axes[Y]) // Left joystick
                    {
                        axis0 = X;
                        axis1 = Y;
                    }
                    else if(free_axes[Z] && free_axes[RX]) // Right joystick
                    {
                        axis0 = Z;
                        axis1 = RX;
                    }
                    else if(free_axes[RY] && free_axes[RZ]) // Backup 1
                    {
                        axis0 = RY;
                        axis1 = RZ;
                    }
                    else if(free_axes[SLIDER0] && free_axes[SLIDER1]) // Backup 2
                    {
                        axis0 = SLIDER0;
                        axis1 = SLIDER1;
                    }
                    else // Not enough axes
                    {
                        // TODO: Wrap to next report
                        axis0 = X;
                        axis1 = Y;
                    }
                    assigned[module].axis0 = axis0;
                    assigned[module].axis1 = axis1;
                    free_axes[axis0] = false;
                    free_axes[axis1] = false;
                    break;

                case SLIDER:
                    if(free_axes[SLIDER0])
                        axis0 = SLIDER0;
                    else if(free_axes[SLIDER1])
                        axis0 = SLIDER1;
                    else if(free_axes[RY])
                        axis0 = RY;
                    else if(free_axes[RZ])
                        axis0 = RZ;
                    else if(free_axes[Z])
                        axis0 = Z;
                    else if(free_axes[RX])
                        axis0 = RX;
                    else if(free_axes[X])
                        axis0 = X;
                    else if(free_axes[Y])
                        axis0 = Y;
                    else // Not enough axes.
                    {
                        // TODO: Wrap to next report
                        axis0 = SLIDER0;
                    }
                    assigned[module].axis0 = axis0;
                    free_axes[axis0] = false;
                    break;

                case TWIST_SWITCH:
                    if(free_axes[RY])
                        axis0 = RY;
                    else if(free_axes[RZ])
                        axis0 = RZ;
                    else if(free_axes[SLIDER0])
                        axis0 = SLIDER0;
                    else if(free_axes[SLIDER1])
                        axis0 = SLIDER1;
                    else if(free_axes[Z])
                        axis0 = Z;
                    else if(free_axes[RX])
                        axis0 = RX;
                    else if(free_axes[X])
                        axis0 = X;
                    else if(free_axes[Y])
                        axis0 = Y;
                    else // Not enough axes.
                    {
                        // TODO: Wrap to next report
                        axis0 = RY;
                    }
                    assigned[module].axis0 = axis0;
                    free_axes[axis0] = false;
                    break;

                case ACCEL:
                    // <unimplemented>
                    break;

                case GYRO:
                    // <unimplemented>
                    break;

                default:
                    break;
            }
        }
    }

    // Rescan finished, so reset the flag
    rescan = false;
}

// Initializes GPIO and setup interrupts
void init_gpio()
{
    // Initialize GPIO for SPI CSNs (Decoder Addresses + Decoder Enables)
    for(uint8_t pin = MASTER_EONA_PIN; pin <= MASTER_A0_PIN; pin++)
    {
        gpio_init(pin);
        gpio_set_dir(pin, true);
        gpio_set_pulls(pin, false, false);
        gpio_put(pin, 1);
    }
    for(uint8_t pin = MASTER_CSN_START_PIN; pin <= MASTER_CSN_END_PIN; pin++)
    {
        gpio_init(pin);
        gpio_set_dir(pin, true);
        gpio_set_pulls(pin, false, false);
        gpio_put(pin, 1);
    }

    // Initialize GPIO for rescan button
    gpio_init(MASTER_RESCAN_PIN);
    gpio_set_dir(MASTER_RESCAN_PIN, false);
    gpio_set_pulls(MASTER_RESCAN_PIN, false, false);

    // Initialize GPIO for LEDs
    gpio_init(MASTER_LED_R_PIN);
    gpio_set_dir(MASTER_LED_R_PIN, GPIO_OUT);
    gpio_set_pulls(MASTER_LED_R_PIN, false, false);
    gpio_put(MASTER_LED_R_PIN, 1);

    gpio_init(MASTER_LED_G_PIN);
    gpio_set_dir(MASTER_LED_G_PIN, GPIO_OUT);
    gpio_set_pulls(MASTER_LED_G_PIN, false, false);
    gpio_put(MASTER_LED_G_PIN, 1);

    gpio_init(MASTER_LED_B_PIN);
    gpio_set_dir(MASTER_LED_B_PIN, GPIO_OUT);
    gpio_set_pulls(MASTER_LED_B_PIN, false, false);
    gpio_put(MASTER_LED_B_PIN, 1);

    // Setup the rescan callback
    gpio_set_irq_enabled_with_callback(
        MASTER_RESCAN_PIN,
        GPIO_IRQ_EDGE_RISE,
        true,
        &rescan_cb
    );

    #if defined(DEBUG)
    gpio_init(15);
    gpio_set_dir(15, false);
    gpio_set_pulls(15, false, false);

    adc_init();
    adc_gpio_init(26);
    adc_select_input(0);

    gpio_init(20);
    gpio_set_dir(20, true);
    gpio_set_pulls(20, false, false);
    gpio_put(20, true);

    gpio_init(21);
    gpio_set_dir(21, true);
    gpio_set_pulls(21, false, false);
    gpio_put(21, true);

    gpio_init(22);
    gpio_set_dir(22, true);
    gpio_set_pulls(22, false, false);
    gpio_put(22, true);
    #endif
}

// Assign analog data to the specified report, clamping at the maximum allowed axes
uint8_t assign_analog_data(gamepad_report_t *gamepad_report, uint8_t cnt, int16_t *data, uint8_t len)
{
    // Calculate the maximum number of axes
    uint8_t max = sizeof(gamepad_report->analogs) / sizeof(gamepad_report->analogs[0]);

    // If the total number of axes will surpass the limit, then clamp it
    if((cnt + len) > max)
    {
        len = max - cnt;
    }

    // Assign the data
    for(uint8_t i = 0; i < len; i++)
    {
        gamepad_report->analogs[cnt+i] = data[i];
    }
    
    // Return the new analog count
    return cnt + len;
}

// Send a gamepad report for the report id / virtual controller
void send_hid_report(uint8_t report_id)
{
    // Skip sending this report if the HID endpoint is not ready
    if ( !tud_hid_ready() ) return;

    // Send the appropraite gamepad report based on the report ID
    switch(report_id)
    {
        case REPORT_ID_0:
        {
            tud_hid_report(REPORT_ID_0, gamepad_report, sizeof(gamepad_report_t));
        }
        break;

        case REPORT_ID_1:
        {
            tud_hid_report(REPORT_ID_1, gamepad_report+1, sizeof(gamepad_report_t));
        }
        break;

        case REPORT_ID_2:
        {
            tud_hid_report(REPORT_ID_2, gamepad_report+2, sizeof(gamepad_report_t));
        }
        break;

        case REPORT_ID_3:
        {
            tud_hid_report(REPORT_ID_3, gamepad_report+3, sizeof(gamepad_report_t));
        }
        break;

        case REPORT_ID_4:
        {
            tud_hid_report(REPORT_ID_4, gamepad_report+4, sizeof(gamepad_report_t));
        }
        break;

        default: break;
    }
}


//--------------------------------------------------------------------+
// Callbacks
//--------------------------------------------------------------------+

// Invoked when USB device is mounted
void tud_mount_cb(void)
{
  blink_interval_ms = BLINK_MOUNTED;
}

// Invoked when USB device is unmounted
void tud_umount_cb(void)
{
  blink_interval_ms = BLINK_NOT_MOUNTED;
}

// Invoked when USB bus is suspended
// remote_wakeup_en : if host allow us to perform remote wakeup
// Within 7ms, device must draw an average of current less than 2.5 mA from bus
void tud_suspend_cb(bool remote_wakeup_en)
{
  (void)remote_wakeup_en;
  blink_interval_ms = BLINK_SUSPENDED;
}

// Invoked when USB bus is resumed
void tud_resume_cb(void)
{
  blink_interval_ms = BLINK_MOUNTED;
}

// Invoked when a gamepad report is successfully sent to host
// Note: For composite reports, report[0] is report ID
void tud_hid_report_complete_cb(uint8_t instance, uint8_t const *report, uint16_t len)
{
    (void)instance;
    (void)len;

    uint8_t next_report_id = report[0] + 1u;

    // Report 0 always sent. If we don't have data to send on the other reports... don't send the reports!
    if(next_report_id == REPORT_ID_1 && (analog_count <= 8  && digital_count <= 16)) return;
    if(next_report_id == REPORT_ID_2 && (analog_count <= 16 && digital_count <= 32)) return;
    if(next_report_id == REPORT_ID_3 && (analog_count <= 24 && digital_count <= 48)) return;
    if(next_report_id == REPORT_ID_4 && (analog_count <= 32 && digital_count <= 64)) return;

    if (next_report_id < REPORT_ID_COUNT)
    {
        send_hid_report(next_report_id);
    }
}

// Invoked when received GET_REPORT control request
// Application must fill buffer report's content and return its length.
// Return zero will cause the stack to STALL request
uint16_t tud_hid_get_report_cb(uint8_t instance, uint8_t report_id, hid_report_type_t report_type, uint8_t *buffer, uint16_t reqlen)
{
    // TODO not implemented
    (void)instance;
    (void)report_id;
    (void)report_type;
    (void)buffer;
    (void)reqlen;

    return 0;
}

// Invoked when received SET_REPORT control request or
// received data on OUT endpoint ( Report ID = 0, Type = 0 )
void tud_hid_set_report_cb(uint8_t instance, uint8_t report_id, hid_report_type_t report_type, uint8_t const* buffer, uint16_t bufsize)
{
    // TODO not implemented
    (void) instance;
}

// Invoked when cdc when line state changed e.g connected/disconnected
void tud_cdc_line_state_cb(uint8_t itf, bool dtr, bool rts)
{
    (void) itf;
    (void) rts;

    if ( dtr )
    {
        // Terminal connected
    }
    else
    {
        // Terminal disconnected
    }
}

// Invoked when CDC interface received data from host
void tud_cdc_rx_cb(uint8_t itf)
{
    (void) itf;
}

// Invoked when the user presses rescan button. Debounced to the value of delay.
void rescan_cb(uint gpio, uint32_t events)
{
    if((to_ms_since_boot(get_absolute_time()) - time) > delay && !rescan)
    {
        // Set the interrupt time
        time = to_ms_since_boot(get_absolute_time());

        // Set the rescan interrupt flag
        rescan = true;
    }
}


//--------------------------------------------------------------------+
// Tasks
//--------------------------------------------------------------------+

// Task to kick-off the HID report chain
void hid_task(void)
{
    // Poll every 10ms
    // Must be longer than it takes to send all 5 reports
    const uint32_t interval_ms = 10;
    static uint32_t start_ms = 0;

    if ( board_millis() - start_ms < interval_ms) return;

    start_ms += interval_ms;

    // Remote wakeup
    if ( tud_suspended() )
    {
        // Wake up host if we are in suspend mode and REMOTE_WAKEUP feature is enabled by host
        tud_remote_wakeup();
    }
    else
    {
        // Kick-off the report chain here, starting with the first gamepad report
        send_hid_report(REPORT_ID_0);
    }
}

// Task to process CDC data
void cdc_task(void)
{
    // The serial interface receiving commands from host
    uint8_t itf_rx = 1;

    // The serial interface transmitting output to host
    uint8_t itf_tx = 0;

    if( tud_cdc_n_connected(itf_rx) )
    {
        // Connected
        if( tud_cdc_n_available(itf_rx) )
        {
            // Data available
            char buf[64];

            // Tokenized data
            char tokens[3][64];

            // Read
            uint32_t count = tud_cdc_n_read(itf_rx, buf, sizeof(buf));

            // Tokenize
            char *token;
            token = strtok(buf, " ");
            uint8_t index = 0;
            
            // Extract 3 tokens at most from the buffer
            while(token != NULL && index < 3)
            {
                strcpy(tokens[index++], token);
                token = strtok(NULL, " ");
            }

            if(strcmp(tokens[0], "digital") == 0)
            {
                int module = atoi(tokens[1]);
                int value = atoi(tokens[2]);
                if(module >= 0 && module <= 19)
                {
                    if(value == 0)
                    {
                        commands.digitals &= ~(1 << module);
                    }
                    else if(value == 1)
                    {
                        commands.digitals |= (1 << module);
                    }
                }
            }
            else if(strcmp(tokens[0], "analog") == 0)
            {
                int module = atoi(tokens[1]);
                int value = atoi(tokens[2]);

                if(module >= 0 && module <= 19)
                {
                    commands.analogs[module] = value;
                }
            }
            else if(strcmp(tokens[0], "resetd") == 0)
            {
                commands.digitals = 0;
            }
            else if(strcmp(tokens[0], "reseta") == 0)
            {
                memset(commands.analogs, 0, sizeof(commands.analogs));
            }
            else if(strcmp(tokens[0], "reset") == 0)
            {
                memset(&commands, 0, sizeof(cdc_commands_t));
            }

            // Echo back
            //tud_cdc_n_write(itf_tx, buf, count);
 
            // Flush
            //tud_cdc_n_write_flush(itf_tx);

        }
    }
}
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
int main() {
    // Sleep for module initialization and time to setup serial console
    //sleep_ms(5000);
    // NOTE: leaving this uncommented is probably why we sometimes see no connected
    // modules on reset, because we aren't giving the mod boards enough time to set up
    // and wait for master to initiate a SPI transaction.
    
    // Initialize the board
    board_init();
    // NOTE: what exactly this does could use some further investigation

    // Initialize TinyUSB
    tud_init(BOARD_TUD_RHPORT);
    // NOTE: sleeps after tusb_init() or tud_init() appear to cause the USB mount to fail.

    // Initialize standard I/O
    //stdio_init_all(); // Use w/o TinyUSB
    stdio_usb_init(); // Use w/ TinyUSB
    printf("MASTER INITIALIZATION PROCEDURE\n");
    printf("===============================\n");

    // Initialize SPI
    master.MasterInit();
    printf("[!] Master SPI Initialized\n");

    // Initialize GPIO
    init_gpio();
    printf("[!] Master GPIO Initialized\n");

    // Initial scan for modules
    //rescan_modules();
    
    // Infinite task loop
    while(true) {
        tud_task();

        modules_task();

        #if defined(DEBUG)
        led_blinking_task();
        #endif

        print_report_task();

        hid_task();
        
        cdc_task();
    }
}

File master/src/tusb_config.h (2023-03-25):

/*
 * The MIT License (MIT)
 *
 * Copyright (c) 2019 Ha Thach (tinyusb.org)
 *
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
 */

#ifndef _TUSB_CONFIG_H_
#define _TUSB_CONFIG_H_

#ifdef __cplusplus
 extern "C" {
#endif

//--------------------------------------------------------------------
// COMMON CONFIGURATION
//--------------------------------------------------------------------

// defined by board.mk
#ifndef CFG_TUSB_MCU
  #error CFG_TUSB_MCU must be defined
#endif

// RHPort number used for device can be defined by board.mk, default to port 0
#ifndef BOARD_DEVICE_RHPORT_NUM
  #define BOARD_DEVICE_RHPORT_NUM     0
#endif

#ifndef BOARD_TUD_RHPORT
#define BOARD_TUD_RHPORT      0
#endif

// RHPort max operational speed can defined by board.mk
// Default to Highspeed for MCU with internal HighSpeed PHY (can be port specific), otherwise FullSpeed
#ifndef BOARD_DEVICE_RHPORT_SPEED
  #if (CFG_TUSB_MCU == OPT_MCU_LPC18XX || CFG_TUSB_MCU == OPT_MCU_LPC43XX || CFG_TUSB_MCU == OPT_MCU_MIMXRT10XX || \
       CFG_TUSB_MCU == OPT_MCU_NUC505  || CFG_TUSB_MCU == OPT_MCU_CXD56 || CFG_TUSB_MCU == OPT_MCU_SAMX7X)
    #define BOARD_DEVICE_RHPORT_SPEED   OPT_MODE_HIGH_SPEED
  #else
    #define BOARD_DEVICE_RHPORT_SPEED   OPT_MODE_FULL_SPEED
  #endif
#endif

// Device mode with rhport and speed defined by board.mk
#if   BOARD_DEVICE_RHPORT_NUM == 0
  #define CFG_TUSB_RHPORT0_MODE     (OPT_MODE_DEVICE | BOARD_DEVICE_RHPORT_SPEED)
#elif BOARD_DEVICE_RHPORT_NUM == 1
  #define CFG_TUSB_RHPORT1_MODE     (OPT_MODE_DEVICE | BOARD_DEVICE_RHPORT_SPEED)
#else
  #error "Incorrect RHPort configuration"
#endif


#ifndef CFG_TUSB_OS
#define CFG_TUSB_OS               OPT_OS_NONE
#endif

// CFG_TUSB_DEBUG is defined by compiler in DEBUG build
// #define CFG_TUSB_DEBUG           0

/* USB DMA on some MCUs can only access a specific SRAM region with restriction on alignment.
 * Tinyusb use follows macros to declare transferring memory so that they can be put
 * into those specific section.
 * e.g
 * - CFG_TUSB_MEM SECTION : __attribute__ (( section(".usb_ram") ))
 * - CFG_TUSB_MEM_ALIGN   : __attribute__ ((aligned(4)))
 */
#ifndef CFG_TUSB_MEM_SECTION
#define CFG_TUSB_MEM_SECTION
#endif

#ifndef CFG_TUSB_MEM_ALIGN
#define CFG_TUSB_MEM_ALIGN          __attribute__ ((aligned(4)))
#endif

//--------------------------------------------------------------------
// DEVICE CONFIGURATION
//--------------------------------------------------------------------

#ifndef CFG_TUD_ENDPOINT0_SIZE
#define CFG_TUD_ENDPOINT0_SIZE    64
#endif

//------------- CLASS -------------//
#define CFG_TUD_HID               1
#define CFG_TUD_CDC               2
#define CFG_TUD_MSC               0
#define CFG_TUD_MIDI              0
#define CFG_TUD_VENDOR            0

// HID buffer size Should be sufficient to hold ID (if any) + Data
#define CFG_TUD_HID_EP_BUFSIZE    64

//#define CFG_TUD_CDC_RX_BUFSIZE   (TUD_OPT_HIGH_SPEED ? 512 : 64)
//#define CFG_TUD_CDC_TX_BUFSIZE   (TUD_OPT_HIGH_SPEED ? 512 : 64)
#define CFG_TUD_CDC_RX_BUFSIZE   64
#define CFG_TUD_CDC_TX_BUFSIZE   64

#ifdef __cplusplus
 }
#endif

#endif /* _TUSB_CONFIG_H_ */

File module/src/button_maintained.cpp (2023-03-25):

#include <stdio.h>
#include <string.h>
#include "pico/stdlib.h"
#include "pico/binary_info.h"
#include "../libraries/SPISlave.h"
#include "../../prototroller.h"
#include "../../commons.h"

#define moduleID BUTTON_MAINTAINED

SPISlave spi(
    spi_default,
    MODULE_SPI_TX_PIN,
    MODULE_SPI_RX_PIN,
    MODULE_SPI_SCK_PIN,
    MODULE_SPI_CSN_PIN,
    moduleID
);

// Declare and initialize buffers
uint8_t out_buf[BUF_LEN] = {0};
uint8_t in_buf[BUF_LEN] = {0};

int main() {
    // Initialize SPI as a slave
    spi.SlaveInit();

    // Initialize the active-low button GPIO
    gpio_init(MODULE_MAINTAINED_BUTTON_PIN);
    gpio_set_dir(MODULE_MAINTAINED_BUTTON_PIN, GPIO_IN);
    gpio_set_pulls(MODULE_MAINTAINED_BUTTON_PIN, false, false);

    // Wait for identification
    spi.SlaveReadWrite(out_buf, in_buf, BUF_LEN);

    // After identifier is sent, continually send the GPIO state
    while(true)
    {
        // Get the active-low button state
        bool button_state = gpio_get(MODULE_MAINTAINED_BUTTON_PIN);

        // Set the first byte to the button state
        out_buf[0] = button_state;

        spi.SlaveReadWrite(out_buf, in_buf, BUF_LEN);
    }

}

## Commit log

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2022-11-18 Fix out-of-sync data packets
    [joystick.cpp]
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2023-01-23 Created KiCad Directories
    [master_board.kicad_pcb, master_board.kicad_sch, module_board.kicad_pcb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]
2023-01-23 Added 5-to-32 Decoder
    [5_32_decoder.kicad_pcb, 5_32_decoder.kicad_sch]
2023-01-23 Added USB-C, LDO, SWD
    [master_board.kicad_sch, module_board.kicad_sch]
2023-01-23 oscillator and flash memory
    [Crystal_Oscillator.kicad_pcb, Crystal_Oscillator.kicad_sch, Flash_Memory_8MB.kicad_pcb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]
2023-01-25 Added reset tactile switch, pulled up
    [master_board.kicad_sch]
2023-01-25 Added Accelerometer/Gyroscope Component
    [master_board.kicad_sch]
2023-01-26 Add MCU to module board schematic
    [module_board.kicad_sch]
2023-01-26 Added switch and slider components
    [module_board.kicad_sch]
2023-01-27 Consolidated board segments into corresponding board schematic & annotated components
    [master_board.kicad_sch, module_board.kicad_sch]
2023-01-27 Added XYBA Buttons/D-Pad onto module_board.kicad_sch
    [module_board.kicad_sch]
2023-01-27 Fixed oscillator and flash labels
    [master_board.kicad_sch, module_board.kicad_pcb]
2023-01-27 updated crystal oscillator
    [Crystal_Oscillator.kicad_sch, Flash_Memory_8MB.kicad_sch]
2023-02-01 Update master schematics
    [5-to-32.kicad_sch, master_board.kicad_sch]
2023-02-02 updated crystal oscillator and flash memory on module board
    [Crystal_Oscillator.kicad_sch, Flash_Memory_8MB.kicad_sch, module_board.kicad_sch]
2023-02-02 Add haptic feedback to master board
    [5-to-32.kicad_sch, master_board.kicad_sch]
2023-02-02 updated footprint for module board
    [Crystal_Oscillator.kicad_sch, master_board.kicad_sch, module_board.kicad_sch]
2023-02-02 Separated Module Components
    [module_board.kicad_sch, module_components.kicad_pcb, module_components.kicad_sch]
2023-02-02 Assigned master board footprints
    [5-to-32.kicad_sch, master_board.kicad_sch]
2023-02-02 Updated Footprints, started PCB design
    [module_board.kicad_pcb, module_board.kicad_sch]
2023-02-02 Footprint integration
    [5-to-32.kicad_sch, master_board.kicad_sch]
2023-02-03 Added footprints to resistors, capcacitors, potentiometers, etc.
    [master_board.kicad_sch, module_components.kicad_sch]
2023-02-03 Modified flash footprint
    [module_board.kicad_sch]
2023-02-05 Master board connectors and ERC
    [5-to-32.kicad_sch, master_board.kicad_sch]
2023-02-07 Updated Schematic Nets, added Jumper
    [module_board.kicad_sch]
2023-02-07 Completed non-routed Rough PCB Draft
    [module_board.kicad_pcb]
2023-02-07 Update footprints
    [5-to-32.kicad_sch, master_board.kicad_sch]
2023-02-07 Completed PCB Routing, Reassigned Pins, Assigned Pogo Footprint
    [module_board.kicad_pcb, module_board.kicad_sch]
2023-02-08 Initial master board placement
    [3220-10-0300-00 3D.stp, 868-10-006-00-011101.step, 868-22-006-00-011101.step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]
2023-02-08 Added 3D models for Crystal Oscillator and flash
    [XTAL_ABLS_ABR.step, module_board.kicad_pcb]
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2023-02-08 Fixed copper plates
    [module_board.kicad_pcb]
2023-02-09 Finalize master board placement, begin routing
    [master_board.kicad_pcb, master_board.kicad_sch]
2023-02-10 Adjusted Module Board, fixed majority of DRC errors/warnings
    [module_board.kicad_pcb]
2023-02-10 Route master board and DRC
    [5-to-32.kicad_sch, master_board.kicad_pcb, master_board.kicad_sch]
2023-02-10 Master board finishing touches
    [master_board.kicad_pcb, master_board.kicad_sch]
2023-02-10 bom generation script
    [5-to-32.kicad_sch, master_board.kicad_sch]
2023-02-10 Add footprint library to project options
    [module_board.kicad_sch]
2023-02-10 Update project symbol table
    [module_board.kicad_sch]
2023-02-10 Added relative paths to 3D models on module_board
    [module_board.kicad_pcb]
2023-02-10 Module updates
    [module_board.kicad_pcb, module_board.kicad_sch]
2023-02-11 Added 2.54mm pitch male headers for SPI1 pins and ADC pins
    [module_board.kicad_pcb, module_board.kicad_sch]
2023-02-11 Mod board finalizations
    [module_board.kicad_pcb, module_board.kicad_sch]
2023-02-13 Modified .gitignore, shifted all master_board pogo-pins down 1.5mm
    [master_board.kicad_pcb]
2023-02-13 improve clearance on module board edges
    [module_board.kicad_pcb, module_board.kicad_sch]
2023-02-14 Final improvements
    [master_board.kicad_pcb, module_board.kicad_pcb]
2023-02-14 Shifted pogo-pins up by 0.25mm
    [master_board.kicad_pcb]
2023-02-14 board gerbers
    [master_board-B_Cu.gbr, master_board-B_Mask.gbr, master_board-B_Paste.gbr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]
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2023-02-21 enclosure models, thanks Leo
    [chassis.stl, chassis_lid.stl, enclosure.stl]
2023-03-01 Changed 10k res values to 1k, SWD pins, Decoder footprints, and haptic pins
    [5-to-32.kicad_sch, master_board.kicad_pcb, master_board.kicad_sch]
2023-03-01 Minor alignment with male 1-4 pins
    [master_board.kicad_pcb]
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2023-03-02 directory naming conventions
    [3220-10-0300-00 3D.stp, 5-to-32.kicad_sch, 5_32_decoder.kicad_pcb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]
2023-03-02 rev a directory refactoring
    [5-to-32.kicad_sch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]
2023-03-02 directory fixes
    [5-to-32.kicad_sch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]
2023-03-02 Added LED to Module Board
    [module_board.kicad_pcb, module_board.kicad_sch]
2023-03-02 initial master board rev b
    [5-to-32.kicad_sch, master_board.kicad_pcb, master_board.kicad_sch]
2023-03-03 square test points, fix up routing
    [5-to-32.kicad_sch, master_board.kicad_pcb, master_board.kicad_sch]
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2023-03-04 master board rev b touchups
    [module_board.kicad_pcb, module_board.kicad_sch]
2023-03-04 add gerbers
    [master_board-B_Cu.gbr, master_board-B_Mask.gbr, master_board-B_Paste.gbr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]
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2023-03-23 Added Error Recovery Behavior
    [master.cpp]
2023-04-03 Chassis v0 STL Files
    [Chassis_Bottom_v0.stl, Chassis_Handle_L_v0.stl, Chassis_Handle_R_v0.stl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]
2023-04-04 Added Open Variants of Module Enclosures
    [1x1_module_open_v0.stl, 2x1_module_open_v0.stl]
2023-04-07 Updated interior dimensions to 160x160
    [Chassis_Bottom_v1.stl, Chassis_Top_v1.stl]
2023-04-14 Updated Dimensions based on Lab Testing,Added M3 Screw Bores
    [1x1_module_open_v1.stl, 2x1_module_open_v1.stl, Chassis_Bottom_v2.stl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]
2023-04-14 Added Enclosure Project File
    [Master Enclosure v13.f3d]

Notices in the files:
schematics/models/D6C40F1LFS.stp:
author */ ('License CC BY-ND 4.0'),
